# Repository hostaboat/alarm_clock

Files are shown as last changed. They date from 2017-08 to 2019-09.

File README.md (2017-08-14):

# Alarm Clock

## An alarm clock, timer and music player using a Teensy 3.2 and various Adafruit breakout boards.

Many thanks to: 
* **Paul Stoffregen** for the [Teensy 3.2](https://www.pjrc.com/teensy) development board, supporting code base (from which I used as a reference along with the Freescale documentation) and [command line loader](https://github.com/PaulStoffregen/teensy_loader_cli) program which allowed me to develop and test sans the Arduino IDE.
* **Daniel Garcia** for the [FastLED](http://fastled.io) library from which I borrowed.
* [Adafruit](https://www.adafruit.com) for the various breakout boards used.
* [OSH Park](https://oshpark.com) for providing their community PCB service.
* [Othermachine](https://othermachine.co) for the Othermill used to create the enclosure.

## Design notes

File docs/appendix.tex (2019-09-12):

\part*{Appendix}
%\appendix
%\appendixpage
%\addappheadtotoc

%%%%%%%%%%%%%%%%%%%%%%%%%%%%%%%%%%%%%%%%%%%%%%%%%%%%%%%%%%%%%%%%%%%%%%%%%%%%%%%%
% Hexadecimal
%%%%%%%%%%%%%%%%%%%%%%%%%%%%%%%%%%%%%%%%%%%%%%%%%%%%%%%%%%%%%%%%%%%%%%%%%%%%%%%%
\renewcommand{\thechapter}{A}
\chapter{Hexadecimal} \label{Hexadecimal}

Hexadecimal\footnote{Browse \href{https://en.wikipedia.org/wiki/Hexadecimal}{here}
for a more detailed explanation.} is a base \num{16} numeral system.  It is
composed of \num{16} symbols as opposed to decimal (base \num{10}) which is
composed of \num{10}. The symbols \mono{0-9} in hexadecimal are equivalent to
the same in decimal.  The values \mono{10-15} in hexadecimal are represented by
the letters \mono{A}, \mono{B}, \mono{C}, \mono{D}, \mono{E} and \mono{F} (or
alternatively lower case \mono{a}, \mono{b}, \mono{c}, \mono{d}, \mono{e} and
\mono{f}).

\begin{table}[H]
  \begin{tabu}{ X[3,l,m] X[1,c,m] X[1,c,m] X[1,c,m] X[1,c,m] X[1,c,m] X[1,c,m] }
    \thrule
    \multicolumn{7}{c}{\thb{Hexadecimal Letter Symbols}} \\ \mdrule

    \thbi{Symbol}
      & \mono{A}
      & \mono{B}
      & \mono{C}
      & \mono{D}
      & \mono{E}
      & \mono{F}
    \\ \mrule
    \thbi{Decimal Equivalent}
      & \num{10}
      & \num{11}
      & \num{12}
      & \num{13}
      & \num{14}
      & \num{15}
    \\ \mrule
    \thbi{Display}
      & \sDls{A}
      & \sDls{b}
      & \sDls{C}
      & \sDls{d}
      & \sDls{E}
      & \sDls{F}
    \\ \mrule
  \end{tabu}
\end{table}

Some settings use hexadecimal since the \cDi{f} is limited to four digits
and a larger number can be represented using fewer digits in hexadecimal. The
maximum decimal number that can be represented with \num{4} digits is
\num{9999} whereas the maximum hexadecimal is \num{65535}.  There are also
cases where \num{2} digits are used during configuration - in this case the
maximum is \num{99} for decimal and \num{255} for hexadecimal.

\begin{table}[H]
  \centering
  \begin{tabu}{ X[11,l,m] X[9,r,m] X[9,r,m] X[9,r,m] X[9,r,m] }
    \thrule
    \multicolumn{5}{c}{\thb{Maximum Values per Number of Digits}} \\ \mdrule
    \textit{Number of Digits} & \num{1} & \num{2} & \num{3} & \num{4} \\ \mrule
    \textit{Decimal} & \num{9} & \num{99} & \num{999} & \num{9999} \\ \drule{5}
    \textit{Hexadecimal} & \mono{F} = \num{15} & \mono{FF} = \num{255}
      & \mono{FFF} = \num{4095} & \mono{FFFF} = \num{65535} \\
    \bhrule
  \end{tabu}
  \caption{Maximum Decimal and Hexadecimal Values per Number of Digits}
\end{table}

To determine the value of a number, you can multiply the digit by the base to
the power of the digit position minus 1 and add up the results.

\begin{equation}
  \sum_{n=1}^{Digits} Digit[n] \times Base^{n-1}
\end{equation}

\par\medskip

In decimal you have the 1's ($10^{0}$), 10's ($10^{1}$), 100's ($10^{2}$),
1000's ($10^{3}$), 10000's ($10^{4}$), etc. columns or digit positions, and
in hexadecimal you have 1's ($16^{0}$), 16's ($16^{1}$), 256's ($16^{2}$),
4096's ($16^{3}$), etc. columns / digit positions.  Take for example, the
decimal number \num{25341$_{10}$}.\footnote{A subscript attached to a number is used
to denote the base of that number.} The hexadecimal equivalent is
\num{62FD$_{16}$} and can be converted to decimal.

\begin{table}[H]
  \centering
  \begin{tabu}{ X[1,c,m] | X[2,r,m] | X[3,r,m] | X[3,r,m] | X[2,r,m] }
    \thrule
    \multicolumn{5}{c}{\thb{Hexadecimal \num{62FD$_{16}$}
      $\longrightarrow$ Decimal \num{25341$_{10}$}}} \\
    \mrule
    $n$ & $Digit[n]$ & $Base^{n-1}$ & $Digit[n] \times Base^{n-1}$ & Result \\
    \mrule
    1 & D $=$ 13 & $16^{1-1} = 16^{0} = 1$ & $13 \times 1$ & 13 \\ \drule{5}
    2 & F $=$ 15 & $16^{2-1} = 16^{1} = 16$ & $15 \times 16$ & 240 \\ \drule{5}
    3 & 2 & $16^{3-1} = 16^{2} = 256$ & $2 \times 256$ & 512 \\ \drule{5}
    4 & 6 & $16^{4-1} = 16^{3} = 4096$ & $6 \times 4096$ & 24576 \\
    \mrule
    \multicolumn{4}{r|}{\thi{Total}} & 25341 \\
    \bhrule
  \end{tabu}
\end{table}

The number \num{25341$_{10}$} can only be shown on the \cDi{f} using hexadecimal
notation and will look like the following.

\begin{center}
  \sDl{62FD}
\end{center}

%%%%%%%%%%%%%%%%%%%%%%%%%%%%%%%%%%%%%%%%%%%%%%%%%%%%%%%%%%%%%%%%%%%%%%%%%%%%%%%%
% Display Numbers & Letters
%%%%%%%%%%%%%%%%%%%%%%%%%%%%%%%%%%%%%%%%%%%%%%%%%%%%%%%%%%%%%%%%%%%%%%%%%%%%%%%%
\renewcommand{\thechapter}{B}
\chapter{Display Numbers \& Letters} \label{Display Digits}

%%%%%%%%%%%%%%%%%%%%%%%%%%%%%%%%%%%%%%%%%%%%%%%%%%%%%%%%%%%%%%%%%%%%%%%%%%%%%%%%
% Display Numbers & Letters - Numbers
%%%%%%%%%%%%%%%%%%%%%%%%%%%%%%%%%%%%%%%%%%%%%%%%%%%%%%%%%%%%%%%%%%%%%%%%%%%%%%%%
\section{Numbers}

\ers{3}
\begin{longtabu}{ X[1,c,m] X[1,c,m] X[1,c,m] }
  \thrule

  \thbi{Number} & \thbi{Decimal} & \thbi{Hexadecimal} \\ \mrule

  \Large\num{0} & \sDls{0} & \sDls{0} \\ \drule{3}
  \Large\num{1} & \sDls{1} & \sDls{1} \\ \drule{3}
  \Large\num{2} & \sDls{2} & \sDls{2} \\ \drule{3}
  \Large\num{3} & \sDls{3} & \sDls{3} \\ \drule{3}
  \Large\num{4} & \sDls{4} & \sDls{4} \\ \drule{3}
  \Large\num{5} & \sDls{5} & \sDls{5} \\ \drule{3}
  \Large\num{6} & \sDls{6} & \sDls{6} \\ \drule{3}
  \Large\num{7} & \sDls{7} & \sDls{7} \\ \drule{3}
  \Large\num{8} & \sDls{8} & \sDls{8} \\ \drule{3}
  \Large\num{9} & \sDls{9} & \sDls{9} \\ \drule{3}
  \Large\num{10} & --- & \sDls{A} \\ \drule{3}
  \Large\num{11} & --- & \sDls{b} \\ \drule{3}
  \Large\num{12} & --- & \sDls{C} \\ \drule{3}
  \Large\num{13} & --- & \sDls{d} \\ \drule{3}
  \Large\num{14} & --- & \sDls{E} \\ \drule{3}
  \Large\num{15} & --- & \sDls{F} \\

  \bhrule
  \caption{Number Display Representations}
\end{longtabu}

\par\bigskip
\par\bigskip
\par\bigskip

%%%%%%%%%%%%%%%%%%%%%%%%%%%%%%%%%%%%%%%%%%%%%%%%%%%%%%%%%%%%%%%%%%%%%%%%%%%%%%%%
% Display Numbers & Letters - Letters
%%%%%%%%%%%%%%%%%%%%%%%%%%%%%%%%%%%%%%%%%%%%%%%%%%%%%%%%%%%%%%%%%%%%%%%%%%%%%%%%
\section{Letters}

\begin{longtabu}{ X[1,c,m] X[1,c,m] X[1,c,m] }
  \thrule

  \thbi{Letter} & \thbi{Upper Case} & \thbi{Lower Case} \\ \mrule

  \large\mono{A} / \large\mono{a} & \sDls{A} & --- \\ \drule{3}
  \large\mono{B} / \large\mono{b} & --- & \sDls{b} \\ \drule{3}
  \large\mono{C} / \large\mono{c} & \sDls{C} & \sDls{c} \\ \drule{3}
  \large\mono{D} / \large\mono{d} & --- & \sDls{d} \\ \drule{3}
  \large\mono{E} / \large\mono{e} & \sDls{E} & --- \\ \drule{3}
  \large\mono{F} / \large\mono{f} & \sDls{F} & --- \\ \drule{3}
  \large\mono{G} / \large\mono{g} & --- & \sDls{g} \\ \drule{3}
  \large\mono{H} / \large\mono{h} & \sDls{H} & \sDls{h} \\ \drule{3}
  \large\mono{I} / \large\mono{i} & \sDls{I} & \sDls{i} \\ \drule{3}
  \large\mono{J} / \large\mono{j} & \sDls{J} & --- \\ \drule{3}
  \large\mono{K} / \large\mono{k} & --- & --- \\ \drule{3}
  \large\mono{L} / \large\mono{l} & \sDls{L} & \sDls{l} \\ \drule{3}
  \large\mono{M} / \large\mono{m} & --- & --- \\ \drule{3}
  \large\mono{N} / \large\mono{n} & --- & \sDls{n} \\ \drule{3}
  \large\mono{O} / \large\mono{o} & \sDls{O} & \sDls{o} \\ \drule{3}
  \large\mono{P} / \large\mono{p} & \sDls{P} & --- \\ \drule{3}
  \large\mono{Q} / \large\mono{q} & --- & --- \\ \drule{3}
  \large\mono{R} / \large\mono{r} & --- & \sDls{r} \\ \drule{3}
  \large\mono{S} / \large\mono{s} & \sDls{S} & --- \\ \drule{3}
  \large\mono{T} / \large\mono{t} & --- & \sDls{t} \\ \drule{3}
  \large\mono{U} / \large\mono{u} & \sDls{U} & \sDls{u} \\ \drule{3}
  \large\mono{V} / \large\mono{v} & --- & --- \\ \drule{3}
  \large\mono{W} / \large\mono{w} & --- & --- \\ \drule{3}
  \large\mono{X} / \large\mono{x} & --- & --- \\ \drule{3}
  \large\mono{Y} / \large\mono{y} & --- & \sDls{y} \\ \drule{3}
  \large\mono{Z} / \large\mono{z} & --- & --- \\

  \bhrule
  \caption{Letter Display Representations}
\end{longtabu}

%%%%%%%%%%%%%%%%%%%%%%%%%%%%%%%%%%%%%%%%%%%%%%%%%%%%%%%%%%%%%%%%%%%%%%%%%%%%%%%%
% Parts & Materials
%%%%%%%%%%%%%%%%%%%%%%%%%%%%%%%%%%%%%%%%%%%%%%%%%%%%%%%%%%%%%%%%%%%%%%%%%%%%%%%%
\renewcommand{\thechapter}{C}
\chapter{Parts \& Materials}

Two tables are listed below, the first organized by \textit{type} and the
second by \textit{application}.

%%%%%%%%%%%%%%%%%%%%%%%%%%%%%%%%%%%%%%%%%%%%%%%%%%%%%%%%%%%%%%%%%%%%%%%%%%%%%%%%
% Parts & Materials - Type
%%%%%%%%%%%%%%%%%%%%%%%%%%%%%%%%%%%%%%%%%%%%%%%%%%%%%%%%%%%%%%%%%%%%%%%%%%%%%%%%
\section{By Type}

\tiny
\ers{1}
\begin{longtabu}{X[1,c,m] X[6,c,m] X[9,l,m]}
  \thrule
  \textit{\bfseries\normalsize Qty} & \textit{\bfseries\normalsize Part} & \textit{\bfseries\normalsize Description} \\ \mrule

  1 & OSH Park - CTP Main & Main circuit board \\
  1 & OSH Park - CTP Potentiometer & Potentiometer circuit board \\
  1 & OSH Park - CTP NeoPixels & NeoPixel circuit board \\
  1 & OSH Park - CTP USB & USB circuit board \\ \mrule

  1 & Teensy 3.2 & Teensy 3.2 USB Development Board, 72MHz Cortex-M4 (96MHz Overclock) - FreeScale MK20DX256VLH7 \\
  1 & Adafruit 2465 & PowerBoost 1000 Charger - Rechargeable 5V Lipo USB Boost @ 1A - 1000C \\
  1 & Adafruit 1381 & VS1053 Codec + MicroSD Breakout - MP3/WAV/MIDI/OGG Play + Record - v4 \\
  1 & Adafruit 987 & Stereo 3.7W Class D Audio Amplifier - MAX98306 \\
  2 & Adafruit 1426 & NeoPixel Stick 8 x 5050 RGB LED with Integrated Drivers \\
  1 & Adafruit 1002 & White 0.56" 4-Digit 7-Segment Display w/ I2C Backpack \\
  1 & Adafruit 757 & 4-Channel I2C Bi-directional Logic Level Converter - BSS138 \\
  1 & Adafruit 1870 & 20mm Coin Cell Breakout Board (CR2032) \\ \mrule

  1 & Atmel ATtiny13A-PU & ATtiny13A 8-bit AVR RISC Microcontroller \\
  1 & Texas Instruments SN74AHCT125N & Quad Bus Buffer Gate, 3-State Output, 4 Circuit, 4.5V-5.5V \\
  1 & Texas Instruments SN74AHC14N & Hex Schmitt-Trigger Inverter 6 Circuit 2V-5.5V \\ \mrule

  2 & CUI Inc. GF0876 & 8$\Omega$ 2W 99dB Speaker \\
  1 & Mallory Sonalert PB-12N23P-03Q & Magnetic Buzzer 85dBA, 2.3kHz, 3VDC, 30mA, 12mm \\ \mrule

  1 & Citizen Finedevice Co Ltd CFS-20632768HZFB & Crystal 32.768kHz 12.5pF, $\pm$5ppm Tolerance \\
  1 & Adafruit 297 & Super Bright Red 5mm LED \\
  1 & Murata Electronics BNX002-01 & EMI Filter 50V 10A 1MHz to 1GHz \\
  4 & Murata RDE5C1H103J1P1H03B & Multilayer Ceramic Capacitor 10nF 50V $\pm$5\% C0G(NP0) \\
  3 & Kemet C324C104J5R5TA & Multilayer Ceramic Capacitor 0.1uF 50V $\pm$5\% X7R \\
  4 & Fairchild 1N4148 & Diode 100V 4A \\
  1 & Multicomp MF25 330R & Metal Film Resistor 330$\Omega$ 250mW $\pm$1\% \\
  1 & Multicomp MF25 1K & Metal Film Resistor 1k$\Omega$ 250mW $\pm$1\% \\
  8 & Multicomp MF25 200K & Metal Film Resistor 200k$\Omega$ 250mW $\pm$1\% \\ \mrule

  1 & Adafruit 1995 & 5V (5.25V) 2.4A Switching Power Supply w/ 20AWG MicroUSB Cable \\
  1 & Adafruit 353 & Lithium Ion Battery Pack - 3.7V 6600mAh \\
  1 & CR2032 & CR2032 Lithium Coin Cell Battery \\ \mrule

  1 & Grayhill 44A90-01-1-03N & Rotary Switch, Solder Lug, 90°, 1 Deck, 1 Pole/Deck, 3 Positions/Pole, Non-Shorting \\
  1 & Bourns EM14A1D-C24-L032S & Rotary Encoder w/ Switch, Optical, Incremental, 32 PPR, 32 Detent, 2 Channel, Quadrature \\
  1 & Bourns EM14A0D-C24-L064S & Rotary Encoder w/ Switch, Optical, Incremental, 64 PPR, No Detent, 2 Channel, Quadrature \\
  1 & Bourns 91A2A-B28-D15/D15L & Potentiometer, Dual Gang, 10k$\Omega$, CW Audio C-P $\pm$20\%, Plastic Single Slotted 1/4" Wide, 7/8" Long Shaft \\
  3 & E-Switch RP3502MABLK & SPST NO Momentary OFF-(ON) 1.5A Solder Pin \\
  1 & Adafruit 917 & Rugged Metal On/Off Switch with White LED Ring, 16mm, 3-6V \\
  1 & Amphenol MUSB-K152-30 & USB Micro-AB Connector 1.8A \\ \mrule

  1 & Grayhill 11K5028-KMNB & Dial, 0.71" Dia. 1.09" Long, 0.25" dia. shaft, Nylon, Metal Insert w/ Set Screws \\
  1 & Grayhill 11K5014-KMNB & Knob, 0.7" Dia., 0.25" dia. shaft, Nylon, Metal Insert w/ Set Screws \\
  1 & Grayhill 11K5029-KMNB & Knob, 0.5" Dia., 0.25" dia. shaft, Nylon, Metal Insert w/ Set Screws \\
  1 & Grayhill 11K5015-KMNB & Knob, 0.5" Dia. 0.894" Dia. Sleeve, 0.25" dia. shaft, Nylon, Metal Insert w/ Set Screws \\ \mrule

  2 & Bourns H-290-1 & Ribbon Cable, 6 Position 28 AWG, Molex Mini Mi II Female (54596-0610) \\
  1 & 3M 8125/06 100 & 6 Conductor 0.1"/2.54mm Pitch 24AWG 7x32 Stranded Tinned Copper PVC Insulation Unshielded 300V \\
  1 & 3M 3811/10 300 & 10 Conductor 0.05"/1.27mm Pitch 26AWG 7x34 Stranded Tinned Copper PVC Insulation Unshielded 300V \\
  2 & Belden 8442 060100 & 2 Conductor 22AWG 7x30 Stranded Tinned Copper PVC Insulation Unshielded 300V \\
  1 & Alpha Wire 3050 BK005 & Black 1 Conductor 24AWG 7x32 Stranded Tinned Copper PVC Insulation 300V \\
  1 & Alpha Wire 3050 RD005 & Red 1 Conductor 24AWG 7x32 Stranded Tinned Copper PVC Insulation 300V \\
  1 & Consolidated 818 & 1 Conductor 22 AWG 7x30 Stranded Tinned Copper PVC Insulation 300V \\ \mrule

  5 & Adafruit 598 & 36-pin 0.1" Female Header \\
  2 & 3M 11-8-NB & Ring Terminal, Nylon Insulated, 18-22AWG, No. 8 Screw \\
  1 & Molex 55454-0670 & Mini Mi II - Right Angle \\
  1 & Molex 55447-0670 & Mini Mi II - Straight \\
  4 & JST PHR-2 & Housing PH 2mm 2 Position \\
  4 & JST B2B-PH-K-S(LF)(SN) & Header PH Top 2mm 2 Position \\
  8 & JST SPH-002T-P0.5L & Terminal PH Crimp 24-28AWG \\
  2 & JST XHP-2 & Housing XH 2.5mm 2 Position \\
  1 & JST B2B-XH-A(LF)(SN) & Header XH Top 2.5mm 2 Position \\
  1 & JST S2B-XH-A(LF)(SN) & Header XH Side 2.5mm 2 Position \\
  2 & JST XHP-3 & Housing XH 2.5mm 3 Position \\
  2 & JST B3B-XH-A(LF)(SN) & Header XH Top 2.5mm 3 Position \\
  5 & JST XHP-4 & Housing XH 2.5mm 4 Position \\
  4 & JST B4B-XH-A(LF)(SN) & Header XH Top 2.5mm 4 Position \\
  1 & JST S4B-XH-A(LF)(SN) & Housing XH Side 2.5mm 4 Position \\
  2 & JST XHP-5 & Housing XH 2.5mm 5 Position \\
  2 & JST B5B-XH-A(LF)(SN) & Header XH Top 2.5mm 5 Position \\
  39 & JST SXH-001T-P0.6 & Terminal Crimp XH 22-28AWG \\ \mrule

  1 & McMaster-Carr 89015K155 & 6061 Aluminum 6" x 24" x 0.032" \\
  1 & McMaster-Carr 89015K181 & 6061 Aluminum 2" x 24" x 0.063" \\
  1 & McMaster-Carr 8975K418 & 6061 Aluminum, 4" x 12" x 0.125" \\
  1 & McMaster-Carr 8739K96 & White Delrin 5" x 12" x 1/8" \\
  1 & McMaster-Carr 8662K16 & Black Delrin 4" x 12" x 1/8" \\
  1 & McMaster-Carr 8560K275 & Clear Cast Acrylic 6" x 12" x 1/8" \\
  1 & Cook Woods - \wood{} & 6" x 48" x 7/8" \\
  2 & eBay - macgyver2258 - 130701086245 & Perforated 304 Stainless Steel 1/32" hole, 24 Gauge \\ \mrule

  1 & Liberon Shellac Flakes & Blonde Dewaxed Shellac Flakes 250g \\
  1 & Behlen B650-2816 & Behkol Solvent - Denatured Alcohol Blend \\
  1 & McMaster-Carr 7719T16 & Gray Primer Rust-Oleum Industrial Choice Multi-Purpose Spray Paint \\
  1 & McMaster-Carr 7719T11 & Black Gloss Rust-Oleum Industrial Choice Multi-Purpose Spray Paint \\ \mrule

  4 & McMaster-Carr 91735A103 & 316 Stainless Steel Pan Head Phillips Screws, 5/16" Long, 4-40 Thread Size \\
  8 & McMaster-Carr 91251A113 & Black-Oxide Alloy Steel Socket Head Screw, 4-40 Thread Size, 3/4" Long \\
  10 & McMaster-Carr 93705A112 & 18-8 Stainless Steel Thread-Locking Socket Head Screw, 1/4" Long, 2-56 Thread Size \\
  4 & McMaster-Carr 91772A077 & 18-8 Stainless Steel Phillips Rounded Head Screw, 1/4" Long, 2-56 Thread Size \\
  4 & McMaster-Carr 91772A080 & 18-8 Stainless Steel Phillips Rounded Head Screw, 7/16" Long, 2-56 Thread Size \\
  4 & McMaster-Carr 91772A051 & 18-8 Stainless Steel Phillips Rounded Head Screw, 5/32" Long, 0-80 Thread Size \\
  4 & McMaster-Carr 91772A054 & 18-8 Stainless Steel Phillips Rounded Head Screw, 3/16" Long, 0-80 Thread Size \\
  9 & McMaster-Carr 91772A190 & 18-8 Stainless Steel Pan Head Phillips Screws, 1/4" Long, 8-32 Thread Size \\
  2 & McMaster-Carr 91735A197 & 316 Stainless Steel Pan Head Phillips Screws, 3/4" Long, 8-32 Thread Size \\
  8 & McMaster-Carr 91735A192 & 316 Stainless Steel Pan Head Phillips Screws, 3/8" Long, 8-32 Thread size \\

  4 & McMaster-Carr 92510A030 & Aluminum Unthreaded Spacer, 1/4" OD, 5/32" Long, No. 4 Screw \\
  6 & McMaster-Carr 91780A030 & Aluminum Female Threaded Hex Standoff, 1/8" Hex, 7/16" Long, 2-56 Thread Size \\
  4 & McMaster-Carr 91780A020 & Aluminum Female Threaded Hex Standoff, 1/8" Hex, 3/16" Long, 0-80 Thread Size \\

  25 & McMaster-Carr 90133A009 & Oil-Resistant Neoprene Rubber Sealing Washer for Number 8 Screw Size, 0.15" ID, 0.312" OD \\
  4 & McMaster-Carr 90107A005 & 316 Stainless Steel Washer, Number 4 Screw Size, 0.125" ID, 0.312" OD \\
  6 & McMaster-Carr 98449A500 & 400 Series Stainless Steel Internal-Tooth Lock Washer, Number 2 Screw Size, 0.089" ID, 0.2" OD \\
  4 & McMaster-Carr 92146A510 & 18-8 Stainless Steel Split Lock Washer, Number 0 Screw Size, 0.062" ID, 0.137" OD \\

  4 & McMaster-Carr 91841A003 & 18-8 Stainless Steel Hex Nut, 2-56 Thread Size \\

  1 & McMaster-Carr 1376N23 & Multipurpose Neoprene Rubber Strip w/ Adhesive Back, 1/16" Thick, 50A Durometer, 2"x36" \\
  2 & McMaster-Carr 94115K338 & Water-Resistant Neoprene O-Ring, Number 338, 3/16 width \\
  1 & Adafruit 2177 & 5mm Chromed Metal Wide Convex Bevel LED Holder \\

  \bhrule
\caption{Parts \& Materials by Type}
\end{longtabu}

%%%%%%%%%%%%%%%%%%%%%%%%%%%%%%%%%%%%%%%%%%%%%%%%%%%%%%%%%%%%%%%%%%%%%%%%%%%%%%%%
% Parts & Materials - Application
%%%%%%%%%%%%%%%%%%%%%%%%%%%%%%%%%%%%%%%%%%%%%%%%%%%%%%%%%%%%%%%%%%%%%%%%%%%%%%%%
\pagebreak
\section{By Application}

\tiny
\ers{1.5}
\begin{longtabu}{X[3,c,m] X[1,c,m] X[3,c,m] X[5,l,m]}
  \thrule
  \textit{\bfseries\normalsize Application} & \textit{\bfseries\normalsize Qty} & \textit{\bfseries\normalsize Part} & \textit{\bfseries\normalsize Description} \\ \mrule

  \multirow{9}{*}{\cEn{ss}} & 1 & McMaster-Carr 89015K155 & 6061 Aluminum 5.5" x 4.5" x 0.032" \\
  & 1 & McMaster-Carr 8739K96 & White Delrin 5.5" x 4.5" x 1/8" \\
  & 1 & McMaster-Carr 8560K275 & Clear Cast Acrylic 5.5" x 4.5" x 1/8" \\
  & 2 & Cook Woods - \wood{} & Sides - 4.5" x 5.5" x 3/4" \\
  & 2 & Cook Woods - \wood{} & Top \& Bottom - 4.5" x 5.25" x 3/4" \\
  & 1 & Cook Woods - \wood{} & Back - 4.5" x 5.5" x 1/4" \\
  & 1 & Liberon Shellac Flakes & Blonde Dewaxed Shellac Flakes 250g \\
  & 1 & Behlen B650-2816 & Behkol Solvent - Denatured Alcohol Blend \\
  & 8 & McMaster-Carr 91251A113 & Black-Oxide Alloy Steel Socket Head Screw, 4-40 Thread Size, 3/4" Long \\ \mrule

  \multirow{4}{*}{\cCB{ss}} & 1 & OSH Park - CTP Main & Main circuit board \\
  & 4 & McMaster-Carr 92510A030 & Aluminum Unthreaded Spacer, 1/4" OD, 5/32" Long, No. 4 Screw \\
  & 4 & McMaster-Carr 91735A103 & 316 Stainless Steel Pan Head Phillips Screws, 5/16" Long, 4-40 Thread Size \\
  & 4 & McMaster-Carr 90107A005 & 316 Stainless Steel Washer, Number 4 Screw Size, 0.125" ID, 0.312" OD \\ \mrule

  \multirow{3}{*}{\cMi{ss}} & 1 & Teensy 3.2 & Teensy 3.2 USB Development Board, 72MHz Cortex-M4 (96MHz Overclock) - FreeScale MK20DX256VLH7 \\
  & 1 & Citizen Finedevice Co Ltd CFS-20632768HZFB & Crystal 32.768kHz 12.5pF, $\pm$5ppm Tolerance \\
  & 1 & Adafruit 598 & 36-pin 0.1" Female Header \\ \mrule

  \multirow{6}{*}{\cRs{ss}} & 1 & Grayhill 44A90-01-1-03N & Rotary Switch, Solder Lug, 90°, 1 Deck, 1 Pole/Deck, 3 Positions/Pole, Non-Shorting \\
  & 1 & Grayhill 11K5028-KMNB & Dial, 0.71" Dia. 1.09" Long, 0.25" dia. shaft, Nylon, Metal Insert w/ Set Screws \\
  & 1 & 3M 8125/06 100 & 4 of 6 Conductor 0.1"/2.54mm Pitch 24AWG 7x32 Stranded Tinned Copper PVC Insulation Unshielded 300V \\
  & 1 & JST XHP-4 & Housing XH 2.5mm 4 Position \\
  & 1 & JST B4B-XH-A(LF)(SN) & Header XH Top 2.5mm 4 Position \\
  & 4 & JST SXH-001T-P0.6 & Terminal Crimp XH 22-28AWG \\ \mrule

  \multirow{4}{*}{\cEs{ss}} & 1 & Bourns EM14A1D-C24-L032S & Rotary Encoder w/ Switch, Optical, Incremental, 32 PPR, 32 Detent, 2 Channel, Quadrature \\
  & 1 & Grayhill 11K5014-KMNB & Knob, 0.7" Dia., 0.25" dia. shaft, Nylon, Metal Insert w/ Set Screws \\
  & 1 & Bourns H-290-1 & Ribbon Cable, 6 Position 28 AWG, Molex Mini Mi II Female (54596-0610) \\
  & 1 & Molex 55454-0670 & Mini Mi II - Right Angle \\ \mrule

  \multirow{4}{*}{\cBr{ss}} & 1 & Bourns EM14A0D-C24-L064S & Rotary Encoder w/ Switch, Optical, Incremental, 64 PPR, No Detent, 2 Channel, Quadrature \\
  & 1 & Grayhill 11K5029-KMNB & Knob, 0.5" Dia., 0.25" dia. shaft, Nylon, Metal Insert w/ Set Screws \\
  & 1 & Bourns H-290-1 & Ribbon Cable, 6 Position 28 AWG, Molex Mini Mi II Female (54596-0610) \\
  & 1 & Molex 55447-0670 & Mini Mi II - Straight \\ \mrule

  \multirow{7}{*}{\cVo{ss}} & 1 & Bourns 91A2A-B28-D15/D15L & Potentiometer, Dual Gang, 10k$\Omega$, CW Audio C-P $\pm$20\%, Plastic Single Slotted 1/4" Wide, 7/8" Long Shaft \\
  & 1 & OSH Park - CTP Potentiometer & Potentiometer circuit board \\
  & 1 & Grayhill 11K5015-KMNB & Knob, 0.5" Dia. 0.894" Dia. Sleeve, 0.25" dia. shaft, Nylon, Metal Insert w/ Set Screws \\
  & 1 & 3M 8125/06 100 & 5 of 6 Conductor 0.1"/2.54mm Pitch 24AWG 7x32 Stranded Tinned Copper PVC Insulation Unshielded 300V \\
  & 2 & JST XHP-5 & Housing XH 2.5mm 5 Position \\
  & 2 & JST B5B-XH-A(LF)(SN) & Header XH Top 2.5mm 5 Position \\
  & 10 & JST SXH-001T-P0.6 & Terminal Crimp XH 22-28AWG \\ \mrule

  \multirow{2}{*}{\cAD{ss}} & 1 & Adafruit 1381 & VS1053 Codec + MicroSD Breakout - MP3/WAV/MIDI/OGG Play + Record - v4 \\
  & 1 & Adafruit 598 & 36-pin 0.1" Female Header \\ \mrule

  \multirow{5}{*}{\cAm{ss}} & 1 & Adafruit 987 & Stereo 3.7W Class D Audio Amplifier - MAX98306 \\
  & 1 & Adafruit 598 & 36-pin 0.1" Female Header \\
  & 1 & Multicomp MF25 1K & Metal Film Resistor 1k$\Omega$ 250mW $\pm$1\% \\
  & 2 & McMaster-Carr 91780A030 & Aluminum Female Threaded Hex Standoff, 1/8" Hex, 7/16" Long, 2-56 Thread Size \\
  & 4 & McMaster-Carr 93705A112 & 18-8 Stainless Steel Thread-Locking Socket Head Screw, 1/4" Long, 2-56 Thread Size \\ \mrule

  \multirow{9}{*}{\cSp{ss}} & 2 & CUI Inc. GF0876 & 8$\Omega$ 2W 99dB Speaker \\
  & 2 & Belden 8442 060100 & 2 Conductor 22AWG 7x30 Stranded Tinned Copper PVC Insulation Unshielded 300V \\
  & 1 & McMaster-Carr 8975K418 & 6061 Aluminum, 4" x 12" x 0.125" \\
  & 2 & McMaster-Carr 94115K338 & Water-Resistant Neoprene O-Ring, Number 338, 3/16 width \\
  & 8 & McMaster-Carr 91735A192 & 316 Stainless Steel Pan Head Phillips Screws, 3/8" Long, 8-32 Thread size \\
  & 16 & McMaster-Carr 90133A009 & Oil-Resistant Neoprene Rubber Sealing Washer for Number 8 Screw Size, 0.15" ID, 0.312" OD \\
  & 2 & eBay - macgyver2258 - 130701086245 & Perforated 304 Stainless Steel 1/32" hole, 24 Gauge \\
  & 1 & McMaster-Carr 7719T16 & Gray Primer Rust-Oleum Industrial Choice Multi-Purpose Spray Paint \\
  & 1 & McMaster-Carr 7719T11 & Black Gloss Rust-Oleum Industrial Choice Multi-Purpose Spray Paint \\ \mrule

  \multirow{5}{*}{\cPl{ss}} & 1 & E-Switch RP3502MABLK & SPST NO Momentary OFF-(ON) 1.5A Solder Pin \\
  & 1 & 3M 3811/10 300 & 2 of 10 Conductor 0.05"/1.27mm Pitch 26AWG 7x34 Stranded Tinned Copper PVC Insulation Unshielded 300V \\
  & 1 & JST PHR-2 & Housing PH 2mm 2 Position \\
  & 1 & JST B2B-PH-K-S(LF)(SN) & Header PH Top 2mm 2 Position \\
  & 2 & JST SPH-002T-P0.5L & Terminal PH Crimp 24-28AWG \\ \mrule

  \multirow{5}{*}{\cNe{ss}} & 1 & E-Switch RP3502MABLK & SPST NO Momentary OFF-(ON) 1.5A Solder Pin \\
  & 1 & 3M 3811/10 300 & 2 of 10 Conductor 0.05"/1.27mm Pitch 26AWG 7x34 Stranded Tinned Copper PVC Insulation Unshielded 300V \\
  & 1 & JST PHR-2 & Housing 2mm 2 Position \\
  & 1 & JST B2B-PH-K-S(LF)(SN) & Header Top 2mm 2 Position \\
  & 2 & JST SPH-002T-P0.5L & Terminal PH Crimp 24-28AWG \\ \mrule

  \multirow{5}{*}{\cPr{ss}} & 1 & E-Switch RP3502MABLK & SPST NO Momentary OFF-(ON) 1.5A Solder Pin \\
  & 1 & 3M 3811/10 300 & 2 of 10 Conductor 0.05"/1.27mm Pitch 26AWG 7x34 Stranded Tinned Copper PVC Insulation Unshielded 300V \\
  & 1 & JST PHR-2 & Housing 2mm 2 Position \\
  & 1 & JST B2B-PH-K-S(LF)(SN) & Header Top 2mm 2 Position \\
  & 2 & JST SPH-002T-P0.5L & Terminal PH Crimp 24-28AWG \\ \mrule

  \multirow{11}{*}{\cDi{ss}} & 1 & Adafruit 1002 & White 0.56" 4-Digit 7-Segment Display w/ I2C Backpack \\
  & 1 & Adafruit 757 & 4-Channel I2C Bi-directional Logic Level Converter - BSS138 \\
  & 1 & Adafruit 598 & 36-pin 0.1" Female Header \\
  & 1 & 3M 8125/06 100 & 4 of 6 Conductor 0.1"/2.54mm Pitch 24AWG 7x32 Stranded Tinned Copper PVC Insulation Unshielded 300V \\
  & 2 & JST XHP-4 & Housing XH 2.5mm 4 Position \\
  & 2 & JST B4B-XH-A(LF)(SN) & Header XH Top 2.5mm 4 Position \\
  & 8 & JST SXH-001T-P0.6 & Terminal Crimp XH 22-28AWG \\
  & 4 & McMaster-Carr 91780A020 & Aluminum Female Threaded Hex Standoff, 1/8" Hex, 3/16" Long, 0-80 Thread Size \\
  & 4 & McMaster-Carr 91772A051 & 18-8 Stainless Steel Phillips Rounded Head Screw, 5/32" Long, 0-80 Thread Size \\
  & 4 & McMaster-Carr 91772A054 & 18-8 Stainless Steel Phillips Rounded Head Screw, 3/16" Long, 0-80 Thread Size \\
  & 4 & McMaster-Carr 92146A510 & 18-8 Stainless Steel Split Lock Washer, Number 0 Screw Size, 0.062" ID, 0.137" OD \\ \mrule

  \multirow{14}{*}{\cLi{ss}} & 2 & Adafruit 1426 & NeoPixel Stick 8 x 5050 RGB LED with Integrated Drivers \\
  & 1 & OSH Park - CTP NeoPixels & NeoPixel circuit board \\
  & 1 & Texas Instruments SN74AHCT125N & Quad Bus Buffer Gate, 3-State Output, 4 Circuit, 4.5V-5.5V \\
  & 1 & Kemet C324C104J5R5TA & Multilayer Ceramic Capacitor 0.1uF 50V $\pm$5\% X7R \\
  & 1 & 3M 8125/06 100 & 3 of 6 Conductor 0.1"/2.54mm Pitch 24AWG 7x32 Stranded Tinned Copper PVC Insulation Unshielded 300V \\
  & 2 & JST XHP-3 & Housing XH 2.5mm 3 Position \\
  & 2 & JST B3B-XH-A(LF)(SN) & Header XH Top 2.5mm 3 Position \\
  & 6 & JST SXH-001T-P0.6 & Terminal Crimp XH 22-28AWG \\
  & 1 & McMaster-Carr 8662K16 & Black Delrin 4" x 12" x 1/8" \\
  & 4 & McMaster-Carr 91772A077 & 18-8 Stainless Steel Phillips Rounded Head Screw, 1/4" Long, 2-56 Thread Size \\
  & 4 & McMaster-Carr 91772A080 & 18-8 Stainless Steel Phillips Rounded Head Screw, 7/16" Long, 2-56 Thread Size \\
  & 2 & McMaster-Carr 91780A030 & Aluminum Female Threaded Hex Standoff, 1/8" Hex, 7/16" Long, 2-56 Thread Size \\
  & 4 & McMaster-Carr 91841A003 & 18-8 Stainless Steel Hex Nut, 2-56 Thread Size \\
  & 6 & McMaster-Carr 98449A500 & 400 Series Stainless Steel Internal-Tooth Lock Washer, Number 2 Screw Size, 0.089" ID, 0.2" OD \\ \mrule

  \multirow{5}{*}{\cPo{ss}} & 1 & Adafruit 917 & Rugged Metal On/Off Switch with White LED Ring, 16mm, 3-6V \\
  & 1 & 3M 8125/06 100 & 4 of 6 Conductor 0.1"/2.54mm Pitch 24AWG 7x32 Stranded Tinned Copper PVC Insulation Unshielded 300V \\
  & 1 & JST XHP-4 & Housing XH 2.5mm 4 Position \\
  & 1 & JST B4B-XH-A(LF)(SN) & Header XH Top 2.5mm 4 Position \\
  & 4 & JST SXH-001T-P0.6 & Terminal Crimp XH 22-28AWG \\ \mrule

  \multirow{8}{*}{\cPP{ss}} & 1 & Amphenol MUSB-K152-30 & USB Micro-AB Connector 1.8A \\
  & 1 & OSH Park - CTP USB & USB circuit board \\
  & 1 & 3M 8125/06 100 & 2 of 6 Conductor 0.1"/2.54mm Pitch 24AWG 7x32 Stranded Tinned Copper PVC Insulation Unshielded 300V \\
  & 2 & JST XHP-2 & Housing XH 2.5mm 2 Position \\
  & 1 & JST B2B-XH-A(LF)(SN) & Header XH Top 2.5mm 2 Position \\
  & 1 & JST S2B-XH-A(LF)(SN) & Header XH Side 2.5mm 2 Position \\
  & 4 & JST SXH-001T-P0.6 & Terminal Crimp XH 22-28AWG \\
  & 2 & McMaster-Carr 93705A112 & 18-8 Stainless Steel Thread-Locking Socket Head Screw, 1/4" Long, 2-56 Thread Size \\ \mrule

  \cPA{ss} & 1 & Adafruit 1995 & 5V (5.25V) 2.4A Switching Power Supply w/ 20AWG MicroUSB Cable \\ \mrule

  \multirow{5}{*}{\cRB{ss}} & 1 & Adafruit 353 & Lithium Ion Battery Pack - 3.7V 6600mAh \\
  & 1 & McMaster-Carr 1376N23 & Multipurpose Neoprene Rubber Strip w/ Adhesive Back, 1/16" Thick, 50A Durometer, 2"x36" \\
  & 1 & McMaster-Carr 89015K181 & 6061 Aluminum 2" x 3 3/4" x 1/16" \\
  & 2 & McMaster-Carr 91735A197 & 316 Stainless Steel Pan Head Phillips Screws, 3/4" Long, 8-32 Thread Size \\
  & 2 & McMaster-Carr 90133A009 & Oil-Resistant Neoprene Rubber Sealing Washer for Number 8 Screw Size, 0.15" ID, 0.312" OD \\ \mrule

  \multirow{5}{*}{\cPS{ss}} & 1 & Adafruit 2465 & PowerBoost 1000 Charger - Rechargeable 5V Lipo USB Boost @ 1A - 1000C \\
  & 1 & Adafruit 598 & 36-pin 0.1" Female Header \\
  & 1 & Murata Electronics BNX002-01 & EMI Filter 50V 10A 1MHz to 1GHz \\
  & 2 & McMaster-Carr 91780A030 & Aluminum Female Threaded Hex Standoff, 1/8" Hex, 7/16" Long, 2-56 Thread Size \\
  & 4 & McMaster-Carr 93705A112 & 18-8 Stainless Steel Thread-Locking Socket Head Screw, 1/4" Long, 2-56 Thread Size \\ \mrule

  \multirow{9}{*}{\cLB{ss}} & 1 & Adafruit 297 & Super Bright Red 5mm LED \\
  & 1 & Multicomp MF25 330R & Metal Film Resistor 330$\Omega$ 250mW $\pm$1\% \\
  & 1 & Adafruit 2177 & 5mm Chromed Metal Wide Convex Bevel LED Holder \\
  & 1 & 3M 3811/10 300 & 2 of 10 Conductor 0.05"/1.27mm Pitch 26AWG 7x34 Stranded Tinned Copper PVC Insulation Unshielded 300V \\
  & 1 & JST PHR-2 & Housing 2mm 2 Position \\
  & 1 & JST B2B-PH-K-S(LF)(SN) & Header Top 2mm 2 Position \\
  & 2 & JST SPH-002T-P0.5L & Terminal PH Crimp 24-28AWG \\
  & 1 & Atmel ATtiny13A-PU & ATtiny13A 8-bit AVR RISC Microcontroller \\
  & 1 & Kemet C324C104J5R5TA & Multilayer Ceramic Capacitor 0.1uF 50V $\pm$5\% X7R \\ \mrule

  \cBe{ss} & 1 & Mallory Sonalert PB-12N23P-03Q & Magnetic Buzzer 85dBA, 2.3kHz, 3VDC, 30mA, 12mm \\ \mrule

  \multirow{7}{*}{\cCC{ss}} & 1 & CR2032 & CR2032 Lithium Coin Cell Battery \\
  & 1 & Adafruit 1870 & 20mm Coin Cell Breakout Board (CR2032) \\
  & 1 & Alpha Wire 3050 BK005 & Black 1 Conductor 24AWG 7x32 Stranded Tinned Copper PVC Insulation 300V \\
  & 1 & Alpha Wire 3050 RD005 & Red 1 Conductor 24AWG 7x32 Stranded Tinned Copper PVC Insulation 300V \\
  & 1 & JST XHP-4 & Housing XH 2.5mm 4 Position \\
  & 1 & JST S4B-XH-A(LF)(SN) & Housing XH Side 2.5mm 4 Position \\
  & 2 & JST SXH-001T-P0.6 & Terminal Crimp XH 22-28AWG \\ \mrule

  \multirow{7}{*}{\cTS{ss}} & 1 & 6061 Aluminum & 2"x2", 0.032" Thick - Electrode \\
  & 1 & 6061 Aluminum & 3.25"x3.25", 0.032" Thick - Ground Ring \\
  & 1 & Consolidated 818 & 1 Conductor 22 AWG 7x30 Stranded Tinned Copper PVC Insulation 300V \\
  & 2 & 3M 11-8-NB & Ring Terminal, Nylon Insulated, 18-22AWG, No. 8 Screw \\
  & 1 & JST SXH-001T-P0.6 & Terminal Crimp XH 22-28AWG \\
  & 9 & McMaster-Carr 91772A190 & 18-8 Stainless Steel Pan Head Phillips Screws, 1/4" Long, 8-32 Thread Size \\
  & 7 & McMaster-Carr 90133A009 & Oil-Resistant Neoprene Rubber Sealing Washer for Number 8 Screw Size, 0.15” ID, 0.312” OD \\ \mrule

  \multirow{5}{*}{\control{ss}{SWITCH DEBOUNCE}} & 1 & Texas Instruments SN74AHC14N & Hex Schmitt-Trigger Inverter 6 Circuit 2V-5.5V \\
  & 1 & Kemet C324C104J5R5TA & Multilayer Ceramic Capacitor 0.1uF 50V $\pm$5\% X7R \\
  & 4 & Murata RDE5C1H103J1P1H03B & Multilayer Ceramic Capacitor 10nF 50V $\pm$5\% C0G(NP0) \\
  & 4 & Fairchild 1N4148 & Diode 100V 4A \\
  & 8 & Multicomp MF25 200K & Metal Film Resistor 200k$\Omega$ 250mW $\pm$1\% \\

  \bhrule
\caption{Parts \& Materials by Application}
\end{longtabu}

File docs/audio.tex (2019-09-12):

%%%%%%%%%%%%%%%%%%%%%%%%%%%%%%%%%%%%%%%%%%%%%%%%%%%%%%%%%%%%%%%%%%%%%%%%%%%%%%%%
% Audio
%%%%%%%%%%%%%%%%%%%%%%%%%%%%%%%%%%%%%%%%%%%%%%%%%%%%%%%%%%%%%%%%%%%%%%%%%%%%%%%%
\chapter{Audio} \label{Audio}
\vspace{-10ex}\mAu{syml}\vskip 8ex

%%%%%%%%%%%%%%%%%%%%%%%%%%%%%%%%%%%%%%%%%%%%%%%%%%%%%%%%%%%%%%%%%%%%%%%%%%%%%%%%
% Introduction
%%%%%%%%%%%%%%%%%%%%%%%%%%%%%%%%%%%%%%%%%%%%%%%%%%%%%%%%%%%%%%%%%%%%%%%%%%%%%%%%
\section{Introduction}

The left side of the front panel is devoted to \mAu{f} playback and control.
Its functionality is available at all times independent of any mode the device
may be in\footnote{ One exception is during touch calibration - see
\hyperref[Touch Settings]{\mTS{ss}}.} but only when the device is not actively
connected to a computer.  If connected to a computer, and not ejected, i.e. the
device is showing up as a drive on the computer, \symD{bUSY} will be displayed
if an \mAu{f} action is initiated.

\begin{itemize}
  \item It can \sAuPl{f} and \sAuPa{f} the audio files stored on the removable
    \cMSD{f} attached to the circuit board.
  \item You can \sAuSt{f} it for extra power savings when running unplugged.
  \item It can \sAuSk{f} forward or backward tracks or rewind the current track.
\end{itemize}

\info{The \cDi{f} is \textit{not} capable of
displaying the track \textit{name} being played so track
\textit{numbers} are displayed instead when applicable.}

There is an auto-stop feature that can be enabled via
\hyperref[Power Settings]{\mPS{f}}.  If in the \sAuPa{f} state for a
configurable amount of time, the \mAu{f} will automatically turn off
and go into the \sAuSt{f} state.

%%%%%%%%%%%%%%%%%%%%%%%%%%%%%%%%%%%%%%%%%%%%%%%%%%%%%%%%%%%%%%%%%%%%%%%%%%%%%%%%
% Volume
%%%%%%%%%%%%%%%%%%%%%%%%%%%%%%%%%%%%%%%%%%%%%%%%%%%%%%%%%%%%%%%%%%%%%%%%%%%%%%%%
\section{Volume} \label{Audio - Volume}

The \cVo{f} knob controls the volume level of the \mAu{f}\footnote{ The
\cVo{ss} is not connected to the \cBe{ss} so cannot control its volume.}
and has a \textit{white arrow} indicator on the sleeve.  Unlike the \cEs{f} and
\cBr{f} it does \textit{not} turn indefinitely and stops at the
\textit{minimum} and \textit{maximum} positions as indicated below.

\begin{itemize}
  \item Turn \textit{clockwise} to \textit{increase} the volume.
  \item Turn \textit{counter-clockwise} to \textit{decrease} the volume.
\end{itemize}

\begin{table}[H]
\ers{1}
\centering
\begin{tabular}{ c c c }
  Minimum & Adjust & Maximum \\
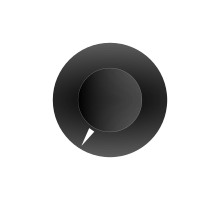
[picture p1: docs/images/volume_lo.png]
  
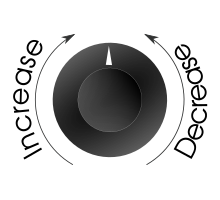
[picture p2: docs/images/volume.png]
    & 
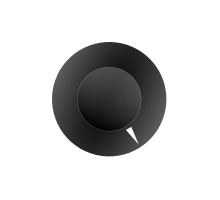
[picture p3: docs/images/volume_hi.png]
    & 
\end{tabular}
\caption{Volume Control}
\end{table}

%%%%%%%%%%%%%%%%%%%%%%%%%%%%%%%%%%%%%%%%%%%%%%%%%%%%%%%%%%%%%%%%%%%%%%%%%%%%%%%%
% Symbols
%%%%%%%%%%%%%%%%%%%%%%%%%%%%%%%%%%%%%%%%%%%%%%%%%%%%%%%%%%%%%%%%%%%%%%%%%%%%%%%%
\section{Symbols}  \label{Audio - Symbols}

There are a number of symbols that will be used in the next sections to
describe the controls and actions that can be performed.

\ers{2.8}
\begin{longtabu}{ X[1,c,m] | X[4,l,m] }
  \thrule
  \multicolumn{2}{c}{\thb{Controls}} \\ \mrule
  \thbi{Symbol} & \thbi{Meaning} \\ \mrule

  \sPl & \cPl{f} push-button. \\ \drule{2}
  \sNe & \cNe{f} push-button. \\ \drule{2}
  \sPr & \cPr{f} push-button. \\ \thrule

  \multicolumn{2}{c}{\thb{Actions}} \\ \mrule
  \thbi{Symbol} & \thbi{Meaning} \\ \mrule

  \sPlay
    & Press \& Release \thinspace\sPl\enspace to \sAuPl{f} the \mAu{f}
      when it is in the \sAuPa{f} or \sAuSt{f} states. \\ \drule{2}
  \sPause
    & Press \& Release \thinspace\sPl\enspace to \sAuPa{f} the \mAu{f}
      when it is in the \sAuPl{f} state. \\ \drule{2}
  \sStop
    & Press \& Hold \thinspace\sPl\enspace until \symD{StOP}
      is displayed then release to \sAuSt{f} the \mAu{f}
      when it is in the \sAuPl{f} or \sAuPa{f} states. \\ \drule{2}
  \sNext
    & Press \& Release or Press \& Hold \thinspace\sNe\enspace to \sAuSk{f}
      forward tracks. \\ \drule{2}

  \pagebreak \drule{2}
  \sPrev
    & Press \& Release or Press \& Hold \thinspace\sPr\enspace to \dRe{f}
      the current track or \sAuSk{f} backward tracks. \\

  \bhrule
\caption{Audio - Symbols}
\end{longtabu}

%%%%%%%%%%%%%%%%%%%%%%%%%%%%%%%%%%%%%%%%%%%%%%%%%%%%%%%%%%%%%%%%%%%%%%%%%%%%%%%%
% Play|Pause|Stop
%%%%%%%%%%%%%%%%%%%%%%%%%%%%%%%%%%%%%%%%%%%%%%%%%%%%%%%%%%%%%%%%%%%%%%%%%%%%%%%%
\section{Play | Pause | Stop} \label{Audio - Play|Pause|Stop}

The \thinspace\sPl\enspace push-button can \sAuPl{f}, \sAuPa{f} or \sAuSt{f}
the \mAu{f}.

\par\medskip

The \mAu{f} starts in the \sAuSt{f} state when the device is initially switched
\sOn{f} via the \cPo{f}.  To start playback, \aPR{f}.

\ase{1}{{c c c c}}{%
\sAuSt{sym} & \sPlay & \eStart{sym}{PLAYBACK} & \sAuPl{sym} \\}

To \sAuPa{f}, \aPR{f} when in the \sAuPl{f} state.

\ase{1}{{c c c c}}{%
\sAuPl{sym} & \sPause & \ePa{sym}{PLAYBACK} & \sAuPa{sym} \\}

To resume playback, \aPR{f} when in the \sAuPa{f} state.

\ase{1}{{c c c c}}{%
\sAuPa{sym} & \sPlay & \eResume{sym}{PLAYBACK} & \sAuPl{sym} \\}

To \sAuSt{f} the \mAu{f} when in \sAuPl{f} or \sAuPa{f} states, \aPH{f} for
\mono{2} seconds and \aRe{f} when the \cDi{f} shows

\begin{figure}[H]
\centering
  \sDl{StOP}
\end{figure}

\ase{1}{{c c c c}}{%
\sAuPl{sym} & \multirow{2}{*}{\sStop} & \multirow{2}{*}{\eSt{sym}{PLAYBACK}}
  & \multirow{2}{*}{\sAuSt{sym}} \\ \dcrule{1}{1}
\sAuPa{sym} & & & \\}

Besides the power savings that \sAuSt{f} provides over \sAuPa{f},
there is another difference between \sAuPa{f} and \sAuSt{f}.

\begin{itemize}
  \item When resuming from \sAuPa{f}, the the track will resume playing from
    the same place as when it was paused.
  \item When resuming from \sAuSt{f}, the track will start playing from the
    beginning.
\end{itemize}

%%%%%%%%%%%%%%%%%%%%%%%%%%%%%%%%%%%%%%%%%%%%%%%%%%%%%%%%%%%%%%%%%%%%%%%%%%%%%%%%
% Next
%%%%%%%%%%%%%%%%%%%%%%%%%%%%%%%%%%%%%%%%%%%%%%%%%%%%%%%%%%%%%%%%%%%%%%%%%%%%%%%%
\section{Next} \label{Audio - Next}

The \thinspace\sNe\enspace push-button is used to \aSkip{f} \textit{forward}
one or more tracks.  

\begin{itemize}
  \item \aPR{f} to \aSkip{f} to the \textit{next} track.
    \begin{itemize}
      \item The next track number will \textit{not} be shown on the \cDi{f}.
    \end{itemize}
  \item \aPH{f} to \aSkip{f} \textit{forward} one or more tracks.
    \begin{itemize}
      \item The longer the push-button is held, the faster tracks will progress.
      \item The track numbers \textit{will} be shown on the \cDi{f}, for
        example:
        \figD{!!22}{Track \#22}
      \item \aRe{f} when you get to the track you want.
    \end{itemize}
\end{itemize}

\as{{c c c c c}}{%
\sAuPl{sym} & & & & \\ \dcrule{1}{1}
\sAuPa{sym} & \sNext & \sAuSk{sym} & \eSk{sym}{FORWARD} & \sAuPl{sym} \\ \dcrule{1}{1}
\sAuSt{sym} & & & & \\}

\begin{table}[H]
\ers{1}
\centering
\begin{tabu} { X[1,c,m] | X[1,c,m] }
  \thrule
  \thbi{Hold Time} & \thbi{Tracks per Second} \\ \mrule
  First \num{5} Tracks & \num{1} \\ \drule{2}
  Next \num{10} Tracks & \num{2} \\ \drule{2}
  Next \num{20} Tracks & \num{4} \\ \drule{2}
  Next \num{40} Tracks & \num{8} \\ \drule{2}
  Next \num{80} Tracks & \num{16} \\ \drule{2}
  Next \textit{\large\mono{N}} Tracks & \num{32} \\
  \bhrule
\end{tabu}
\caption{Audio - Next Hold Times}
\end{table}

\info{When the device is in the \sPoSl{f} power state, \sNe\enspace
can \textit{not} wake it - see \hyperref[Power]{\mPo{f}} for more
information and controls that can wake the device from \sPoSl{f}.}

%%%%%%%%%%%%%%%%%%%%%%%%%%%%%%%%%%%%%%%%%%%%%%%%%%%%%%%%%%%%%%%%%%%%%%%%%%%%%%%%
% Previous
%%%%%%%%%%%%%%%%%%%%%%%%%%%%%%%%%%%%%%%%%%%%%%%%%%%%%%%%%%%%%%%%%%%%%%%%%%%%%%%%
\section{Previous} \label{Audio - Previous}

The \thinspace\sPr\enspace push-button is used to \aSkip{f} \textit{backward}
one or more tracks or \dRe{f} the current track.

\begin{itemize}
  \item \aPR{f}
    \begin{itemize}
      \item \dRe{f} the current track if more than $\frac{1}{4}$ of the track
        has played.
      \item Otherwise, \aSkip{f} to the \textit{previous} track.
      \item The track number will \textit{not} be shown on the \cDi{f}.
    \end{itemize}
  \item \aPH{f} to \aSkip{f} \textit{backward} one or more tracks.
    \begin{itemize}
      \item The longer the push-button is held, the faster tracks will progress.
      \item The track numbers \textit{will} be shown on the \cDi{f}, for example:
        \figD{!!!8}{Track \#8}
      \item \aRe{f} when you get to the track you want.
    \end{itemize}
\end{itemize}

\as{{c c c c c}}{%
\sAuPl{sym} & \multirow{3}{*}[-1.5mm]{\sPrev} & \multirow{3}{*}[-1.5mm]{\sAuSk{sym}}
  & \multirow{3}{*}[-2.5mm]{%
    \begin{tabu}{c} \eRewind{sym}{CURRENT TRACK} \\ \drule{1} \eSk{sym}{BACKWARD} \end{tabu}}
  & \multirow{3}{*}{\sAuPl{sym}} \\ \dcrule{1}{1}
\sAuPa{sym} & & & & \\ \dcrule{1}{1}
\sAuSt{sym} & & & & \\}

\begin{table}[H]
\ers{1}
\centering
\begin{tabu}{ X[1,c,m] | X[1,c,m] }
  \thrule
  \thbi{Hold Time} & \thbi{Tracks per Second} \\ \mrule
  First \num{5} Tracks & \num{1} \\ \drule{2}
  Next \num{10} Tracks & \num{2} \\ \drule{2}
  Next \num{20} Tracks & \num{4} \\ \drule{2}
  Next \num{40} Tracks & \num{8} \\ \drule{2}
  Next \num{80} Tracks & \num{16} \\ \drule{2}
  Next \textit{\large\mono{N}} Tracks & \num{32} \\
  \bhrule
\end{tabu}
\caption{Audio - Previous Hold Times}
\end{table}

\info{When the device is in the \sPoSl{f} power state, \sPr\enspace
can \textit{not} wake it - see \hyperref[Power]{\mPo{f}} for more
information and controls that can wake the device from \sPoSl{f}.}

%%%%%%%%%%%%%%%%%%%%%%%%%%%%%%%%%%%%%%%%%%%%%%%%%%%%%%%%%%%%%%%%%%%%%%%%%%%%%%%%
% Track Selection
%%%%%%%%%%%%%%%%%%%%%%%%%%%%%%%%%%%%%%%%%%%%%%%%%%%%%%%%%%%%%%%%%%%%%%%%%%%%%%%%
\section{Track Selection} \label{Audio - Track Selection}

In addition to using the \cNe{f} and \cPr{f} controls to \sAuSk{f} forward and
backward in order to select a track for playback, there also exists the
capability to select a track more quickly and directly when in
\hyperref[Clock]{\mCl{f}} mode.  The \cEs{f} can be used alone or in
combination with \aTo{f} to do so.  Refer to \hyperref[Show Track]{Show Track}
and \hyperref[Set Track]{Set Track} in that section for more information.

%%%%%%%%%%%%%%%%%%%%%%%%%%%%%%%%%%%%%%%%%%%%%%%%%%%%%%%%%%%%%%%%%%%%%%%%%%%%%%%%
% Reference
%%%%%%%%%%%%%%%%%%%%%%%%%%%%%%%%%%%%%%%%%%%%%%%%%%%%%%%%%%%%%%%%%%%%%%%%%%%%%%%%
\section{Reference} \label{Audio - Reference}

\ers{2}
\begin{longtabu}{ X[2,c,m] | X[2,c,m] | X[2,c,m] | X[4,c,m] | X[2,c,m] }
  \thrule

  \thbi{State} & \thbi{Action} & \thbi{Control} & \thbi{Effect} & \thbi{Next} \\ \mdrule

  \multirow{3}{*}[-1.5mm]{\sAuSt{sym}}
    & \sPlay & \sPl & \ePl{sym}{AUDIO} & \sAuPl{sym} \\ \dcrule{2}{5}
  & \sNext & \sNe & \eSk{sym}{FORWARD}
    & \multirow{2}{*}[-1mm]{\sAuSk{sym}} \\ \dcrule{2}{4}
  & \sPrev & \sPr & \eSk{sym}{BACKWARD} & \\ \mrule

  \multirow{4}{*}[-1.5mm]{\sAuPl{sym}}
    & \sPause & \sPl & \ePa{sym}{AUDIO} & \sAuPa{sym} \\ \dcrule{2}{5}
  & \sNext & \sNe & \eSk{sym}{FORWARD}
    & \multirow{2}{*}[-1mm]{\sAuSk{sym}} \\ \dcrule{2}{4}
  & \sPrev & \sPr & \eSk{sym}{BACKWARD} & \\ \dcrule{2}{5}
  & \sStop & \sPl & \eSt{sym}{AUDIO} & \sAuSt{sym} \\ \mrule

  \multirow{5}{*}[-1.5mm]{\sAuPa{sym}}
    & \sPlay & \sPl & \eResume{sym}{AUDIO} & \sAuPl{sym} \\ \dcrule{2}{5}
  & \sNext & \sNe & \eSk{sym}{FORWARD}
    & \multirow{2}{*}[-1mm]{\sAuSk{sym}} \\ \dcrule{2}{4}
  & \sPrev & \sPr & \eSk{sym}{BACKWARD} & \\ \dcrule{2}{5}
  & \sStop & \sPl & \multirow{2}{*}[-1mm]{\eSt{sym}{AUDIO}}
    & \multirow{2}{*}[-1mm]{\sAuSt{sym}} \\ \dcrule{2}{3}
  & \action{ss}{INACTIVITY} & --- & & \\ \mrule

  \pagebreak
  \mrule

  \multirow{4}{*}[-1mm]{\sAuSk{sym}} & \sNext & \sNe
    & \eSk{sym}{FORWARD} & \multirow{2}{*}[-1mm]{---} \\ \dcrule{2}{4}
  & \sPrev & \sPr & \eSk{sym}{BACKWARD} & \\ \dcrule{2}{5}
  & \multirow{2}{*}[-1mm]{\action{ss}{RELEASE}} & \sNe
    & \multirow{2}{*}[-1mm]{\ePl{sym}{TRACK}}
    & \multirow{2}{*}[-1mm]{\sAuPl{sym}} \\ \dcrule{3}{3}
  & & \sPr & & \\

  \bhrule
\caption {Audio - Reference}
\end{longtabu}

%%%%%%%%%%%%%%%%%%%%%%%%%%%%%%%%%%%%%%%%%%%%%%%%%%%%%%%%%%%%%%%%%%%%%%%%%%%%%%%%
% Audio - State Diagram
%%%%%%%%%%%%%%%%%%%%%%%%%%%%%%%%%%%%%%%%%%%%%%%%%%%%%%%%%%%%%%%%%%%%%%%%%%%%%%%%
\section{State Diagram} \label{Audio - State Diagram}

\begin{figure}[H]
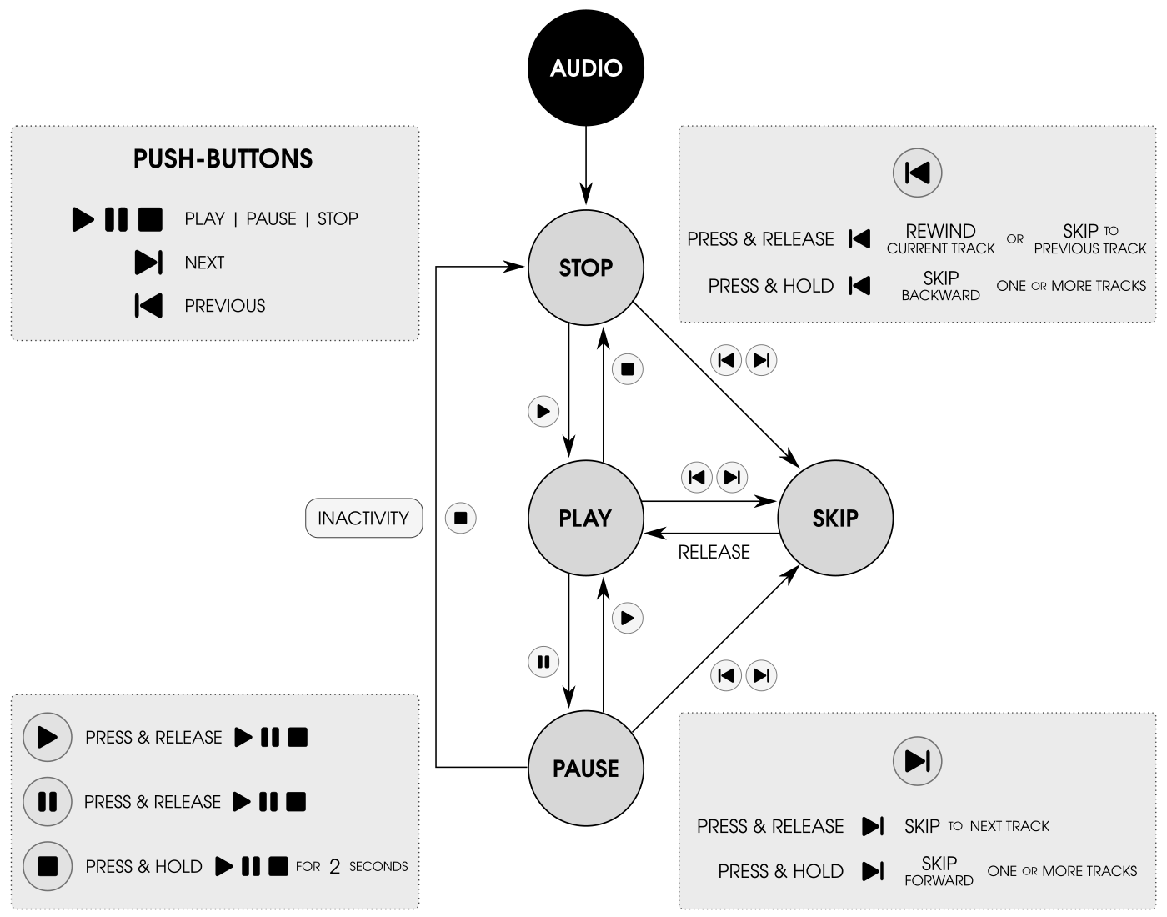
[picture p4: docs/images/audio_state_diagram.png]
  
\caption{Audio - State Diagram}
\end{figure}

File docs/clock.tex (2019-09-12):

%%%%%%%%%%%%%%%%%%%%%%%%%%%%%%%%%%%%%%%%%%%%%%%%%%%%%%%%%%%%%%%%%%%%%%%%%%%%%%%%
% Clock
%%%%%%%%%%%%%%%%%%%%%%%%%%%%%%%%%%%%%%%%%%%%%%%%%%%%%%%%%%%%%%%%%%%%%%%%%%%%%%%%
\chapter{Clock} \label{Clock}
\vspace{-10ex}\mCl{syml}\vskip 8ex

%%%%%%%%%%%%%%%%%%%%%%%%%%%%%%%%%%%%%%%%%%%%%%%%%%%%%%%%%%%%%%%%%%%%%%%%%%%%%%%%
% Introduction
%%%%%%%%%%%%%%%%%%%%%%%%%%%%%%%%%%%%%%%%%%%%%%%%%%%%%%%%%%%%%%%%%%%%%%%%%%%%%%%%
\section{Introduction}

This is the mode the device will likely be in a majority of the time.  It
displays the current time and can display the date and current track number
and provides the capability to directly select a track for playback.  It is
also the only mode where you can turn the night light on and off.

\par\medskip

It is the \mPr{f} and \textit{only} mode when the \cRs{f} is in the \dMi{f}
position.

\par\medskip

To get to \mCl{f} mode simply \aTu{f} the \cRs{f} to the \dMi{f}.

\begin{table}[H]
\ers{3}
\centering
\begin{tabu} { X[1,c,m] | X[1,c,m] | X[1,c,m] }
  \thrule
  \thbi{Position} & \thbi{Mode} & \thbi{Action} \\ \mrule
  \sLe & \multirow{2}{*}[-1mm]{\mode{s}{ANY}}
    & $\hskip -4mm$ \sLtoM \\ \dcrule{1}{1} \dcrule{3}{3}
  \sRi & & $\hskip 4mm$ \sRtoM \\ \mdrule
  \sMi & \mCl{sym} & --- \\
  \bhrule
\end{tabu}
\caption{Clock - Mode}
\end{table}

%%%%%%%%%%%%%%%%%%%%%%%%%%%%%%%%%%%%%%%%%%%%%%%%%%%%%%%%%%%%%%%%%%%%%%%%%%%%%%%%
% Overview
%%%%%%%%%%%%%%%%%%%%%%%%%%%%%%%%%%%%%%%%%%%%%%%%%%%%%%%%%%%%%%%%%%%%%%%%%%%%%%%%
\pagebreak
\section{Overview}

There are a number of states the \mCl{f} can be in and are explained in the
following sections.

\begin{table}[H]
\ers{1}
\centering
\begin{tabu} { X[1,c,m] | X[3,l,m] }
  \thrule
  \thbi{State} & \thbi{Description} \\ \mrule
  \sClTi{sym} & Display the current time. \\ \drule{2}
  \sClMD{sym} & Display the month \& day. \\ \drule{2}
  \sClYe{sym} & Display the year.  \\ \drule{2}
  \sClSh{sym} & Display the current track number. \\ \drule{2}
  \sClSe{sym} & Select a track for playback. \\
  \bhrule
\end{tabu}
\caption{Clock - States}
\end{table}

To progress through the states, \aPR{f} the \cEs{f}.  The basic progression from
\sClTi{f} back to \sClTi{f} is:

\as{{ c c c c c c c c c }}{%
\sClTi{sym} & \sPR & \sClMD{sym} & \sPR & \sClYe{sym} & \sPR & \sClSh{sym}
  & \sPR & \sClTi{sym} \\}

\aTo{f} can also be used to show the current track number.  From \sClTi{f},
\sClMD{f} or \sClYe{f}, you will \aTo{f} the \cTo{f} of the enclosure for
\num{1} second to show the current track number.\footnote{ Touch must be enabled
and configured for this to work - see \hyperref[Touch Settings]{\mTS{ss}} for
more information.}

\as{{ c c c }}{%
\sClTi{sym} & & \\ \drule{1}
\sClMD{sym} & \sToN{1} & \sClSh{sym} \\ \drule{1}
\sClYe{sym} & & \\}

At \sClSh{f}, if you \aTu{f} the \cEs{f}, the state will change to \sClSe{f} and
from there you can select a track for playback.

\as{{ c c c }}{\sClSh{sym} & \sTu & \sClSe{sym} \\}

If no action is taken, states other than \sClTi{f} will only display their
values for so many seconds before redisplaying the time.

\as{{ c l l }}{%
\sClMD{sym} & \multirow{2}{*}{\sNPRN{3}}
  & \multirow{8}{*}{\sClTi{sym}} \\ \drule{1}
\sClYe{sym} & & \\ \drule{2}
& \sNPRN{3} & \\ \dcrule{2}{2}
\sClSh{sym}  & \sNTuN{3} & \\ \dcrule{2}{2}
& \sNToN{3} & \\ \drule{2}
& \sNPRN{15} & \\ \dcrule{2}{2}
\sClSe{sym} & \sNTuN{15} & \\ \dcrule{2}{2}
& \sNToN{15} & \\}

%%%%%%%%%%%%%%%%%%%%%%%%%%%%%%%%%%%%%%%%%%%%%%%%%%%%%%%%%%%%%%%%%%%%%%%%%%%%%%%%
% Time
%%%%%%%%%%%%%%%%%%%%%%%%%%%%%%%%%%%%%%%%%%%%%%%%%%%%%%%%%%%%%%%%%%%%%%%%%%%%%%%%
\section{Time} \sClTi{syml}

Displays the current time in either \num{12} or \num{24} hour format, depending
on which was configured via \hyperref[Set Clock]{\mSC{f}}. For \num{12} hour
format, a \textit{decimal} at the \textit{bottom right} of the \cDi{f} is used
to designate \mono{PM}.

\figDT{11:00}{11 AM}{11:00.}{11 PM}

This is the base state of \mCl{f} mode and will be the first when \mCl{f}
mode is selected.  If you go to any other state, you will either need to wait
some amount of time, either \num{3} or \num{15} seconds, or \aPR{f} the \cEs{f}
one or more times. If in \sClSe{f}, after \aPR{f}, the time will redisplay after
\num{3} seconds.  Alternatively, you can \aPR{f} twice to have it redisplay
immediately.

\begin{table}[H]
\ers{0.1}
\centering
\begin{tabu} { c l l }
  \mrule
  \sClMD{sym} & & \multirow{4}{*}{\sClTi{sym}} \\ \drule{1}
  \sClYe{sym} & \sNPRN{3} & \\ \drule{1}
  \sClSh{sym} & & \\ \drule{2}
  \sClSe{sym} & \sNPRN{15} & \\
  \mrule
\end{tabu}
\quad\quad\quad\quad\quad
\begin{tabu} { c l l l }
  \mrule
  \sClMD{sym} & \multicolumn{2}{l}{\sPRN{3}}
    & \multirow{5}{*}{\sClTi{sym}} \\ \drule{3}
  \sClYe{sym} & \multicolumn{2}{l}{\sPRN{2}} & \\ \drule{3}
  \sClSh{sym} & \multicolumn{2}{l}{\sPR} & \\ \drule{3}
  \multirow{2}{*}{\sClSe{sym}} & \sPR & \sNPRN{3} & \\ \dcrule{2}{3}
  & \multicolumn{2}{l}{\sPRN{2}} & \\
  \mrule
\end{tabu}
\end{table}

%%%%%%%%%%%%%%%%%%%%%%%%%%%%%%%%%%%%%%%%%%%%%%%%%%%%%%%%%%%%%%%%%%%%%%%%%%%%%%%%
% Month & Day
%%%%%%%%%%%%%%%%%%%%%%%%%%%%%%%%%%%%%%%%%%%%%%%%%%%%%%%%%%%%%%%%%%%%%%%%%%%%%%%%
\pagebreak
\section{Month \& Day} \sClMD{syml}

Displays the month and day, delimited by a \textit{decimal}.

\figDT{!1.01}{January 1st}{12.31}{December 31st}

To display the month and day from \sClTi{f}, simply \aPR{f} the \cEs{f}.  From
other states, you need to \aPR{f} the \cEs{f} multiple times.

\as{{ c l l }}{%
\sClTi{sym} & \sPR & \multirow{4}{*}{\sClMD{sym}} \\ \drule{2}
\sClSh{sym} & \sPRN{2} & \\ \drule{2}
\sClYe{sym} & \multirow{2}{*}{\sPRN{3}} & \\ \drule{1}
\sClSe{sym} & & \\}

If you don't \aPR{f} the \cEs{f} again within \num{3} seconds, the time will
automatically redisplay.

\as{{ c c c }}{\sClMD{sym} & \sNPRN{3} & \sClTi{sym} \\}

%%%%%%%%%%%%%%%%%%%%%%%%%%%%%%%%%%%%%%%%%%%%%%%%%%%%%%%%%%%%%%%%%%%%%%%%%%%%%%%%
% Year
%%%%%%%%%%%%%%%%%%%%%%%%%%%%%%%%%%%%%%%%%%%%%%%%%%%%%%%%%%%%%%%%%%%%%%%%%%%%%%%%
\section{Year} \sClYe{syml}

Displays the year.

\figDT{2017}{Year 2017}{9999}{Year 9999}

To display the year from \sClMD{f}, simply \aPR{f} the \cEs{f}. From other
states, you need to \aPR{f} the \cEs{f} multiple times.

\as{{c l l }}{%
\sClMD{sym} & \sPR & \multirow{4}{*}{\sClYe{sym}} \\ \drule{2}
\sClTi{sym} & \sPRN{2} & \\ \drule{2}
\sClSh{sym} & \sPRN{3} & \\ \drule{2} 
\sClSe{sym} & \sPRN{4} \\}

If you don't \aPR{f} the \cEs{f} again within \num{3} seconds, the time will
automatically redisplay.

\as{{ c c c }}{\sClYe{sym} & \sNPRN{3} & \sClTi{sym} \\}

%%%%%%%%%%%%%%%%%%%%%%%%%%%%%%%%%%%%%%%%%%%%%%%%%%%%%%%%%%%%%%%%%%%%%%%%%%%%%%%%
% Show Track
%%%%%%%%%%%%%%%%%%%%%%%%%%%%%%%%%%%%%%%%%%%%%%%%%%%%%%%%%%%%%%%%%%%%%%%%%%%%%%%%
\section{Show Track} \label{Show Track} \sClSh{syml}

Displays the current track number that is either playing or poised to play if
paused or stopped.

\figDT{!!!1}{Track \#1}{5000}{Track \#5000}

To display the current track number from \sClYe{f}, simply \aPR{f} the \cEs{f}.
Additionally, after \sClSe{f}, the state goes back to \sClSh{f}.
From other states, you need to \aPR{f} the \cEs{f} multiple times.

\as{{ c l l }}{%
\sClYe{sym} & \multirow{2}{*}{\sPR} & \multirow{4}{*}{\sClSh{sym}} \\ \drule{1}
\sClSe{sym} & & \\ \drule{2}
\sClMD{sym} & \sPRN{2} & \\ \drule{2}
\sClTi{sym} & \sPRN{3} & \\}

\aTo{f} can also be used to display the current track number from \sClTi{f},
\sClMD{f} and \sClYe{f}.  To do so, \aTo{f} the \cTo{f} of the enclosure for
\num{1} second.

\as{{ c c c }}{%
\sClTi{sym} & & \\ \drule{1}
\sClMD{sym} & \sToN{1} & \sClSh{sym} \\ \drule{1}
\sClYe{sym} & & \\}

\info{For \aTo{f} to work, make sure you have enabled it via
\hyperref[Touch Settings]{\mTS{f}} and that the palm of your hand or
most of your fingers lay across the \cTo{f} of the enclosure.}

If you don't \aPR{f} or \aTu{f} the \cEs{f} within \num{3} seconds after
showing the track or aren't touching the \cTo{f} of the enclosure, the time
will automatically redisplay.  If you \aPR{f} before a \aTu{f}, it will
immediately go back to \sClTi{f}.

\as{{ c c c }}{%
\multirow{4}{*}{\sClSh{sym}} & \sPR & \multirow{4}{*}{\sClTi{sym}} \\ \dcrule{2}{2}
& $\hskip 3mm$ \sNTuN{3} & \\ \dcrule{2}{2}
& $\hskip 3mm$ \sNToN{3} & \\ \dcrule{2}{2}
& $\hskip 3mm$ \sNPRN{3} & \\}

It will stay in this state as long as touch is detected\footnote{ If you have
enabled a \textit{Touch Time} via \hyperref[Power Settings]{\mPS{ss}}, the screens
will turn off and the device will sleep if the \textit{Touch Time} is exceeded.}.

%%%%%%%%%%%%%%%%%%%%%%%%%%%%%%%%%%%%%%%%%%%%%%%%%%%%%%%%%%%%%%%%%%%%%%%%%%%%%%%%
% Set Track
%%%%%%%%%%%%%%%%%%%%%%%%%%%%%%%%%%%%%%%%%%%%%%%%%%%%%%%%%%%%%%%%%%%%%%%%%%%%%%%%
\section{Set Track} \label{Set Track} \sClSe{syml}

Allows you to select a track for playback. This can be done
irrespective of \mAu{f} state - it can be in \sAuPl{f}, \sAuPa{f} or
\sAuSt{f}.  This method of selection is also independent of the \mAu{f}
controls - \aPR{f} here will refer to the \cEs{f} and \textit{not} the
\cPl{f} push-button.

\par\medskip

To select a track for playback, you first need to \sClSh{f}. After that, you
need to \aTu{f} the \cEs{f} within \num{3} seconds else it will go back to
\sClTi{f}.

\as{{c c c}}{\sClSh{sym} & \sTuN{3s} & \sClSe{sym} \\}

The idle timeout will be updated to \num{15} seconds after which it will go back
to \sClTi{f}. As long as you are turning the \cEs{f} or touching the \cTo{f} of
the enclosure the timeout will not occur - it is reset with each turn and while
detecting touch.

\as{{l l l}}{%
& \sNTuN{15} & \\ \dcrule{2}{2}
\sClSe{sym} & \sNPRN{15} & \sClTi{sym} \\ \dcrule{2}{2}
& \sNToN{15} & \\}

Continue to \aTu{f} the \cEs{f} until you land on the track number you want
to play - if you turn counter-clockwise past the first track, the number will
wrap to the last track on disk and if you turn clockwise past the last track,
the number will wrap to the first track.  When you're ready, \aPR{f} the
\cEs{f} and the selected track will begin to play and the state will go back to
\sClSh{f}.

\as{{c c c c c}}{%
\multirow{2}{*}{\sClSe{sym}}
  & \sTu & \multirow{2}{*}{\sPR}
  & \multirow{2}{*}{\ePl{sym}{TRACK}} & \multirow{2}{*}{\sClSh{sym}} \\
& \eUp{sym}{} & & & \\}

From \sClSh{f} you can choose to select another track for playback or go back
to displaying the time.  To go back to \sClTi{f}, either

\begin{enumerate}
  \item \aPR{f} the \cEs{f}, \textit{or}
  \item Wait \num{3} seconds.
\end{enumerate}

\info{You must \aTu{f} the \cEs{f} to be able to select a track for playback
even if the current track initially displayed in \sClSh{f} is the track you
want to play since a \aPR{f} of the \cEs{f} will go back to \sClTi{f}.  If the
\mAu{f} is paused or stopped and you want to play the current track that is
poised to play, either
\begin{enumerate}
  \item Press \& Release the \cPl{f} push-button, \textit{or}
  \item \aTu{f} the \cEs{f}, then \aTu{f} back to the current track and \aPR{f}.
\end{enumerate}}

%%%%%%%%%%%%%%%%%%%%%%%%%%%%%%%%%%%%%%%%%%%%%%%%%%%%%%%%%%%%%%%%%%%%%%%%%%%%%%%%
% Night Light
%%%%%%%%%%%%%%%%%%%%%%%%%%%%%%%%%%%%%%%%%%%%%%%%%%%%%%%%%%%%%%%%%%%%%%%%%%%%%%%%
\section{Night Light} \label{Night Light}

One of the main uses of the \cLi{f} window is as a night light. The night
light can only be turned on or off from \mCl{f} mode.  To toggle the night
light on\slash off, \aPH{f} the \cEs{f} for approximately \num{2} seconds.
This is an equivalent hold time for a \aReset{f}, however bars will \textit{not}
blink on the \cDi{f}.

\as{{c c c}}{\state{sym}{ANY STATE} & \sPHN{2} & \eTo{sym}{ON|OFF} \\}

If the \cLi{f} is off, it will turn on\footnote{ The brightness is independent
of this so make sure the \cBr{ss} is turned up.} and if on, it will turn off.

\info{Toggling the night light on/off can be done from \textit{any} state
and will not affect, most importantly, track selection.}

In addition to a white light, up to \num{3} additional colors are configurable
via \hyperref[Set Night Light]{\mSN{f}}.  To select a different night light
color, with the night light on, \aTu{f} the \cEs{f}.

\par\medskip

Because this requires turning the \cEs{f}, it can only be done in \sClTi{f},
\sClMD{f} and \sClYe{f} states.

\as{{c c c c}}{%
\sClTi{sym} & & \\ \dcrule{1}{1}
\sClMD{sym} & \eOn{sym}{NIGHT LIGHT}
  & \sTu & \eAc{sym}{CYCLE COLORS} \\ \dcrule{1}{1}
\sClYe{sym} & & \\}

Note that only unique colors are considered, so if you haven't
configured any of the additional colors there will be no effect.  Also,
duplicate colors are removed from the cycle.

\info{Another way you can achieve turning the night light on and off is to set
one of the configurable colors to black. You can then \aTu{f} the \cEs{f} to
select it, effectively turning the night light off.}

%%%%%%%%%%%%%%%%%%%%%%%%%%%%%%%%%%%%%%%%%%%%%%%%%%%%%%%%%%%%%%%%%%%%%%%%%%%%%%%%
% Night Light - Lighting Animations
%%%%%%%%%%%%%%%%%%%%%%%%%%%%%%%%%%%%%%%%%%%%%%%%%%%%%%%%%%%%%%%%%%%%%%%%%%%%%%%%
\subsection{Lighting Animations}

There are a number of preset, non-configurable lighting animations, in addition
to the solid colors, that you can cycle through.  To toggle between a solid
color light and the lighting animations, \aPH{f} the \cEs{f} for approximately
\num{4} seconds. If the night light is off, it will automatically turn on after
\num{2} seconds as desribed in the previous section.  Continue holding and at
\num{4} seconds it will toggle between a solid color and lighting animation.
However, an unfortunate side effect is that if it is on, it will turn off first
because of the on/off toggle, then turn back on.

\as{{c c c}}{\state{sym}{ANY STATE} & \sPHN{4} & \eTo{sym}{ANIMATION|COLOR} \\}

After toggling the animations on, you can cycle through the different ones in
the same way you can cycle through the solid colors by turning the \cEs{f}.

%%%%%%%%%%%%%%%%%%%%%%%%%%%%%%%%%%%%%%%%%%%%%%%%%%%%%%%%%%%%%%%%%%%%%%%%%%%%%%%%
% Coin Cell Battery
%%%%%%%%%%%%%%%%%%%%%%%%%%%%%%%%%%%%%%%%%%%%%%%%%%%%%%%%%%%%%%%%%%%%%%%%%%%%%%%%
\section{Coin Cell Battery}

There is a \mono{CR2032} \hyperref[Coin Cell Battery]{\cCC{f}}, apart from the
\cRB{f} battery, attached to the \dTo{f} that continues to keep time even when
the device if switched \sOff{f} via the \cPo{f}.  If the time is incorrect when
switching the device \sOn{f}, the battery likely needs replacement.  For more
information see \hyperref[Replacing Battery]{Replacing the Coin Cell Battery}.

%%%%%%%%%%%%%%%%%%%%%%%%%%%%%%%%%%%%%%%%%%%%%%%%%%%%%%%%%%%%%%%%%%%%%%%%%%%%%%%%
% Power
%%%%%%%%%%%%%%%%%%%%%%%%%%%%%%%%%%%%%%%%%%%%%%%%%%%%%%%%%%%%%%%%%%%%%%%%%%%%%%%%
\section{Power}

In \sClTi{f}, \sClMD{f}, \sClYe{f} and \sClSh{f}, the screens will \sDim{f} when
the device enters a \sPoNa{f} power state.

\par\medskip

In \sClTi{f}, \sClMD{f}, \sClYe{f} and \sClSh{f}, the screens will turn \sOff{f}
when the device enters a \sPoSl{f} power state.

\par\medskip

In \sClSe{f}, the device will neither \sPoNa{f} nor \sPoSl{f}.

\ers{2}
\begin{table}[H]
  \begin{tabu}{ X[1,c,m] | X[1,c,m] | X[1,c,m] }
  \thrule
  \thbi{Power State} & \thbi{Clock State} & \thbi{Screens} \\ \mrule

  \multirow{2}{*}[-1mm]{\sPoNa{sym}} 
    & \sClTi{sym} \sClMD{sym} \sClYe{sym} \newline \sClSh{sym}
    & \sDim{sym} \\ \dcrule{2}{3}
  & \sClSe{sym} & \sOn{sym} \\ \mrule

  \multirow{2}{*}[-1mm]{\sPoSl{sym}} 
    & \sClTi{sym} \sClMD{sym} \sClYe{sym} \newline \sClSh{sym}
    & \sOff{sym} \\ \dcrule{2}{3}
  & \sClSe{sym} & \sOn{sym} \\

  \bhrule
  \end{tabu}
\caption {Clock - Power}
\end{table}

%%%%%%%%%%%%%%%%%%%%%%%%%%%%%%%%%%%%%%%%%%%%%%%%%%%%%%%%%%%%%%%%%%%%%%%%%%%%%%%%
% Reference
%%%%%%%%%%%%%%%%%%%%%%%%%%%%%%%%%%%%%%%%%%%%%%%%%%%%%%%%%%%%%%%%%%%%%%%%%%%%%%%%
\pagebreak
\section{Reference} \label{Clock - Reference}

\ers{3}
\begin{longtabu}{ X[2,c,m] | X[1,c,m] | X[4,c,m] | X[2,c,m] }
  \thrule
  \thbi{State} & \thbi{Action} & \thbi{Effect} & \thbi{Next} \\ \mdrule

  \multirow{3}{*}[-1.5mm]{\sClTi{sym}}
    & \sPR & \eDi{sym}{MONTH \& DAY} & \sClMD{sym} \\ \dcrule{2}{4}
  & \sToN{1} & \eDi{sym}{TRACK} & \sClSh{sym} \\ \dcrule{2}{4}
  & \sTu & \eAc{sym}{CYCLE NL} & --- \\ \mrule

  \multirow{4}{*}[-1.5mm]{\sClMD{sym}}
    & \sPR & \eDi{sym}{YEAR} & \sClYe{sym} \\ \dcrule{2}{4}
  & \sToN{1} & \eDi{sym}{TRACK} & \sClSh{sym} \\ \dcrule{2}{4}
  & \sNPRN{3} & \eDi{sym}{TIME} & \sClTi{sym} \\ \dcrule{2}{4}
  & \sTu & \eAc{sym}{CYCLE NL} & --- \\ \mrule

  \multirow{4}{*}[-1.5mm]{\sClYe{sym}}
    & \sPR & \multirow{2}{*}[-1mm]{\eDi{sym}{TRACK}}
    & \multirow{2}{*}[-1mm]{\sClSh{sym}} \\ \dcrule{2}{2}
  & \sToN{1} & & \\ \dcrule{2}{4}
  & \sNPRN{3} & \eDi{sym}{TIME} & \sClTi{sym} \\ \dcrule{2}{4}
  & \sTu & \eAc{sym}{CYCLE NL} & --- \\ \mrule

  \pagebreak
  \mrule

  & \sTu & \eUp{sym}{TRACK} & \sClSe{sym} \\ \dcrule{2}{4}
  & \sPR & \multirow{4}{*}[-1.5mm]{\eDi{sym}{TIME}}
    & \multirow{4}{*}[-1.5mm]{\sClTi{sym}} \\ \dcrule{2}{2}
  \sClSh{sym} & \sNTuN{3} & & \\ \dcrule{2}{2}
  & \sNPRN{3} & & \\ \dcrule{2}{2}
  & \sNToN{3} & & \\ \mrule

  & \sTu & \eUp{sym}{TRACK} & --- \\ \dcrule{2}{4}
  & \sPR & \ePl{sym}{TRACK} & \sClSh{sym} \\ \dcrule{2}{4}
  \sClSe{sym} & \sNTuN{15} & & \\ \dcrule{2}{2}
  & \sNPRN{15} & \eDi{sym}{TIME} & \sClTi{sym} \\ \dcrule{2}{2}
  & \sNToN{15} & & \\ \mrule

  \multirow{4}{*}{\state{f}{ANY}}
    & $\hskip 2.5mm$ \sPHN{2} & \eTo{sym}{NL ON|OFF} & --- \\ \dcrule{2}{4}
  & $\hskip 2.5mm$ \sPHN{4}
    & \eTo{sym}{NL COLOR|ANIMATION} & --- \\ \dcrule{2}{4}
  & $\hskip -3.5mm$ \sMtoL & \multirow{2}{*}[-1mm]{\eCM{sym}}
    & \mSA{sym} \\ \dcrule{2}{2} \dcrule{4}{4}
  & $\hskip 3.5mm$ \sMtoR & & \mTi{sym} \\

  \bhrule
  \caption {Clock - Reference}
\end{longtabu}

%%%%%%%%%%%%%%%%%%%%%%%%%%%%%%%%%%%%%%%%%%%%%%%%%%%%%%%%%%%%%%%%%%%%%%%%%%%%%%%%
% State Diagram
%%%%%%%%%%%%%%%%%%%%%%%%%%%%%%%%%%%%%%%%%%%%%%%%%%%%%%%%%%%%%%%%%%%%%%%%%%%%%%%%
%\pagebreak
\section{State Diagram} \label{Clock State Diagram}

\begin{figure}[H]
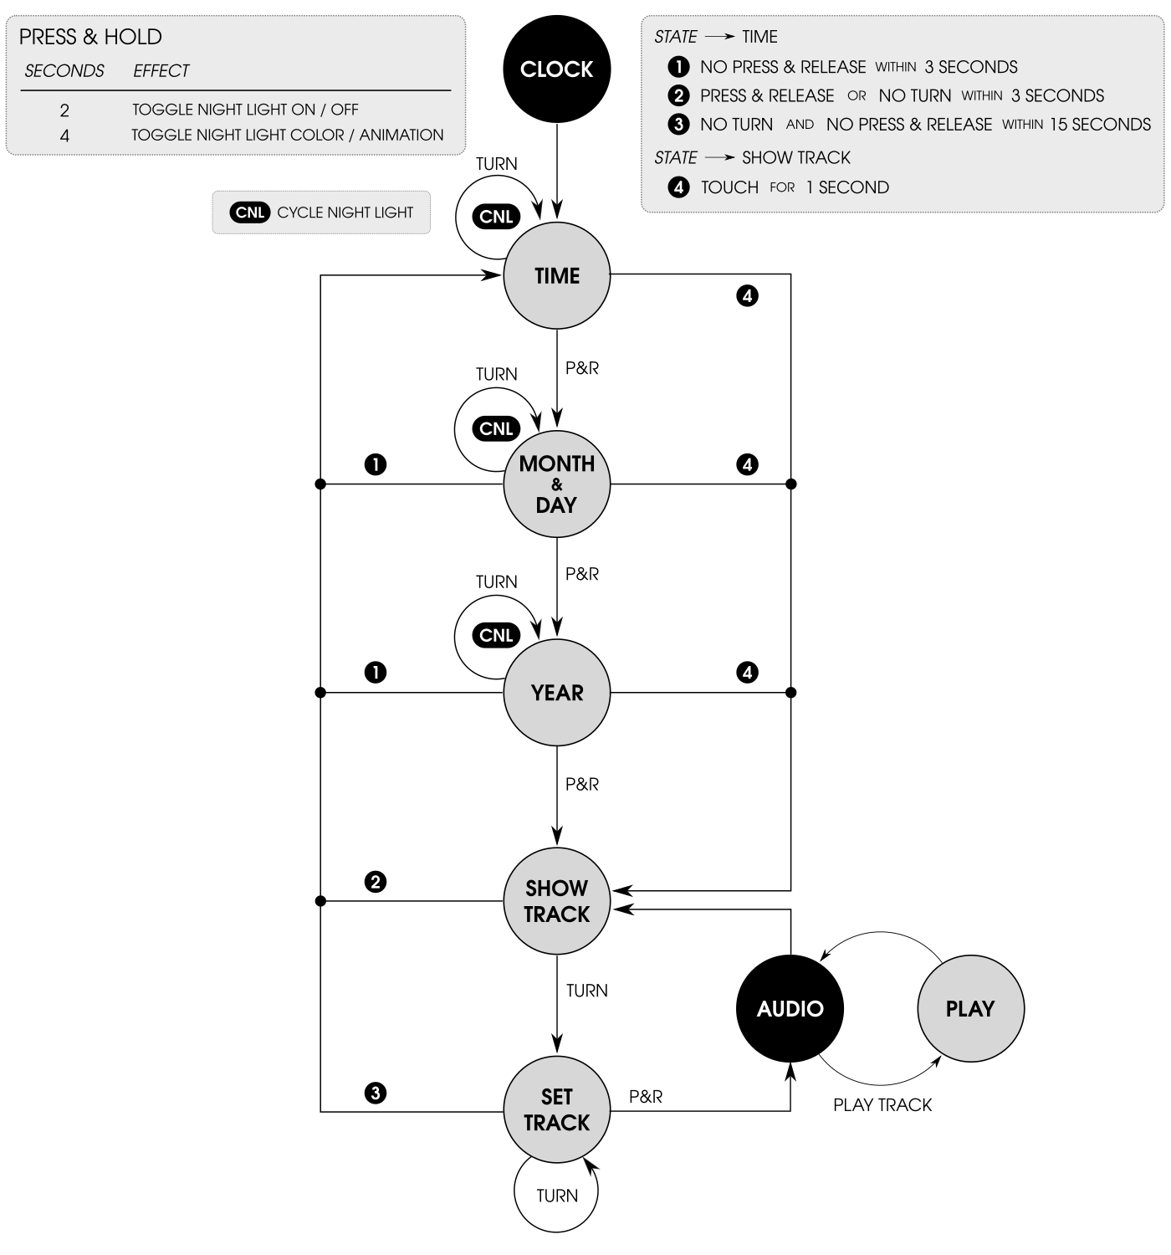
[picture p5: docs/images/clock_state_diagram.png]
  
\caption{Clock - State Diagram}
\end{figure}

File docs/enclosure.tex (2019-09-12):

%%%%%%%%%%%%%%%%%%%%%%%%%%%%%%%%%%%%%%%%%%%%%%%%%%%%%%%%%%%%%%%%%%%%%%%%%%%%%%%%
% Enclosure & Controls
%%%%%%%%%%%%%%%%%%%%%%%%%%%%%%%%%%%%%%%%%%%%%%%%%%%%%%%%%%%%%%%%%%%%%%%%%%%%%%%%
\part{Enclosure \& Controls} \label{Enclosure}

%%%%%%%%%%%%%%%%%%%%%%%%%%%%%%%%%%%%%%%%%%%%%%%%%%%%%%%%%%%%%%%%%%%%%%%%%%%%%%%%
% Introduction
%%%%%%%%%%%%%%%%%%%%%%%%%%%%%%%%%%%%%%%%%%%%%%%%%%%%%%%%%%%%%%%%%%%%%%%%%%%%%%%%
\chapter{Introduction}

The enclosure is made of \wood{} wood with a dewaxed shellac finish. The front
panel is made of \front{}.

\par\bigskip

\danger{Do not get alcohol anywhere near this.  The wood finish is shellac
whose solvent is alcohol.  Alcohol will ruin the finish, i.e. dissolve it like
turpentine will with oil based paint.  So don't rest your beer bottle, glass of
wine or shot of tequila on top.  And to be safe, don't clean it with any kind of
chemical cleaning solution.  A dry or slightly damp rag, preferably microfiber,
should be sufficient to get fingerprints, dust and other crud off of the wood
finish and \front{} front - see the \hyperref[Cleaning]{Cleaning} section.}

\par\bigskip

\danger{Before trying to disassemble the enclosure to either replace the
\hyperref[Coin Cell Battery]{\cCC{f}} or remove the
\hyperref[Micro SD Card]{\cMSD{f}} card, please read the
\hyperref[Disassembly]{Disassembly} section.}

%%%%%%%%%%%%%%%%%%%%%%%%%%%%%%%%%%%%%%%%%%%%%%%%%%%%%%%%%%%%%%%%%%%%%%%%%%%%%%%%
% Front
%%%%%%%%%%%%%%%%%%%%%%%%%%%%%%%%%%%%%%%%%%%%%%%%%%%%%%%%%%%%%%%%%%%%%%%%%%%%%%%%
\chapter{Front} \label{Front}

The \cFr{f} is made of \front{} with cast acrylic windows for the
\hyperref[Display]{\cDi{f}} and \hyperref[Lighting]{\cLi{f}}. It contains all of
the controls and screens necessary for interacting with the device except for
the \hyperref[Touch Sensor]{\cTS{f}} which is located underneath the
\hyperref[Top]{\cTo{f}} of the enclosure.

\begin{figure}[H]
\centering
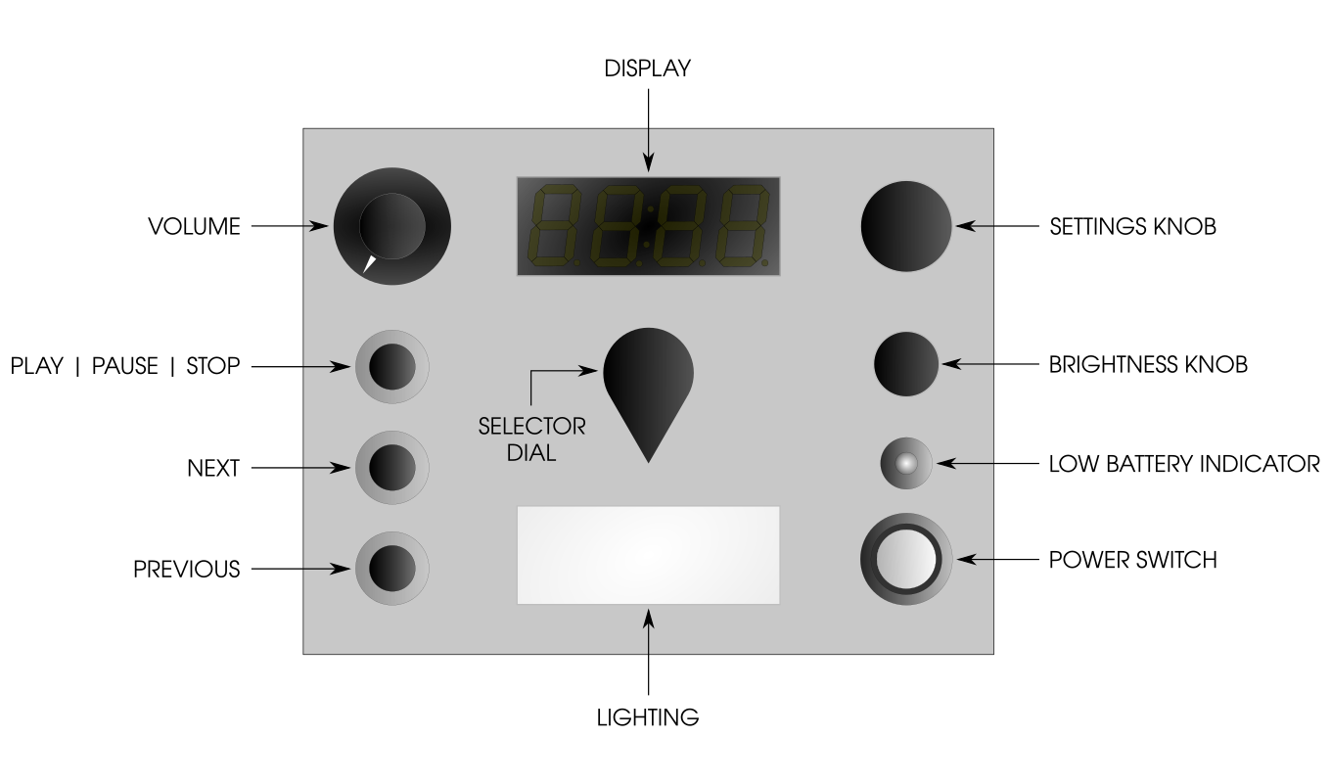
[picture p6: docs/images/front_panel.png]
  
\caption{Front}
\end{figure}

%%%%%%%%%%%%%%%%%%%%%%%%%%%%%%%%%%%%%%%%%%%%%%%%%%%%%%%%%%%%%%%%%%%%%%%%%%%%%%%%
% Front - Power
%%%%%%%%%%%%%%%%%%%%%%%%%%%%%%%%%%%%%%%%%%%%%%%%%%%%%%%%%%%%%%%%%%%%%%%%%%%%%%%%
\section{Power}

%%%%%%%%%%%%%%%%%%%%%%%%%%%%%%%%%%%%%%%%%%%%%%%%%%%%%%%%%%%%%%%%%%%%%%%%%%%%%%%%
% Front - Power - Power Switch
%%%%%%%%%%%%%%%%%%%%%%%%%%%%%%%%%%%%%%%%%%%%%%%%%%%%%%%%%%%%%%%%%%%%%%%%%%%%%%%%
\subsection{Power Switch} \label{Power Switch}

The \cPo{f} is a latching switch used to turn the device \sON{f} and \sOFF{f}.
\begin{itemize}
  \item To turn the device \sON{f}, press inward until you hear a mechanical
    click and feel it lock in place.
  \item To turn the device \sOFF{f}, press inward until you hear a mechanical
    click and feel it release.
\end{itemize}

You can visually tell whether the switch is \sON{f} or \sOFF{f} by whether or
not it is lit.\footnote{ The color of the light may vary.}

\begin{table}[H]
\ers{1}
\centering
\begin{tabu} to 7cm { X[1,c,m] X[1,c,m] }
  \sON{n} & \sOFF{n} \\
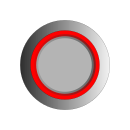
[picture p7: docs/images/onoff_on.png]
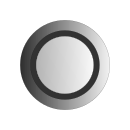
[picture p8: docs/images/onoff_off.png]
   &  \\
\end{tabu}
\caption{Power Switch - ON | OFF Indication}
\end{table}

It will also be flush with the bevel when \sOFF{f} and sunken in when \sON{f}.

\par\medskip

A few items of note:

\begin{itemize}
  \item When the device is plugged in there is no need to switch the device
    \sOFF{f}.
  \item To reduce power consumption when running unplugged, instead of switching
    the device \sOFF{f}, you can:
    \begin{itemize}
      \item Use the \hyperref[Brightness Knob]{\cBr{f}} to blank both the
        \hyperref[Display]{\cDi{f}} and \hyperref[Lighting]{\cLi{f}}.
      \item Use the \hyperref[Play|Pause|Stop]{\cPl{f}} push-button to \sAuSt{f}
        the \hyperref[Audio]{\mAu{f}}.
      \item Set \mPSNa{f}, \mPSSt{f} and/or \mPSSl{f} timers or forcibly put the
        device to sleep using \mPSTo{f} - see \hyperref[Power Settings]{\mPS{f}}
        for configuration and usage.
    \end{itemize}
\end{itemize}

%%%%%%%%%%%%%%%%%%%%%%%%%%%%%%%%%%%%%%%%%%%%%%%%%%%%%%%%%%%%%%%%%%%%%%%%%%%%%%%%
% Front - Power - Low Battery Indicator
%%%%%%%%%%%%%%%%%%%%%%%%%%%%%%%%%%%%%%%%%%%%%%%%%%%%%%%%%%%%%%%%%%%%%%%%%%%%%%%%
\subsection{Low Battery Indicator} \label{Low Battery Indicator}

The \cLB{f} is a red LED and is used to indicate that the device needs to be
recharged.  When the light turns on, the battery charge is getting low.

\begin{table}[H]
\ers{1}
\centering
\begin{tabu} to 6cm { X[1,c,m] X[1,c,m] }
  OK & LOW \\
  
    &  \\
\end{tabu}
\caption{Low Battery Indicator}
\end{table}

Note that when music is playing, the light might flicker on and off. This is
because the electric current varies a great deal when playing audio and a high
volume setting and/or certain sounds (usually low end sounds) can cause the
voltage in the circuit to temporarily drop triggering the \cLB{f}.  Turning
the volume down may get rid of the flicker.  Either way, the battery should
be recharged.

%%%%%%%%%%%%%%%%%%%%%%%%%%%%%%%%%%%%%%%%%%%%%%%%%%%%%%%%%%%%%%%%%%%%%%%%%%%%%%%%
% Front - Screens
%%%%%%%%%%%%%%%%%%%%%%%%%%%%%%%%%%%%%%%%%%%%%%%%%%%%%%%%%%%%%%%%%%%%%%%%%%%%%%%%
\section{Screens}

%%%%%%%%%%%%%%%%%%%%%%%%%%%%%%%%%%%%%%%%%%%%%%%%%%%%%%%%%%%%%%%%%%%%%%%%%%%%%%%%
% Front - Screens - Display
%%%%%%%%%%%%%%%%%%%%%%%%%%%%%%%%%%%%%%%%%%%%%%%%%%%%%%%%%%%%%%%%%%%%%%%%%%%%%%%%
\subsection{Display} \label{Display}

The \cDi{f} is the primary means of conveying information.  It is an LED
\href{https://en.wikipedia.org/wiki/Seven-segment\_display}{Seven-Segment Display}
and can display the full range of numerical digits as well as the majority of
letters.\footnote{ See \hyperref[Display Digits]{Number \& Letter Display Representations}
in the Appendix for a complete list.}  It can also display a decimal point after
each digit and a colon in the middle.

\par\medskip

The brightness of the \cDi{f} is controlled by the
\hyperref[Brightness Knob]{\cBr{f}}.

%%%%%%%%%%%%%%%%%%%%%%%%%%%%%%%%%%%%%%%%%%%%%%%%%%%%%%%%%%%%%%%%%%%%%%%%%%%%%%%%
% Front - Screens - Lighting
%%%%%%%%%%%%%%%%%%%%%%%%%%%%%%%%%%%%%%%%%%%%%%%%%%%%%%%%%%%%%%%%%%%%%%%%%%%%%%%%
\subsection{Lighting} \label{Lighting}

The \cLi{f} is made up of \num{16} RGB LEDs - 2 rows with \num{8} in each row.
A translucent white plastic called Delrin is used to diffuse the light.  Its
primary use is as a night light or timer status indicator.
See \hyperref[Clock]{\mCl{f}} and \hyperref[Timer]{\mTi{f}} respectively for
more information on its use and \hyperref[Set Night Light]{\mSN{f}} for
instructions on setting the \num{3} configurable night light colors.

\par\medskip

The brightness of the \cLi{f} window is controlled by the
\hyperref[Brightness Knob]{\cBr{f}}.

%%%%%%%%%%%%%%%%%%%%%%%%%%%%%%%%%%%%%%%%%%%%%%%%%%%%%%%%%%%%%%%%%%%%%%%%%%%%%%%%
% Front - Screens - Brightness Knob
%%%%%%%%%%%%%%%%%%%%%%%%%%%%%%%%%%%%%%%%%%%%%%%%%%%%%%%%%%%%%%%%%%%%%%%%%%%%%%%%
\subsection{Brightness Knob} \label{Brightness Knob}

The \cBr{f} is an optical rotary encoder and is used to control the brightness
of both the \hyperref[Display]{\cDi{f}} and \hyperref[Lighting]{\cLi{f}}. It
does not have start or stop positions and will turn indefinitely in either
direction.

\begin{itemize}
  \item Turn \textit{clockwise} to \textit{increase} the brightness.
  \item Turn \textit{counter-clockwise} to \textit{decrease} the
    brightness.\footnote{ The \cDi{ss} does not dim seamlessly and you will
    likely notice that it jumps or drops in brightness.  This is normal
    behavior as the hardware only supports \num{16} brightness levels.}
\end{itemize}

Continually turning in one direction or the other will eventually either:

\begin{enumerate}
  \item Reach a \textit{maximum} brightness, or
  \item Blank both the \cDi{f} and \cLi{f}.
\end{enumerate}

\info{When running on battery power and not using the \cDi{f} or \cLi{f} - for
example, if just listening to music - turn the \cBr{f} \textit{counter-clockwise}
until they go blank to prolong battery charge.}

%%%%%%%%%%%%%%%%%%%%%%%%%%%%%%%%%%%%%%%%%%%%%%%%%%%%%%%%%%%%%%%%%%%%%%%%%%%%%%%%
% Front - UI Controls
%%%%%%%%%%%%%%%%%%%%%%%%%%%%%%%%%%%%%%%%%%%%%%%%%%%%%%%%%%%%%%%%%%%%%%%%%%%%%%%%
\section{UI Controls}

The \cRs{f} and \cEs{f} are the primary controls used to interact with the
device and make use of its functionality.

%%%%%%%%%%%%%%%%%%%%%%%%%%%%%%%%%%%%%%%%%%%%%%%%%%%%%%%%%%%%%%%%%%%%%%%%%%%%%%%%
% Front - UI Controls - Selector Dial
%%%%%%%%%%%%%%%%%%%%%%%%%%%%%%%%%%%%%%%%%%%%%%%%%%%%%%%%%%%%%%%%%%%%%%%%%%%%%%%%
\subsection{Selector Dial} \label{Selector Dial}

The \cRs{f} is a \num{3} position, \num{90}° angle rotary switch and is
used to select available operational modes.

\begin{table}[H]
\ers{0.1}
\centering
\begin{tabu}{ c c c }
  \dLe{f} & \dMi{f} & \dRi{f} \\
  \sLe & \sMi & \sRi
\end{tabu}
\caption{Selector Dial Positions}
\end{table}

For information on usage, see \hyperref[Operation - Selector Dial]{\cRs{f}} in
the \hyperref[Operation]{Operation} chapter.

%%%%%%%%%%%%%%%%%%%%%%%%%%%%%%%%%%%%%%%%%%%%%%%%%%%%%%%%%%%%%%%%%%%%%%%%%%%%%%%%
% Front - UI Controls - Settings Knob
%%%%%%%%%%%%%%%%%%%%%%%%%%%%%%%%%%%%%%%%%%%%%%%%%%%%%%%%%%%%%%%%%%%%%%%%%%%%%%%%
\subsection{Settings Knob} \label{Settings Knob}

The \cEs{f} is a combination optical rotary encoder w/ detents \textit{and}
momentary switch which can be both \textit{turned} and \textit{pressed}.  It
does \textit{not} have start or stop positions and will turn indefinitely in
either direction.

\par\medskip

For information on usage, see \hyperref[Operation - Settings Knob]{\cEs{f}} in
the \hyperref[Operation]{Operation} chapter.

%%%%%%%%%%%%%%%%%%%%%%%%%%%%%%%%%%%%%%%%%%%%%%%%%%%%%%%%%%%%%%%%%%%%%%%%%%%%%%%%
% Front - Audio Controls
%%%%%%%%%%%%%%%%%%%%%%%%%%%%%%%%%%%%%%%%%%%%%%%%%%%%%%%%%%%%%%%%%%%%%%%%%%%%%%%%
\section{Audio Controls}

The left side of the front panel is devoted to the \hyperref[Audio]{\mAu{f}}.

%%%%%%%%%%%%%%%%%%%%%%%%%%%%%%%%%%%%%%%%%%%%%%%%%%%%%%%%%%%%%%%%%%%%%%%%%%%%%%%%
% Front - Audio Controls - Volume
%%%%%%%%%%%%%%%%%%%%%%%%%%%%%%%%%%%%%%%%%%%%%%%%%%%%%%%%%%%%%%%%%%%%%%%%%%%%%%%%
\subsection{Volume} \label{Volume}

The \cVo{f} knob is a dual-gang potentiometer and controls the volume level of
the \mAu{f}\footnote{ The \cVo{ss} knob is not connected to the \cBe{ss} so
cannot control its volume.} and has a \textit{white arrow} indicator on the
sleeve.  Unlike the \hyperref[Settings Knob]{\cEs{f}} and
\hyperref[Brightness Knob]{\cBr{f}} it does \textit{not} turn indefinitely and
has physical start and stop positions.

\par\medskip

For usage information, see \hyperref[Audio - Volume]{\cVo{f}} in the
\hyperref[Audio]{\mAu{f}} section.

%%%%%%%%%%%%%%%%%%%%%%%%%%%%%%%%%%%%%%%%%%%%%%%%%%%%%%%%%%%%%%%%%%%%%%%%%%%%%%%%
% Front - Audio Controls - Play|Pause|Stop
%%%%%%%%%%%%%%%%%%%%%%%%%%%%%%%%%%%%%%%%%%%%%%%%%%%%%%%%%%%%%%%%%%%%%%%%%%%%%%%%
\subsection{Play | Pause | Stop} \label{Play|Pause|Stop}

\cPl{f} is a momentary push-button and is used to \sAuPl{f}, \sAuPa{f} and
\sAuSt{f} the \mAu{f}.

\par\medskip

For usage information, see \hyperref[Audio - Play|Pause|Stop]{\cPl{f}} in the
\hyperref[Audio]{\mAu{f}} section.

%%%%%%%%%%%%%%%%%%%%%%%%%%%%%%%%%%%%%%%%%%%%%%%%%%%%%%%%%%%%%%%%%%%%%%%%%%%%%%%%
% Front - Audio Controls - Next
%%%%%%%%%%%%%%%%%%%%%%%%%%%%%%%%%%%%%%%%%%%%%%%%%%%%%%%%%%%%%%%%%%%%%%%%%%%%%%%%
\subsection{Next} \label{Next}

\cNe{f} is a momentary push-button and is used to \sAuSk{f} \textit{forward} one
or more tracks.

\par\medskip

For usage information, see \hyperref[Audio - Next]{\cNe{f}} in the
\hyperref[Audio]{\mAu{f}} section.

%%%%%%%%%%%%%%%%%%%%%%%%%%%%%%%%%%%%%%%%%%%%%%%%%%%%%%%%%%%%%%%%%%%%%%%%%%%%%%%%
% Front - Audio Controls - Previous
%%%%%%%%%%%%%%%%%%%%%%%%%%%%%%%%%%%%%%%%%%%%%%%%%%%%%%%%%%%%%%%%%%%%%%%%%%%%%%%%
\subsection{Previous} \label{Previous}

\cPr{f} is a momentary push-button and is used to \sAuSk{f} \textit{backward}
one or more tracks or \textit{rewind} the current track.

\par\medskip

For usage information, see \hyperref[Audio - Previous]{\cPr{f}} in the
\hyperref[Audio]{\mAu{f}} section.

%%%%%%%%%%%%%%%%%%%%%%%%%%%%%%%%%%%%%%%%%%%%%%%%%%%%%%%%%%%%%%%%%%%%%%%%%%%%%%%%
% Top
%%%%%%%%%%%%%%%%%%%%%%%%%%%%%%%%%%%%%%%%%%%%%%%%%%%%%%%%%%%%%%%%%%%%%%%%%%%%%%%%
\chapter{Top} \label{Top}

Attached to the underside of the \cTo{f} is a \cTS{f} and a \cCC{f} and holder.

\begin{figure}[H]
\centering
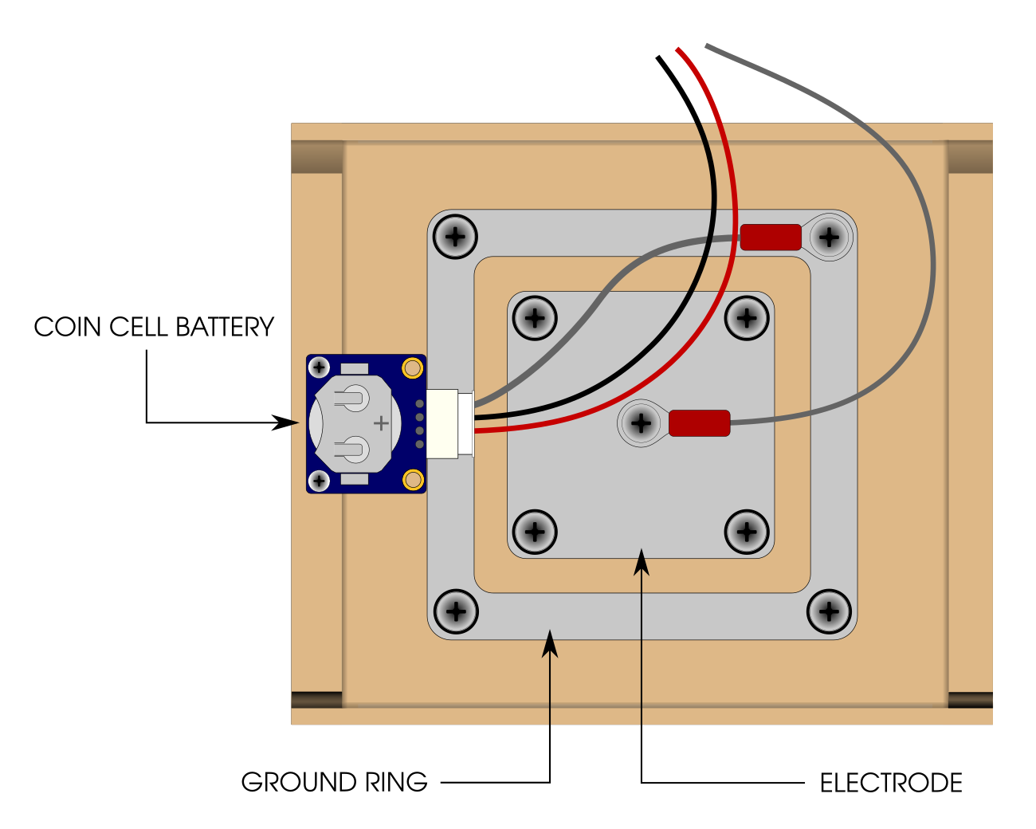
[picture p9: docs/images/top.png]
  
\caption{Top}
\end{figure}

%%%%%%%%%%%%%%%%%%%%%%%%%%%%%%%%%%%%%%%%%%%%%%%%%%%%%%%%%%%%%%%%%%%%%%%%%%%%%%%%
% Top - Touch Sensor
%%%%%%%%%%%%%%%%%%%%%%%%%%%%%%%%%%%%%%%%%%%%%%%%%%%%%%%%%%%%%%%%%%%%%%%%%%%%%%%%
\section{Touch Sensor} \label{Touch Sensor}

The \cTS{f}, also called an \textit{electrode}, is made of a \num{2$\times$2}
inch square of \mono{1/32"} thick aluminum with a wire running to the
microcontroller.  Around the electrode is an aluminum ground ring.

\par\medskip

For more information, see \hyperref[Operation - Touch Sensor]{\cTS{f}} in the
\hyperref[Operation]{Operation} chapter and \hyperref[Touch Settings]{\mTS{f}}
for how to enable and configure the touch capability of the device.

%%%%%%%%%%%%%%%%%%%%%%%%%%%%%%%%%%%%%%%%%%%%%%%%%%%%%%%%%%%%%%%%%%%%%%%%%%%%%%%%
% Top - Coin Cell Battery
%%%%%%%%%%%%%%%%%%%%%%%%%%%%%%%%%%%%%%%%%%%%%%%%%%%%%%%%%%%%%%%%%%%%%%%%%%%%%%%%
\section{Coin Cell Battery} \label{Coin Cell Battery}

The \cCC{f} is a \mono{3\thinspace V} \mono{CR2032} Lithium battery and is used
to keep the date and time updated when the device is switched \sOFF{f} via the
\hyperref[Power Switch]{\cPo{f}} and otherwise unpowered.  It is attached on the
left side just underneath the \cTo{f}.  It is \textit{not} rechargeable,
however, it should last for a number of years before needing replacement.  You
will know it needs replacing if the date and time are not correct when switching
the device \sON{f} (assuming they were correct before switching the device
\sOFF{f}).  For more information see
\hyperref[Replacing Battery]{Replacing the Coin Cell Battery}.

%%%%%%%%%%%%%%%%%%%%%%%%%%%%%%%%%%%%%%%%%%%%%%%%%%%%%%%%%%%%%%%%%%%%%%%%%%%%%%%%
% Bottom
%%%%%%%%%%%%%%%%%%%%%%%%%%%%%%%%%%%%%%%%%%%%%%%%%%%%%%%%%%%%%%%%%%%%%%%%%%%%%%%%
\chapter{Bottom} \label{Bottom}

The \cBo{f} holds and secures the \cRB{f}.

\begin{figure}[H]
\centering
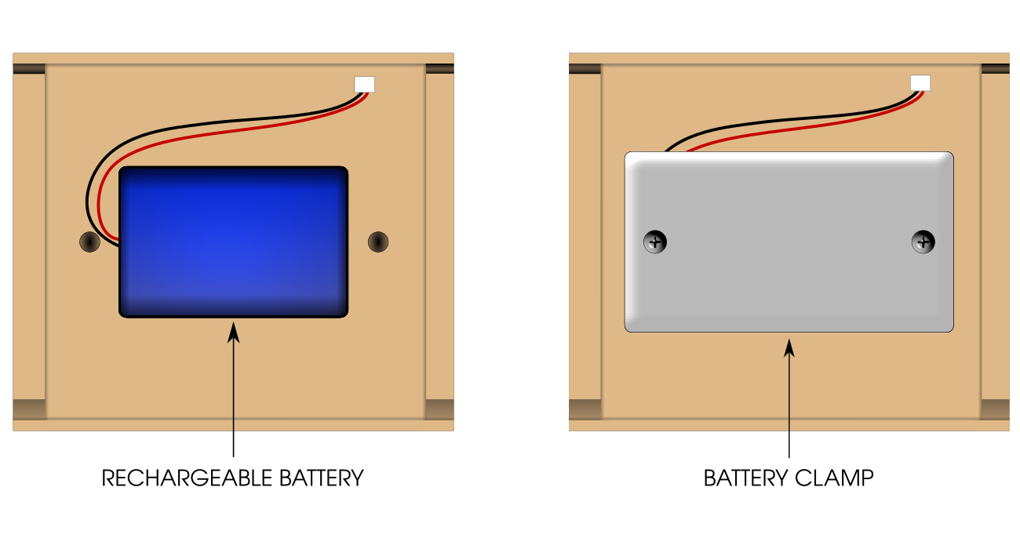
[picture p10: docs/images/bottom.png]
  
\caption{Bottom}
\end{figure}

%%%%%%%%%%%%%%%%%%%%%%%%%%%%%%%%%%%%%%%%%%%%%%%%%%%%%%%%%%%%%%%%%%%%%%%%%%%%%%%%
% Bottom - Rechargeable Battery
%%%%%%%%%%%%%%%%%%%%%%%%%%%%%%%%%%%%%%%%%%%%%%%%%%%%%%%%%%%%%%%%%%%%%%%%%%%%%%%%
\section{Rechargeable Battery} \label{Rechargeable Battery}

The \cRB{f} is a nominal \mono{3.7\thinspace V}, \mono{6600\thinspace mAh}
Lithium Ion battery pack.  It is the primary power source when the device is
unplugged and switched \sON{f}.  With music playing, the charge should last
about a day.

%%%%%%%%%%%%%%%%%%%%%%%%%%%%%%%%%%%%%%%%%%%%%%%%%%%%%%%%%%%%%%%%%%%%%%%%%%%%%%%%
% Sides
%%%%%%%%%%%%%%%%%%%%%%%%%%%%%%%%%%%%%%%%%%%%%%%%%%%%%%%%%%%%%%%%%%%%%%%%%%%%%%%%
\chapter{Sides} \label{Sides}

The \cSi{f} house the speakers and are where the screws that secure the
enclosure are.

\begin{figure}[H]
\centering
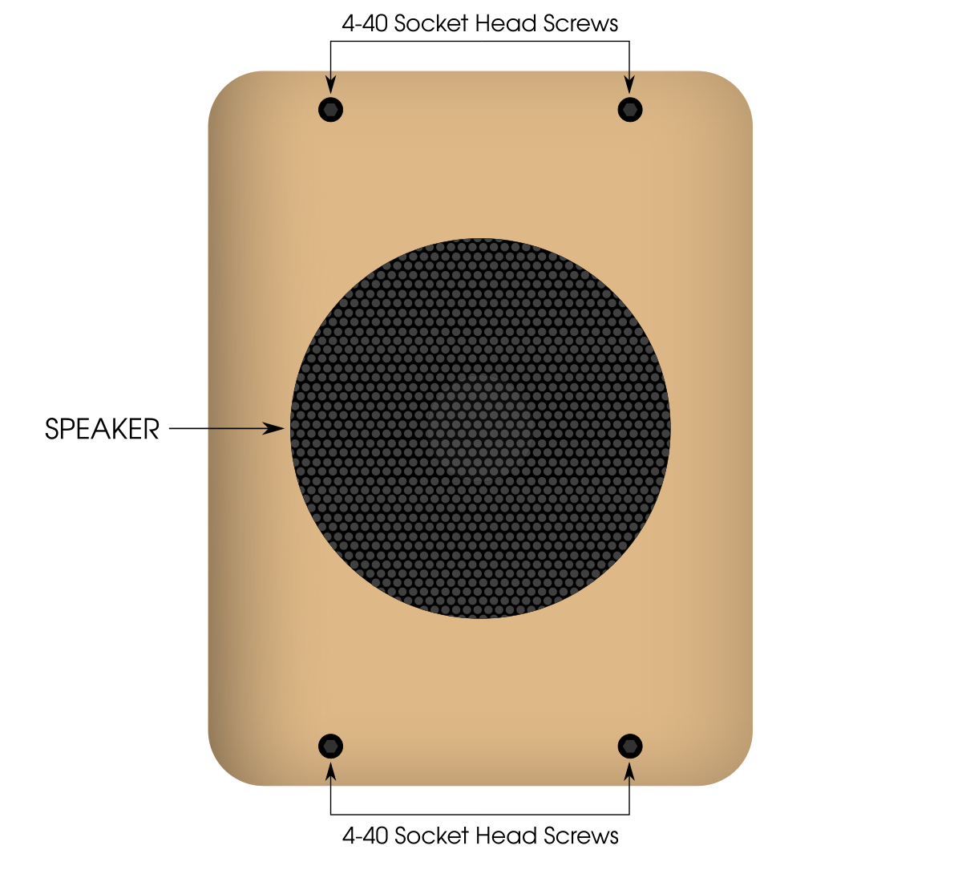
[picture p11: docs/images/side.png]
  
\caption{Side}
\end{figure}

%%%%%%%%%%%%%%%%%%%%%%%%%%%%%%%%%%%%%%%%%%%%%%%%%%%%%%%%%%%%%%%%%%%%%%%%%%%%%%%%
% Sides - Speakers
%%%%%%%%%%%%%%%%%%%%%%%%%%%%%%%%%%%%%%%%%%%%%%%%%%%%%%%%%%%%%%%%%%%%%%%%%%%%%%%%
\section{Speakers} \label{Speakers}

The \num{2} speakers, one on each side, are \mono{8\thinspace\small{$\Omega$}},
\mono{2\thinspace W}, \mono{99\thinspace dB} with paper cone and ferrite magnet.
They are used in conjunction with the \hyperref[Audio]{\mAu{f}}.  The grills are
made of \mono{1/32"} inch, \num{24} gauge perforated \num{304} stainless steel,
painted black.

%%%%%%%%%%%%%%%%%%%%%%%%%%%%%%%%%%%%%%%%%%%%%%%%%%%%%%%%%%%%%%%%%%%%%%%%%%%%%%%%
% Sides - Fastening Screws
%%%%%%%%%%%%%%%%%%%%%%%%%%%%%%%%%%%%%%%%%%%%%%%%%%%%%%%%%%%%%%%%%%%%%%%%%%%%%%%%
\section{Fastening Screws} \label{Fastening Screws}

The screws used to keep the enclosure together are \mono{4-40} Socket Head
screws made of Black-Oxide Alloy Steel and have a \mono{3/32"} hex wrench drive
size.  There are a total of \num{8} screws with \num{4} on each side.

\warning{Before taking the enclosure apart, please refer to
\hyperref[Disassembly]{Disassembly}.}

A \mono{3/32"} \hyperref[Hex Driver]{Hex Driver} is included for the purpose
of removing and replacing these screws.  The use of a straight driver as
opposed to a bent key is recommended in order to lessen the possibility of
scraping the finish on the wood.

%%%%%%%%%%%%%%%%%%%%%%%%%%%%%%%%%%%%%%%%%%%%%%%%%%%%%%%%%%%%%%%%%%%%%%%%%%%%%%%%
% Back
%%%%%%%%%%%%%%%%%%%%%%%%%%%%%%%%%%%%%%%%%%%%%%%%%%%%%%%%%%%%%%%%%%%%%%%%%%%%%%%%
\chapter{Back} \label{Back}

On the \cBa{f} of the device is the \cPP{f} that is used for adding/removing
songs to/from the device and to both power the device and charge the
\hyperref[Rechargeable Battery]{\cRB{f}} inside.

\begin{figure}[H]
\centering
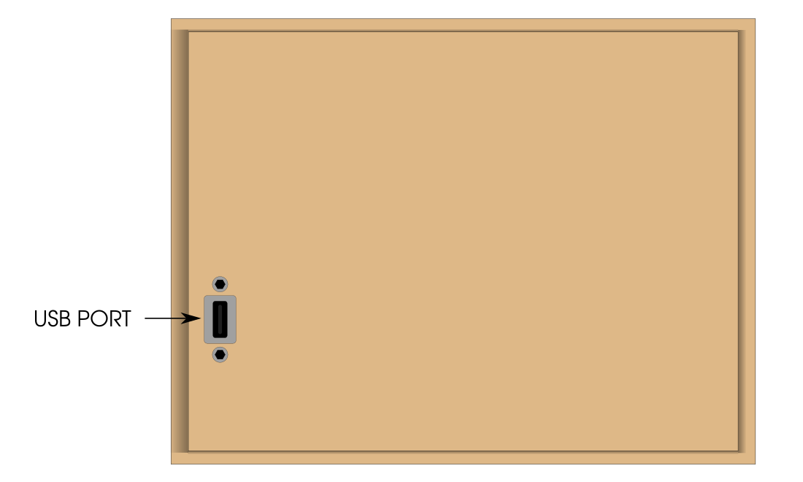
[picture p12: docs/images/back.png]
  
\caption{Back}
\end{figure}

The main circuit board is attached on the inside.  Of interest are
the \cBe{f} and removable \cMSD{f}.

\begin{figure}[H]
\centering
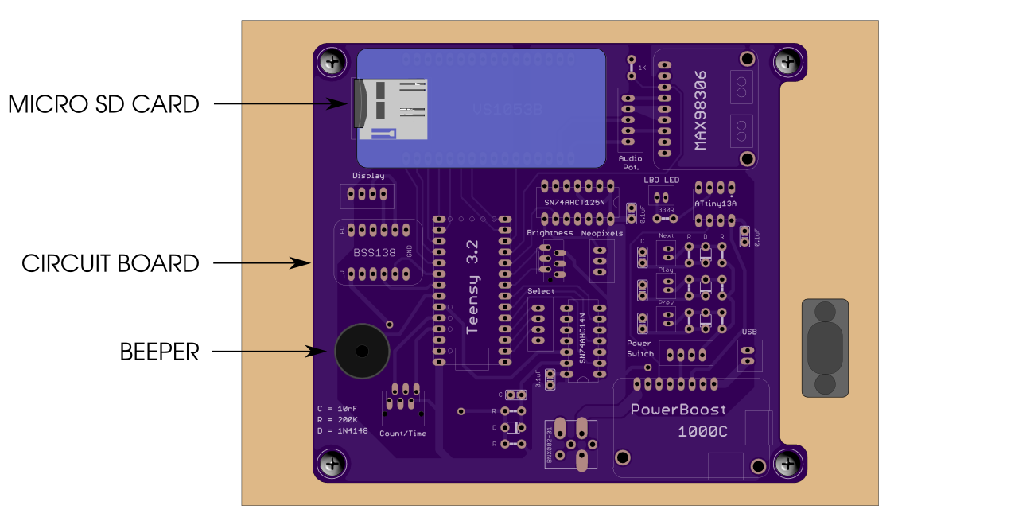
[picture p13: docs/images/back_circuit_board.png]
  
\caption{Back - Circuit Board}
\end{figure}

%%%%%%%%%%%%%%%%%%%%%%%%%%%%%%%%%%%%%%%%%%%%%%%%%%%%%%%%%%%%%%%%%%%%%%%%%%%%%%%%
% Back - USB Port
%%%%%%%%%%%%%%%%%%%%%%%%%%%%%%%%%%%%%%%%%%%%%%%%%%%%%%%%%%%%%%%%%%%%%%%%%%%%%%%%
\section{USB Port} \label{USB Port}

The \cPP{f} is a \cUSB{f} port that allows for both data transfer and power
to the device.

\par\medskip

A few items of note:

\begin{itemize}
  \item When connected to a computer, make sure the device is ``ejected'' before
    unplugging the \hyperref[USB Cable]{\cUsb{f}}.
  \item The device can be \sON{f} or \sOFF{f} when plugging or unplugging the
    \hyperref[Power Adapter]{\cPA{f}} or \hyperref[USB Cable]{\cUsb{f}}.
  \item The device can be \sON{f} or \sOFF{f} while charging.
  \item The device is fully functional while charging.
  \item The device never has to be unplugged.\footnote{ It should be unplugged
    when \hyperref[Cleaning]{cleaning} and
    \hyperref[Disassembly]{disassembling}.}
\end{itemize}

See \hyperref[Powering and Recharging]{Powering \& Recharging} and the
\hyperref[USB]{USB} sections for more information.

\danger{Always eject the device before unplugging it from a computer to
avoid possible filesystem corruption.}

%%%%%%%%%%%%%%%%%%%%%%%%%%%%%%%%%%%%%%%%%%%%%%%%%%%%%%%%%%%%%%%%%%%%%%%%%%%%%%%%
% Back - Beeper
%%%%%%%%%%%%%%%%%%%%%%%%%%%%%%%%%%%%%%%%%%%%%%%%%%%%%%%%%%%%%%%%%%%%%%%%%%%%%%%%
\section{Beeper} \label{Beeper}

The \cBe{f} is a \mono{2.3\thinspace kHz} magnetic single tone buzzer and is
used with the \hyperref[Alarm]{\mAl{f}}, \hyperref[Timer]{\mTi{f}} and
\hyperref[Touch Settings]{\mTS{f}}.  Note, it will always sound at the same
volume since the \cVo{f} control is not connected to it and can \textit{not}
adjust it.

\par\medskip

There are two symbols used to reference the \cBe{f} that are used in later
sections.

\begin{table}[H]
\ers{2}
\centering
\begin{tabu}{X[1,c,m] | X[5,l,m]}
  \thrule
  \thbi{Symbol} & \thbi{Meaning} \\ \mrule
  \sBe & The \cBe{f} is making sound, i.e. beeping. \\ \drule{2}
  \sNBe & The \cBe{f} is mute, i.e. \textit{not} beeping. \\
  \bhrule
\end{tabu}
\end{table}

%%%%%%%%%%%%%%%%%%%%%%%%%%%%%%%%%%%%%%%%%%%%%%%%%%%%%%%%%%%%%%%%%%%%%%%%%%%%%%%%
% Back - Micro SD Card
%%%%%%%%%%%%%%%%%%%%%%%%%%%%%%%%%%%%%%%%%%%%%%%%%%%%%%%%%%%%%%%%%%%%%%%%%%%%%%%%
\section{Micro SD Card} \label{Micro SD Card}

The \cMSD{f} is used as storage for the songs on the device.  The \cMSD{f} that
comes preinstalled with the device has a read speed of at least
\num{90} \mono{MB/sec} and is formatted with the \mono{FAT32} filesystem using
\num{512} bytes per sector.

%%%%%%%%%%%%%%%%%%%%%%%%%%%%%%%%%%%%%%%%%%%%%%%%%%%%%%%%%%%%%%%%%%%%%%%%%%%%%%%%
% Accessories
%%%%%%%%%%%%%%%%%%%%%%%%%%%%%%%%%%%%%%%%%%%%%%%%%%%%%%%%%%%%%%%%%%%%%%%%%%%%%%%%
\chapter{Accessories} \label{Accessories}

%%%%%%%%%%%%%%%%%%%%%%%%%%%%%%%%%%%%%%%%%%%%%%%%%%%%%%%%%%%%%%%%%%%%%%%%%%%%%%%%
% Accessories - Hex Driver
%%%%%%%%%%%%%%%%%%%%%%%%%%%%%%%%%%%%%%%%%%%%%%%%%%%%%%%%%%%%%%%%%%%%%%%%%%%%%%%%
\section{Hex Driver} \label{Hex Driver}

A \mono{3/32"} hex driver is included for the purpose of removing and replacing
the \hyperref[Fastening Screws]{Fastening Screws} that hold the enclosure
together.

\begin{figure}[H]
\centering
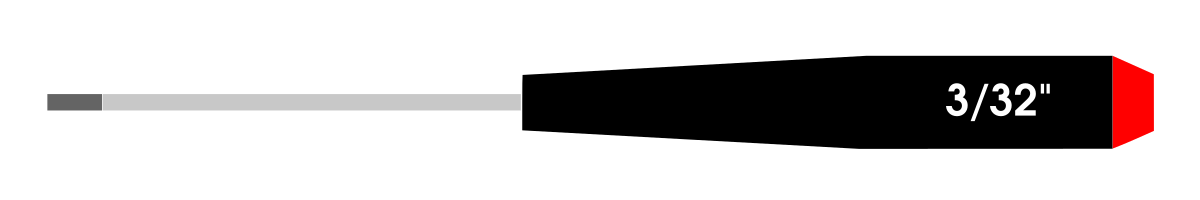
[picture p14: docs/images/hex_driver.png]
  
\caption{3/32" Hex Driver}
\end{figure}

\warning{Before taking the enclosure apart, please refer to
\hyperref[Disassembly]{Disassembly}.}

%%%%%%%%%%%%%%%%%%%%%%%%%%%%%%%%%%%%%%%%%%%%%%%%%%%%%%%%%%%%%%%%%%%%%%%%%%%%%%%%
% Accessories - Power Adapter
%%%%%%%%%%%%%%%%%%%%%%%%%%%%%%%%%%%%%%%%%%%%%%%%%%%%%%%%%%%%%%%%%%%%%%%%%%%%%%%%
\section{Power Adapter} \label{Power Adapter}

The \cPA{f} is used to both power the device
and charge the \hyperref[Rechargeable Battery]{\cRB{f}}.  It is a
\mono{5.25\thinspace V}, \mono{2.4\thinspace A} switching AC/DC power adapter
that terminates with a \cUSB{f} connector that plugs into the
\hyperref[USB Port]{\cPP{f}}.  It can accept either \num{110} or \num{240}
\mono{VAC} mains so works in the US as well as other countries.

\par\medskip

If this needs to be replaced, the replacement \textit{must} be a
\mono{5\thinspace V} AC/DC adapter (or \mono{5.25\thinspace V} if you can find
one).

\danger{An adapter that is \mono{6\thinspace V}, \mono{9\thinspace V},
\mono{12\thinspace V} or above \textit{will} damage the device.}

\warning{An adapter that is less than \mono{5\thinspace V} will not be able to
power the device and it \textit{will} malfunction.}

The adapter should be rated for at least \mono{1\thinspace A} and no more than
\mono{2.5\thinspace A}.

%%%%%%%%%%%%%%%%%%%%%%%%%%%%%%%%%%%%%%%%%%%%%%%%%%%%%%%%%%%%%%%%%%%%%%%%%%%%%%%%
% Accessories - Usb Cable
%%%%%%%%%%%%%%%%%%%%%%%%%%%%%%%%%%%%%%%%%%%%%%%%%%%%%%%%%%%%%%%%%%%%%%%%%%%%%%%%
\section{USB Cable} \label{USB Cable}

The \cUsb{f} is a \textit{USB 2.0 Standard Type-A Male to Micro Type-B Male}.
Its primary use is to provide connectivity between a personal computer or
laptop and the device in order to manage the songs that can be played on the
device.  It can also be used to power and charge the device though the charge
rate will be significantly slower compared to using the \cPA{f}.

\begin{figure}[H]
\centering
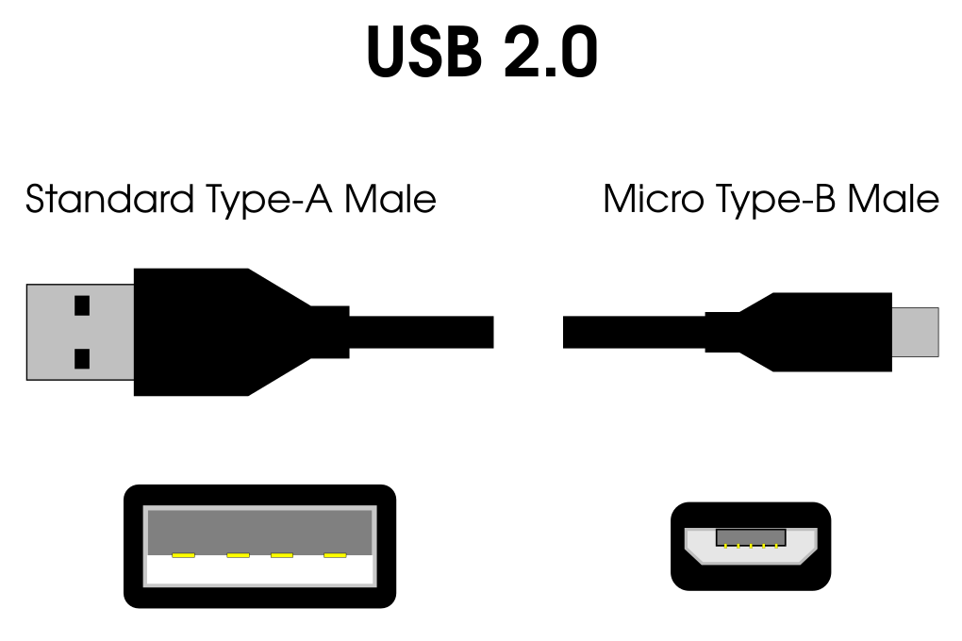
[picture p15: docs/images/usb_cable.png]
  
\caption{USB 2.0 Standard Type-A Male to Micro Type-B Male}
\end{figure}

\info{The cable must be a USB 2.0 cable and \textbf{not} a USB 3.0 cable and
must be a \textit{USB 2.0 Standard Type-A Male to Micro Type-B Male}.}

\info{There is also a USB 2.0 Mini connector that is similar in appearance to
the USB 2.0 Micro.  A USB Mini connector will \textbf{not} fit in the \cPP{f}.}

%%%%%%%%%%%%%%%%%%%%%%%%%%%%%%%%%%%%%%%%%%%%%%%%%%%%%%%%%%%%%%%%%%%%%%%%%%%%%%%%
% Powering & Recharging
%%%%%%%%%%%%%%%%%%%%%%%%%%%%%%%%%%%%%%%%%%%%%%%%%%%%%%%%%%%%%%%%%%%%%%%%%%%%%%%%
\chapter{Powering \& Recharging} \label{Powering and Recharging}

The device can be both powered and charged using either the supplied
\hyperref[Power Adapter]{\cPA{f}} or \hyperref[USB Cable]{\cUsb{f}}.

\par\medskip

\cUSB{f} is asymmetric and can only be plugged in one way.

\begin{figure}[H]
\centering
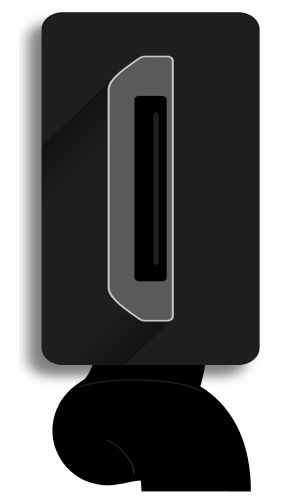
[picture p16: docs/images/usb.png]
  
\caption{USB 2.0 Micro-B}
\end{figure}

The figure below indicates how the \cUSB{f} plug should be oriented when
\textit{facing} the \hyperref[USB Port]{\cPP{f}}.

\begin{figure}[H]
\centering
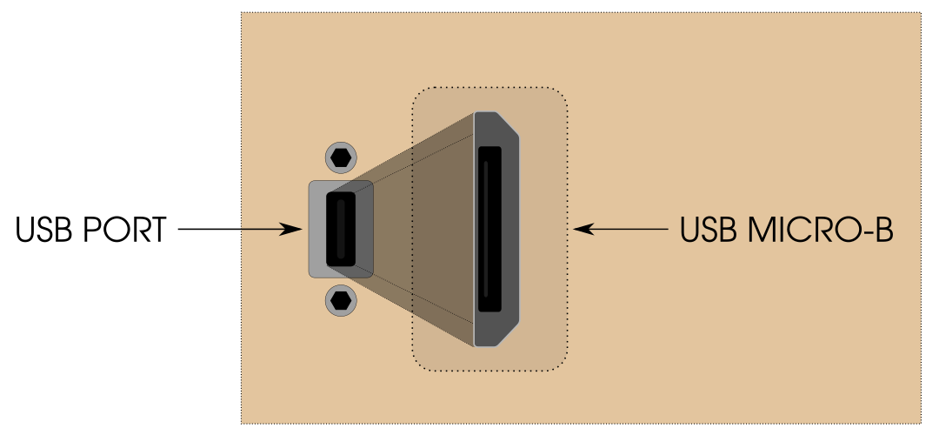
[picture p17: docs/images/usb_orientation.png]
  
\caption{USB 2.0 Micro-B $\longrightarrow$ USB Port Orientation}
\end{figure}

Using the \hyperref[Power Adapter]{\cPA{f}}, plug the \cUSB{f} end into the
\cPP{f} on the \cBa{f} of the device and the 2-prong end into a wall or power
strip receptacle.

\par\medskip

Using the \hyperref[USB Cable]{\cUsb{f}}, connect the Micro-B end into the
\cPP{f} on the device and the Standard Type-A end into a USB port on a computer
or USB hub.

%%%%%%%%%%%%%%%%%%%%%%%%%%%%%%%%%%%%%%%%%%%%%%%%%%%%%%%%%%%%%%%%%%%%%%%%%%%%%%%%
% Powering & Recharging - Recharging
%%%%%%%%%%%%%%%%%%%%%%%%%%%%%%%%%%%%%%%%%%%%%%%%%%%%%%%%%%%%%%%%%%%%%%%%%%%%%%%%
\section{Recharging} \label{Recharging}

The \hyperref[Low Battery Indicator]{\cLB{f}} will light up when the device
needs to be recharged.  Unfortunately there is no way to indicate that the
battery has finished charging.

\par\medskip

Using the \hyperref[Power Adapter]{\cPA{f}}, it should take about \num{8} hours
to charge if the \hyperref[Low Battery Indicator]{\cLB{f}} is signaling - plug
it in before going to bed and it should be charged by the time you wake up.

\par\medskip

Using the \hyperref[USB Cable]{\cUsb{f}}, charging will likely take longer since
USB ports on a computer generally do not supply as much current as the
\hyperref[Power Adapter]{\cPA{f}} will.

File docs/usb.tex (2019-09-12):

%%%%%%%%%%%%%%%%%%%%%%%%%%%%%%%%%%%%%%%%%%%%%%%%%%%%%%%%%%%%%%%%%%%%%%%%%%%%%%%%
% USB
%%%%%%%%%%%%%%%%%%%%%%%%%%%%%%%%%%%%%%%%%%%%%%%%%%%%%%%%%%%%%%%%%%%%%%%%%%%%%%%%
\chapter{USB} \label{USB}
\vspace{-10ex}\mUsb{syml}\vskip 8ex

%%%%%%%%%%%%%%%%%%%%%%%%%%%%%%%%%%%%%%%%%%%%%%%%%%%%%%%%%%%%%%%%%%%%%%%%%%%%%%%%
% Introduction
%%%%%%%%%%%%%%%%%%%%%%%%%%%%%%%%%%%%%%%%%%%%%%%%%%%%%%%%%%%%%%%%%%%%%%%%%%%%%%%%
\section{Introduction}

Connecting the device to a computer allows one to manage the files that are
stored on the device.

%%%%%%%%%%%%%%%%%%%%%%%%%%%%%%%%%%%%%%%%%%%%%%%%%%%%%%%%%%%%%%%%%%%%%%%%%%%%%%%%
% USB - State Diagram
%%%%%%%%%%%%%%%%%%%%%%%%%%%%%%%%%%%%%%%%%%%%%%%%%%%%%%%%%%%%%%%%%%%%%%%%%%%%%%%%
\section{State Diagram} \label{USB - State Diagram}

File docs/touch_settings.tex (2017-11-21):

%%%%%%%%%%%%%%%%%%%%%%%%%%%%%%%%%%%%%%%%%%%%%%%%%%%%%%%%%%%%%%%%%%%%%%%%%%%%%%%%
% Touch Settings
%%%%%%%%%%%%%%%%%%%%%%%%%%%%%%%%%%%%%%%%%%%%%%%%%%%%%%%%%%%%%%%%%%%%%%%%%%%%%%%%
\chapter{Touch Settings} \label{Touch Settings}
\vspace{-10ex}\mTS{syml}\vskip 8ex

%%%%%%%%%%%%%%%%%%%%%%%%%%%%%%%%%%%%%%%%%%%%%%%%%%%%%%%%%%%%%%%%%%%%%%%%%%%%%%%%
% Introduction
%%%%%%%%%%%%%%%%%%%%%%%%%%%%%%%%%%%%%%%%%%%%%%%%%%%%%%%%%%%%%%%%%%%%%%%%%%%%%%%%
\section{Introduction}

Allows for configuring, calibrating and testing the touch sensing capability of
the device.  It can also be disabled here.

\par\medskip

In this mode, the main goal is to come up with a number called a \textit{touch
threshold}.  When a reading is taken, if its value is greater than the threshold,
a touch event is registered.  It's recommended that you first select the
\mTSCa{f} menu option and follow the instructions for that.  If you are unable
to get a consistent beep without chirping when touching during \sTSTA{f}, try
the \mTSRe{f} method, then the \mTSCo{f} method.  If nothing good comes of any
of these, you can load the \mTSDe{f} and try again or simply \mTSDi{f} touch
altogether.  Most everything that can be done using touch can be done using
other means.  There are a few exceptions:

\begin{itemize}
  \item Forcibly putting the device to sleep -
    see \hyperref[Power Settings - Touch]{Touch} in
    \hyperref[Power Settings]{\mPS{f}} and \hyperref[Power - Touch]{Touch Sleep}
    in \hyperref[Power]{\mPo{f}}.
  \item Toggling the timer lighting - see \hyperref[Timer - Lighting]{Lighting}
    in \hyperref[Timer]{\mTi{f}}.
\end{itemize}

It is the \mTe{f} mode when the \cRs{f} is in the \dLe{f} position.

\par\medskip

There are a few ways to get to \mTS{f} depending on which direction the \cRs{f}
is pointing and which mode the device is currently in.  The most straightforward
way is:

\begin{enumerate}
  \item \aTu{f} the \cRs{f} to the \dLe{f}.
  \item \aPH{f} the \cEs{f} until \symD{>>>>} is blinking on the
    \cDi{f} then \aRe{f}.
\end{enumerate}

\begin{table}[H]
\ers{1}
\centering
\begin{tabu} { X[1,c,m] | X[2,c,m] | X[1,c,m] }
  \thrule
  \thbi{Position} & \thbi{Mode} & \thbi{Action} \\ \mrule

  \sMi & \multirow{2}{*}[-1.5mm]{\mode{s}{ANY}}
    & $\hskip -5mm$ \sMtoL \\ \dcrule{1}{1} \dcrule{3}{3}
  \sRi & & \sRtoL \\ \mdrule

  \multirow{2}{*}[-1.5mm]{\sLe} & \mSA{sym}
    & \multirow{2}{*}[-1.5mm]{\sTer} \\ \dcrule{2}{2}
    & \mSC{sym} & \\

  \bhrule
\end{tabu}
\caption{Touch Settings - Mode}
\end{table}

%%%%%%%%%%%%%%%%%%%%%%%%%%%%%%%%%%%%%%%%%%%%%%%%%%%%%%%%%%%%%%%%%%%%%%%%%%%%%%%%
% Capacitive Touch Sensing
%%%%%%%%%%%%%%%%%%%%%%%%%%%%%%%%%%%%%%%%%%%%%%%%%%%%%%%%%%%%%%%%%%%%%%%%%%%%%%%%
\section{Capacitive Touch Sensing}

The touch capability in this device uses
\href{https://en.wikipedia.org/wiki/Capacitive\_sensing}{Capacitive Touch Sensing}
which measures changes in capacitance of an \textit{electrode} to detect touch
events.  The figure below shows how it is modeled as a capacitor and the
corresponding parts of the device.

\begin{figure}[H]
\centering
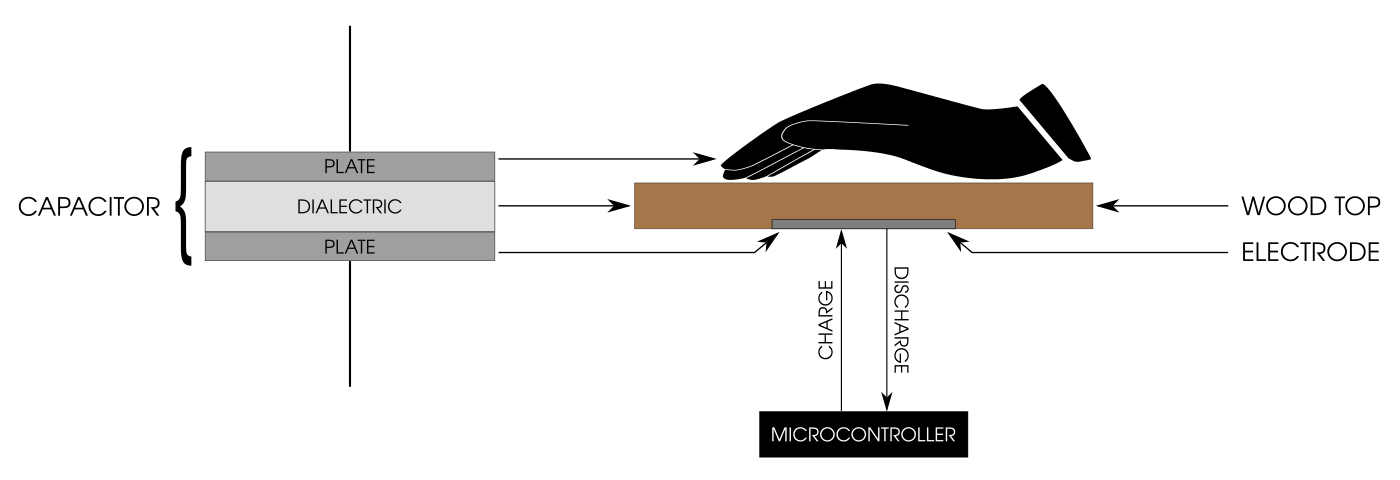
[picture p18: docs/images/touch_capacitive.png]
  
\caption{Capacitive Touch Sensing}
\end{figure}

Since humans are electrical conductors, the hand forms the other plate of the
capacitor model.  As the hand approaches and lies on \cTo{f} of the enclosure,
the capacitance, or charge capacity of the electrode will \textit{increase}.

\par\medskip

Changes in capacitance are detected by measuring the amount of time it takes to
charge and discharge the electrode.

\par\medskip

When a reading is taken, a fixed size reference capacitor is charged and
discharged using a configurable charge rate denoted as \sTSRC{f}.  At the same
time, the electrode is charged and discharged a set number of times using
another configurable charge rate denoted as \sTSEC{f}.  Since its capacitance
does \textit{not} change, the fixed size capacitor provides a \textit{reference} and will
always charge\slash discharge at the same rate.  On the other hand, the
electrode capacitance \textit{varies}, so its charge\slash discharge rate will
vary.  The number of times the electrode is charged\slash discharged or
\textit{scanned} per reading is determined by two configurable quantities
denoted as \sTSNS{f} and \sTSPS{f}.  \sTSNS{f} is a base
\textit{number of scans} and \sTSPS{f} is a \textit{prescaler} or multiplier
applied to \sTSNS{f}.  The product of the two determines the number of times the
electrode is charged\slash discharged during a reading.

\begin{figure}[H]
\centering
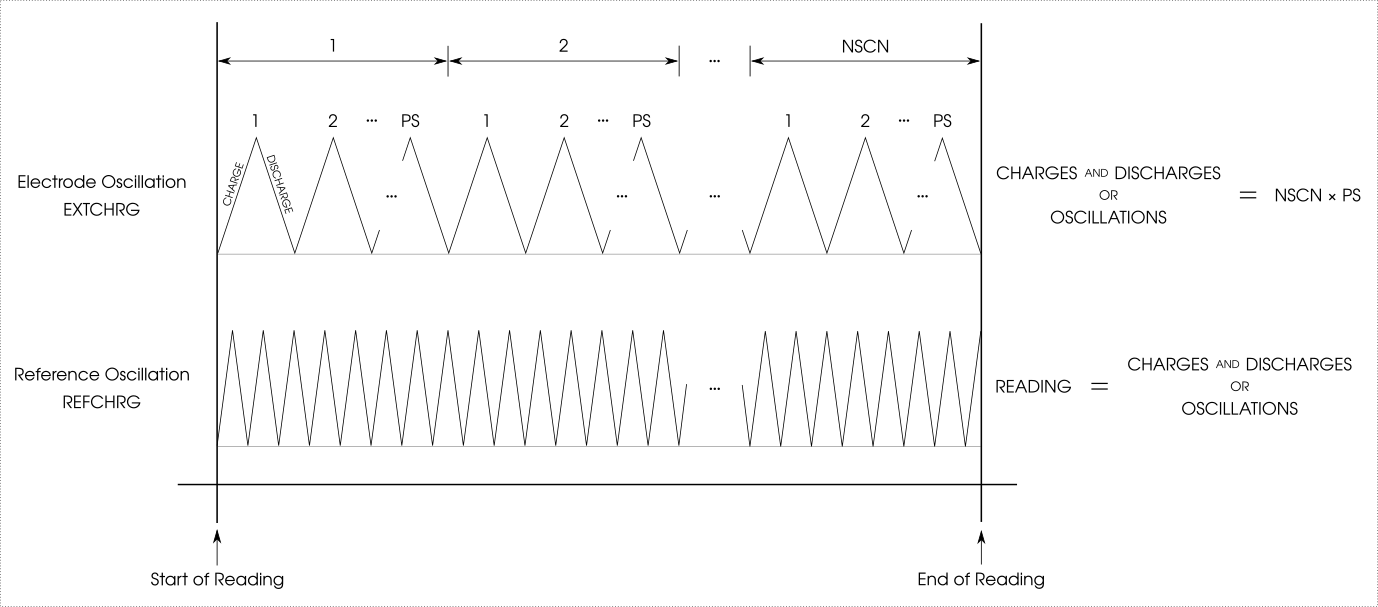
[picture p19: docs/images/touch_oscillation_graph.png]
  
\caption{Anatomy of a Touch Sensor Reading}
\end{figure}

As the hand approaches the electrode, the capacitance \textit{increases} resulting in
more time required to charge and discharge the electrode.  This increase in time
or decreased frequency results in more reference capacitor charges and
discharges per electrode charge\slash discharge resulting in a higher reading.

\par\medskip

As an analogy, consider the filling and draining of a bath tub - the larger the
tub, the longer it will take to fill it up and to drain it.  Think of the
electrode as a bath tub that increases in size when touched therefore taking
longer to fill and drain.  This increase in fill\slash drain time of the
electrode when touched means that the fixed size reference capacitor - a bath
tub that doesn't change in size - can be filled and drained more times per
electrode fill and drain.

\par\medskip

The \fontTGA{f}{READING} taken is basically the number of times it takes to fill
and drain the fixed size reference capacitor per electrode fill and drain cycle
- the cycle being defined as \sTSNS{f} $\times$ \sTSPS{f}.

\par\medskip

Below are two graphs that illustrate the capacitance difference and how it is
measured.  The first illustrates a reading taken when \textit{not touched} and
the second when \textit{touched}.  This example uses $\textrm{\sTSNS{f}} = 3$
and $\textrm{\sTSPS{f}} = 2$, so the number of electrode scans per reading is:
$\textrm{\sTSNS{f}} \times \textrm{\sTSPS{f}} = 6$.

\begin{figure}[H]
\centering
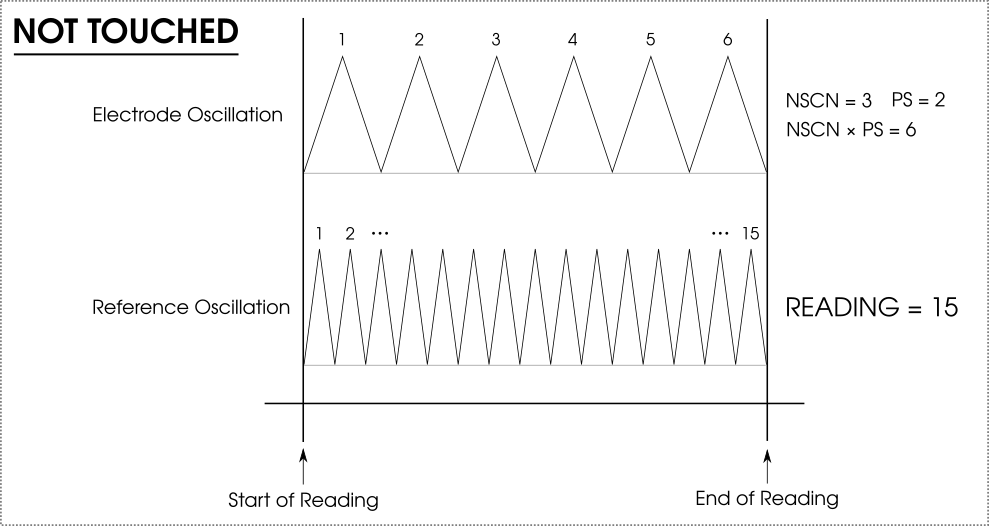
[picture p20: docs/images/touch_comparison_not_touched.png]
  
\caption{Touch Reading Comparison - Not Touched}
\end{figure}

\begin{figure}[H]
\centering
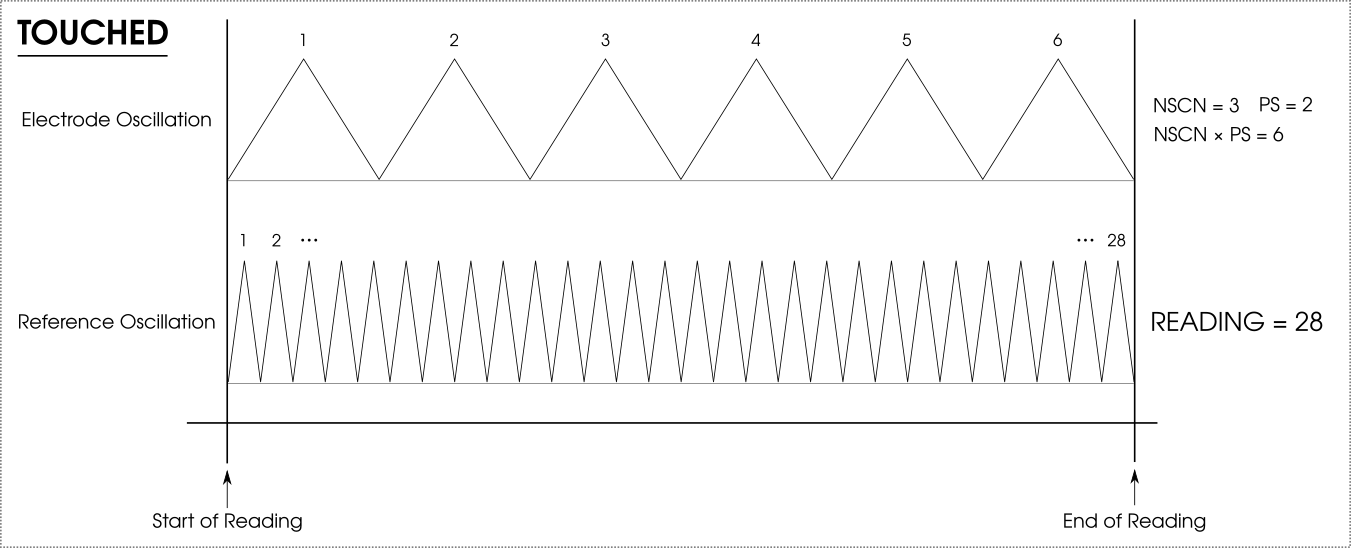
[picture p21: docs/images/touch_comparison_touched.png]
  
\caption{Touch Reading Comparison - Touched}
\end{figure}

When touched, the higher capacitance created means that it will take longer to
charge and discharge the electrode.  This results in more reference
charges/discharges or oscillations and therefore a higher reading.

\par\medskip

Despite the fact that a reading can be calculated, the device still has to be
told when a reading should be considered as a legitimate touch event.  As
initially mentioned, the main goal of \mTS{f} is to come up with a \textit{touch
threshold} value.  This is a value for which a touch event is registered
when the value of a reading equals or exceeds it.

\par\medskip

In the above example, if the threshold value was between \num{16} and \num{28}
inclusive, a touch event would \textit{not} have been registered in the
\fontTGA{f}{NOT TOUCHED} case and \textit{would} have been registered in the
\fontTGA{f}{TOUCHED} case, as expected.

\par\medskip

However, if the threshold value was set to \num{15} or less, a touch event
\textit{would} have been registered in the \fontTGA{f}{NOT TOUCHED} case as well
as the \fontTGA{f}{TOUCHED} case.  And if the threshold value was greater than
\num{28}, \textit{no} touch event would have be registered in either case.
These outcomes are unexpected and undesirable.

\par\medskip

The preceding explanation of how capacitive touch sensing works on this device is
simplified and idealized.  The reality is that readings will fluctuate.  It's
possible that readings may differ when the device is in different locations or
environmental conditions.  Additionally, when touching, readings will vary based
on how much of the hand is covering the electrode and how much force is used.
Keep this in mind during the \sTSTA{f} phase when setting the final threshold
value.  Try not to choose a value on the edge, but somewhere
\textit{above and beyond} the \textit{highest} reading when \textit{not}
touching and somewhere around an \textit{average} reading when
\textit{touching}.\footnote{ The \mTSCa{ss} procedure takes some of the guess
work out of this decision.}

%%%%%%%%%%%%%%%%%%%%%%%%%%%%%%%%%%%%%%%%%%%%%%%%%%%%%%%%%%%%%%%%%%%%%%%%%%%%%%%%
% Overview
%%%%%%%%%%%%%%%%%%%%%%%%%%%%%%%%%%%%%%%%%%%%%%%%%%%%%%%%%%%%%%%%%%%%%%%%%%%%%%%%
\section{Overview}

There are a number of states \mTS{f} can be in and are explained in the next
sections.

\ers{2}
\begin{longtabu} { X[1,c,m] | X[3,l,m] }
  \thrule
  \thbi{State} & \thbi{Description} \\ \mrule

  \sTSMe{sym} & Select a menu option. \\ \mrule
  \multicolumn{2}{c}{\mTSCa{sym}} \\ \mrule
  \sTSWB{sym} & Wait before baseline calibration run. \\ \drule{2}
  \sTSBR{sym} & Baseline calibration run. \\ \drule{2}
  \sTSWT{sym} & Wait before touch calibration run. \\ \drule{2}
  \sTSTR{sym} & Touch calibration run. \\ \mrule
  \multicolumn{2}{c}{\mTSRe{sym}} \\ \mrule
  \sTSRT{sym} & Set initial touch threshold by touching and reading. \\ \mrule
  \multicolumn{2}{c}{\mTSCo{sym}} \\ \mrule
  \sTSNS{sym} & Configure the base number of scans per reading. \\ \drule{2}
  \sTSPS{sym} & Configure the prescaler - the multiplier applied to \sTSNS{f}. \\ \drule{2}

  \pagebreak \drule{2}

  \sTSRC{sym} & Configure the reference charge rate per reading. \\ \drule{2}
  \sTSEC{sym} & Configure the external\slash electrode charge rate per reading. \\ \mrule
  \multicolumn{2}{c}{\mTSCa{sym} \mTSRe{sym} \mTSCo{sym}} \\ \mrule
  \sTSTA{sym} & Test and adjust final touch threshold value. \\ \mrule
  \multicolumn{2}{c}{\mTSCa{sym} \mTSRe{sym} \mTSCo{sym} \mTSDe{sym}} \\ \mrule
  \sTSDo{sym} & Display settings. \\ \mrule
  \multicolumn{2}{c}{\mTSDi{sym}} \\ \mrule
  \sTSDi{sym} & Touch is disabled. \\
  \bhrule
\caption{Touch Settings - States}
\end{longtabu}

%%%%%%%%%%%%%%%%%%%%%%%%%%%%%%%%%%%%%%%%%%%%%%%%%%%%%%%%%%%%%%%%%%%%%%%%%%%%%%%%
% Overview - Menu
%%%%%%%%%%%%%%%%%%%%%%%%%%%%%%%%%%%%%%%%%%%%%%%%%%%%%%%%%%%%%%%%%%%%%%%%%%%%%%%%
\sTSMe{sym} \par\medskip

The general progression through the states starts with the \sTSMe{f}.  The
\sTSMe{f} has \num{5} options to select from.

\begin{table}[H]
\ers{0.1}
\centering
\begin{tabu}{c c}
  \thi{Option} & \thi{Display} \\ \mrule
  \mTSCa{sym} & \symD{CAL.!} \\
  \mTSRe{sym} & \symD{rEAd} \\
  \mTSCo{sym} & \symD{ConF.} \\
  \mTSDe{sym} & \symD{dEF.!} \\
  \mTSDi{sym} & \symD{OFF!}
\end{tabu}
\end{table}

To select an option, \aTu{f} the \cEs{f} then \aPR{f}.

\as{{c c c c}}{\sTSMe{sym} & \sTu & \sPR & \eSel{sym}{MENU OPTION} \\}

After selecting a menu option, the path taken is dependent on the option
selected.  The paths for \mTSCa{f}, \mTSRe{f} and \mTSCo{f} all lead to
\sTSTA{f} while \mTSDe{f} goes directly to the \sTSDo{f} state and \mTSDi{f} to
the \sTSDi{f} state.

\as{{c c c}}{%
\mTSCa{sym} & & \\
\mTSRe{sym} & $\cdots$ & \sTSTA{sym} \\
\mTSCo{sym} & & \\ \drule{3}
\mTSDe{sym} & $\longrightarrow$ & \sTSDo{sym} \\ \drule{3}
\mTSDi{sym} & $\longrightarrow$ & \sTSDi{sym} \\}

%%%%%%%%%%%%%%%%%%%%%%%%%%%%%%%%%%%%%%%%%%%%%%%%%%%%%%%%%%%%%%%%%%%%%%%%%%%%%%%%
% Overview - Calibration
%%%%%%%%%%%%%%%%%%%%%%%%%%%%%%%%%%%%%%%%%%%%%%%%%%%%%%%%%%%%%%%%%%%%%%%%%%%%%%%%
\mTSCa{sym} \par\medskip

Set the touch threshold via a calibration process.

\par\medskip

Calibration involves \num{3} phases.  First is a \sTSBR{f}, where a number of
readings are taken \textit{without} touching the \cTo{f} of the enclosure.
After completion, the same process is done \textit{touching} the \cTo{f} of the
enclosure.  Finally, a \sTSTA{f} adjust phase is performed to tune the final
touch threshold value.

\as{{ c c c c c c c }}{%
\mono{Phase 1}
  & \sTSWB{sym} & \sNTo & \sPR & \sTSBR{sym}
    & \eCo{sym}{RUN} & \sTSWT{sym} \\ \drule{7}
\mono{Phase 2}
  & \sTSWT{sym} & \sTo & \sPR & \sTSTR{sym}
    & \eCo{sym}{RUN} & \sTSTA{sym} \\ \drule{7}
\mono{Phase 3}
  & \sTSTA{sym} & \multicolumn{3}{c}{\sTo\enspace \fontTGA{f}{\&}\enspace \sTu}
  & \sPR & \sTSDo{sym} \\}

%%%%%%%%%%%%%%%%%%%%%%%%%%%%%%%%%%%%%%%%%%%%%%%%%%%%%%%%%%%%%%%%%%%%%%%%%%%%%%%%
% Overview - Read
%%%%%%%%%%%%%%%%%%%%%%%%%%%%%%%%%%%%%%%%%%%%%%%%%%%%%%%%%%%%%%%%%%%%%%%%%%%%%%%%
\mTSRe{sym} \par\medskip

Set the touch threshold through touch readings.

\par\medskip

Reading involves \num{2} phases.  The first is simply touching the \cTo{f} of
the enclosure which will display readings when touched. Then \aPR{f} the \cEs{f}
to carry a reading value over into \sTSTA{f} where you will tune the final touch
threshold value.

\as{{ c c c c c }}{%
\mono{Phase 1}
  & \sTSRT{sym} & \sTo & \sPR & \sTSTA{sym} \\ \drule{5}
\mono{Phase 2}
  & \sTSTA{sym} & \sTo\enspace \fontTGA{f}{\&}\enspace \sTu
  & \sPR & \sTSDo{sym} \\}

%%%%%%%%%%%%%%%%%%%%%%%%%%%%%%%%%%%%%%%%%%%%%%%%%%%%%%%%%%%%%%%%%%%%%%%%%%%%%%%%
% Overview - Configuration
%%%%%%%%%%%%%%%%%%%%%%%%%%%%%%%%%%%%%%%%%%%%%%%%%%%%%%%%%%%%%%%%%%%%%%%%%%%%%%%%
\mTSCo{sym} \par\medskip

Set the touch threshold by first configuring touch sensitivity values, then
proceeding through calibration.

\par\medskip

Configuration involves \num{4} phases.  The first is setting values relevant to
touch sensitivity.  The remaining phases are the same as with the \mTSCa{f} menu
option.
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

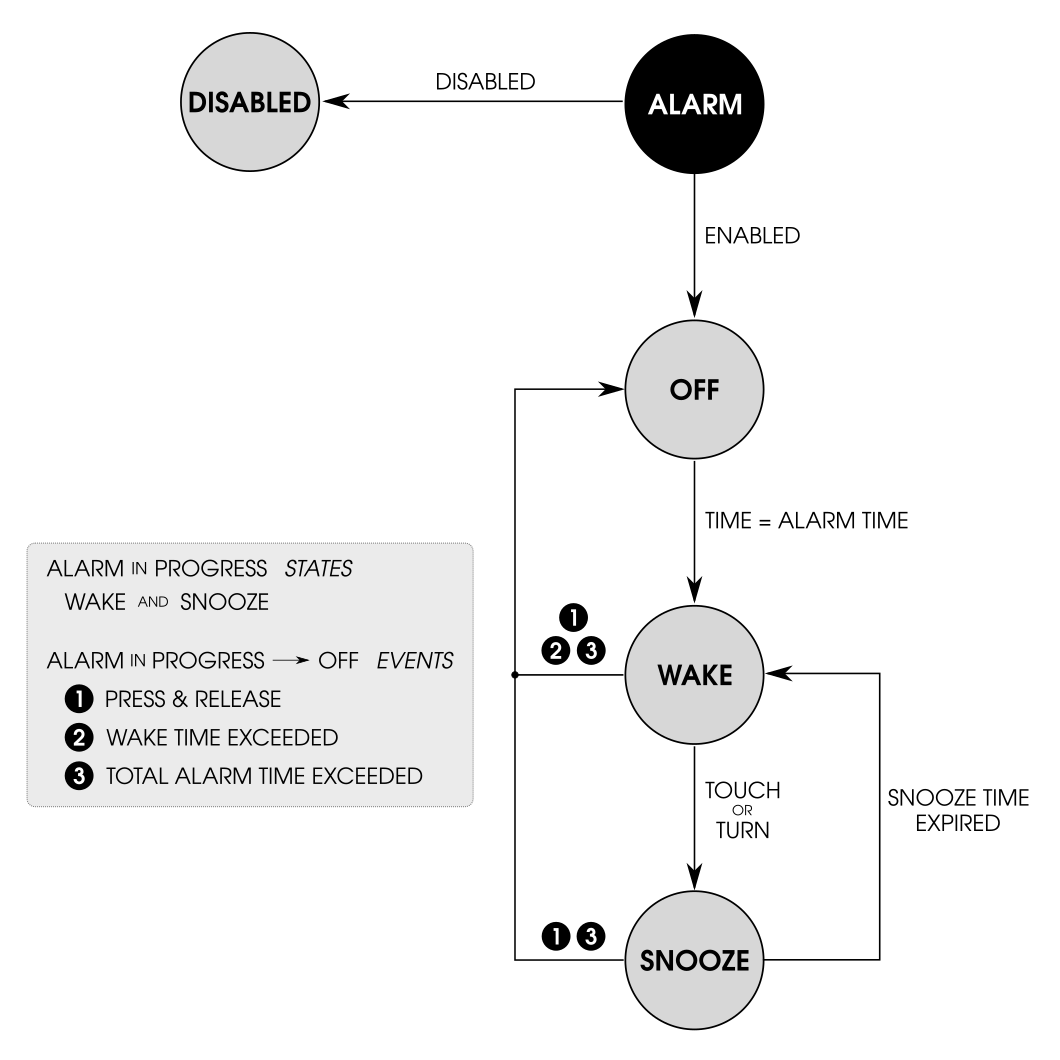
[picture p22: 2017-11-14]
docs/images/alarm_state_diagram.png

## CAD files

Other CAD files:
enclosure/back.f3d
enclosure/bottom.f3d
enclosure/front.f3d
enclosure/side.f3d
enclosure/top.f3d

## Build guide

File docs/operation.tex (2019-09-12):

%%%%%%%%%%%%%%%%%%%%%%%%%%%%%%%%%%%%%%%%%%%%%%%%%%%%%%%%%%%%%%%%%%%%%%%%%%%%%%%%
% Operation
%%%%%%%%%%%%%%%%%%%%%%%%%%%%%%%%%%%%%%%%%%%%%%%%%%%%%%%%%%%%%%%%%%%%%%%%%%%%%%%%
\part{Operation} \label{Operation}

%%%%%%%%%%%%%%%%%%%%%%%%%%%%%%%%%%%%%%%%%%%%%%%%%%%%%%%%%%%%%%%%%%%%%%%%%%%%%%%%
% Modules
%%%%%%%%%%%%%%%%%%%%%%%%%%%%%%%%%%%%%%%%%%%%%%%%%%%%%%%%%%%%%%%%%%%%%%%%%%%%%%%%
\chapter{Modules} \label{Modules}

%%%%%%%%%%%%%%%%%%%%%%%%%%%%%%%%%%%%%%%%%%%%%%%%%%%%%%%%%%%%%%%%%%%%%%%%%%%%%%%%
% Modules - Introduction
%%%%%%%%%%%%%%%%%%%%%%%%%%%%%%%%%%%%%%%%%%%%%%%%%%%%%%%%%%%%%%%%%%%%%%%%%%%%%%%%
\section{Introduction}

There are a number of functions that the device performs.  Each set of
functionality will be called a \textit{module}.  There are some modules that are
always active and some that can only be active at one time.  Those that are
always active will be called \textit{components}.  Those that can only be active
at one time will be called \textit{modes}.

\begin{table}[H]
\ers{1}
\centering
\begin{tabu} { X[1,c,m] | X[1,c,m] }
  \thrule

  \multirow{4}{*}[-1mm]{\thbi{Components}}
  & \hyperref[USB]{\mUsb{s}} \\
  & \hyperref[Audio]{\mAu{s}} \\
  & \hyperref[Alarm]{\mAl{s}} \\
  & \hyperref[Power]{\mPo{s}} \\ \mrule

  & \hyperref[Clock]{\mCl{s}} \\
  & \hyperref[Set Alarm]{\mSA{s}}  \\
  & \hyperref[Timer]{\mTi{s}} \\
  \thbi{Modes} & \hyperref[Set Clock]{\mSC{s}} \\
  & \hyperref[Power Settings]{\mPS{s}} \\
  & \hyperref[Touch Settings]{\mTS{s}} \\
  & \hyperref[Set Night Light]{\mSN{s}} \\
  \bhrule
\end{tabu}
\caption {Modules}
\end{table}

%%%%%%%%%%%%%%%%%%%%%%%%%%%%%%%%%%%%%%%%%%%%%%%%%%%%%%%%%%%%%%%%%%%%%%%%%%%%%%%%
% Modules - State Diagrams
%%%%%%%%%%%%%%%%%%%%%%%%%%%%%%%%%%%%%%%%%%%%%%%%%%%%%%%%%%%%%%%%%%%%%%%%%%%%%%%%
\section{State Diagrams}

At the end of each module section will be a diagram showing the states it can be
in and the movement from one state to another and actions triggering the
movement.  The following table shows and describes the diagram elements.

\pagebreak

\ers{3}
\begin{longtabu}{ X[1,c,m] | X[5,l,m] }
  \thrule

  \thbi{Symbol} & \thbi{Meaning} \\ \mdrule

  \symMode{MODULE}
    & An element that is a \mode{sym}{MODULE}, i.e. a \mode{sym}{MODE}
      or \mode{sym}{COMPONENT}. \\ \mrule

  \symMenu{MENU}
    & An element that is a \menu{sym}{MENU} option available in certain modes.
      A menu state will contain a number options that will branch
      to different states. \\ \mrule

  \symState{STATE}
    & An element that is a \state{sym}{STATE} that a mode or
      component can be in. \\ \mrule

  \multirow{6}{*}{\symUnidirectional}
    & A \textit{unidirectional} or one-way path or flow from one element to
      the same or different element. \\ \dcrule{2}{2}
    & \parbox{\linewidth}{\centering \symUniModule \quad\quad \symUniMenu \quad\quad \symUniState} \\
    & \footnotesize{One or more actions may be associated
        with the path, i.e. will trigger the movement from one element
        to another. Either a symbol or text may be located next to or near
        the path line indicating the
        action that triggers the movement.} \\
    & \parbox{\linewidth}{\centering \symUniStateAction} \\ \dcrule{2}{2}
    & \footnotesize{A state can have a path that points to itself.
        There may be output or effects due to the action but
        the state does not change.} \\
    & \parbox{0.85\linewidth}{\centering \symUniSameState} \strut \\ \mrule

  \multirow{5}{*}{\symBidirectional}
    & A \textit{bidirectional} or two-way path or flow between two elements. \\ \dcrule{2}{2}
    & \footnotesize{One or more actions may be associated
        with the path, i.e will trigger the movement between the two
        elements. Either an action
        symbol or text will be located next to or near the path line
        indicating the action that triggers the movement.} \\
    & \parbox{\linewidth}{\centering \symBiStateOne} \\ \dcrule{2}{2}
    & \footnotesize{If there is more than one action associated
        with the path, the action \textit{nearest the arrow} is
        what determines the path or flow \textit{in the direction of the arrow}.} \\
    & \parbox{\linewidth}{\centering \symBiState} \\ \mrule

  \pagebreak
  \mrule

  \multirow{3}{*}{\symNode}
    & A \textit{node} that combines two or more unidirectional paths from two or
      more states into one unidirectional path to one state. \\ \dcrule{2}{2}
    & \footnotesize{Each path leading into the node will have an
        action associated with it.  The actions may be the same
        or different, but the resulting state will be the same.} \\
    & \parbox{\linewidth}{\centering \symNodeState} \strut \\

  \bhrule
\caption{State Diagram Symbols}
\end{longtabu}

%%%%%%%%%%%%%%%%%%%%%%%%%%%%%%%%%%%%%%%%%%%%%%%%%%%%%%%%%%%%%%%%%%%%%%%%%%%%%%%%
% Modules - Components
%%%%%%%%%%%%%%%%%%%%%%%%%%%%%%%%%%%%%%%%%%%%%%%%%%%%%%%%%%%%%%%%%%%%%%%%%%%%%%%%
\section{Components}

Components run and function concurrently and independent of any \textit{mode}
the device might be in.

\par\medskip

There are \num{4} components each described in individual sections.

\begin{table}[H]
\ers{4}
\centering
\begin{tabu}{ X[1,c,m] | X[3,l,m] }
  \thrule
  \thbi{Component} & \thbi{Description} \\ \mrule

  \hyperref[USB]{\mUsb{s}}
    & Allows adding and removing songs to and from the device. \\ \drule{2}
  \hyperref[Audio]{\mAu{s}}
    & Provides the functionality related to track selection and
      playback. \\ \drule{2}
  \hyperref[Alarm]{\mAl{s}}
    & Contains the functionality related to alarm waking, snoozing and stopping
      and remains active in all power states. \\ \drule{2}
  \hyperref[Power]{\mPo{s}}
    & Governs device power states and when the device should nap, sleep or
      auto-stop the audio. \\
  \bhrule
\end{tabu}
\end{table}

%%%%%%%%%%%%%%%%%%%%%%%%%%%%%%%%%%%%%%%%%%%%%%%%%%%%%%%%%%%%%%%%%%%%%%%%%%%%%%%%
% Modules - Modes
%%%%%%%%%%%%%%%%%%%%%%%%%%%%%%%%%%%%%%%%%%%%%%%%%%%%%%%%%%%%%%%%%%%%%%%%%%%%%%%%
\section{Modes}

A mode is a device state containing specific functionality.  The device can be
in \textit{one and only one} mode at a time.  There are \num{7} modes each
described in individual sections.

\begin{table}[H]
\ers{4}
\centering
\begin{tabu}{ X[1,c,m] | X[3,l,m] }
  \thrule
  \thbi{Mode} & \thbi{Description} \\ \mrule

  \hyperref[Clock]{\mCl{s}}
    & Displays the time. Can display the date and current track.
    Provides direct selection of a track for playback. Is the only mode
    where the night light can be turned on and off. \\ \drule{2}
  \hyperref[Set Alarm]{\mSA{s}} & Set a time of day alarm that is used by
    the \hyperref[Alarm]{\mAl{s}} component. \\ \drule{2}
  \hyperref[Timer]{\mTi{s}} & Set and run a timer. \\ \drule{2}
  \hyperref[Set Clock]{\mSC{s}} & Set the time and date. \\ \drule{2}
  \hyperref[Power Settings]{\mPS{s}} & Settings related to power consumption
    that are used by the \hyperref[Power]{\mPo{s}} component. \\ \drule{2}
  \hyperref[Touch Settings]{\mTS{s}} & Settings related to the touch sensing
    capability of the device. \\ \drule{2}
  \hyperref[Set Night Light]{\mSN{s}} & Set any of the \num{3} configurable
    night light colors. \\

  \bhrule
\end{tabu}
\end{table}

Modes are selected using the \cRs{f} and the \cEs{f}.  They are partitioned
into \mPr{f}, \mSe{f} and \mTe{f}.

\begin{table}[H]
\ers{1}
\centering
\begin{tabu} { X[1,c,m] | X[1,c,m] }
  \thrule

  & \hyperref[Clock]{\mCl{s}} \\
  \hyperref[Primary Modes]{\mPr{s}} & \hyperref[Set Alarm]{\mSA{s}} \\
  & \hyperref[Timer]{\mTi{s}} \\ \mrule

  \multirow{2}{*}[-1mm]{\hyperref[Secondary Modes]{\mSe{s}}}
    & \hyperref[Set Clock]{\mSC{s}} \\
  & \hyperref[Power Settings]{\mPS{s}} \\ \mrule

  \multirow{2}{*}[-1mm]{\hyperref[Tertiary Modes]{\mTe{s}}}
    & \hyperref[Touch Settings]{\mTS{s}} \\
  & \hyperref[Set Night Light]{\mSN{s}} \\
  \bhrule
\end{tabu}
\caption {Modes}
\end{table}

The position of the \cRs{f} avails a subset of modes.  When the \cRs{f} is
turned, the \mPr{f} mode is automatically selected.  The \cEs{f} is then used
to select \mSe{f} and \mTe{f} modes.

%%%%%%%%%%%%%%%%%%%%%%%%%%%%%%%%%%%%%%%%%%%%%%%%%%%%%%%%%%%%%%%%%%%%%%%%%%%%%%%%
% Modules - Modes - Settings Modes
%%%%%%%%%%%%%%%%%%%%%%%%%%%%%%%%%%%%%%%%%%%%%%%%%%%%%%%%%%%%%%%%%%%%%%%%%%%%%%%%
\subsection{Settings Modes}

Settings that can change value will, in general, be \textit{blinking} on the
\cDi{f}. If there is more than one setting to configure on the \cDi{f} at a time,
as in the case of setting a time (hour and minute) or date (month and day), the
current setting will be \textit{blinking}.

%%%%%%%%%%%%%%%%%%%%%%%%%%%%%%%%%%%%%%%%%%%%%%%%%%%%%%%%%%%%%%%%%%%%%%%%%%%%%%%%
% Modules - Modes - Modes Diagram
%%%%%%%%%%%%%%%%%%%%%%%%%%%%%%%%%%%%%%%%%%%%%%%%%%%%%%%%%%%%%%%%%%%%%%%%%%%%%%%%
\subsection{Modes Diagram}

The following diagram illustrates the modes of operation and the actions using
the \cRs{f} and \cEs{f} that lead to and from each mode.

\begin{figure}[H]
\centering
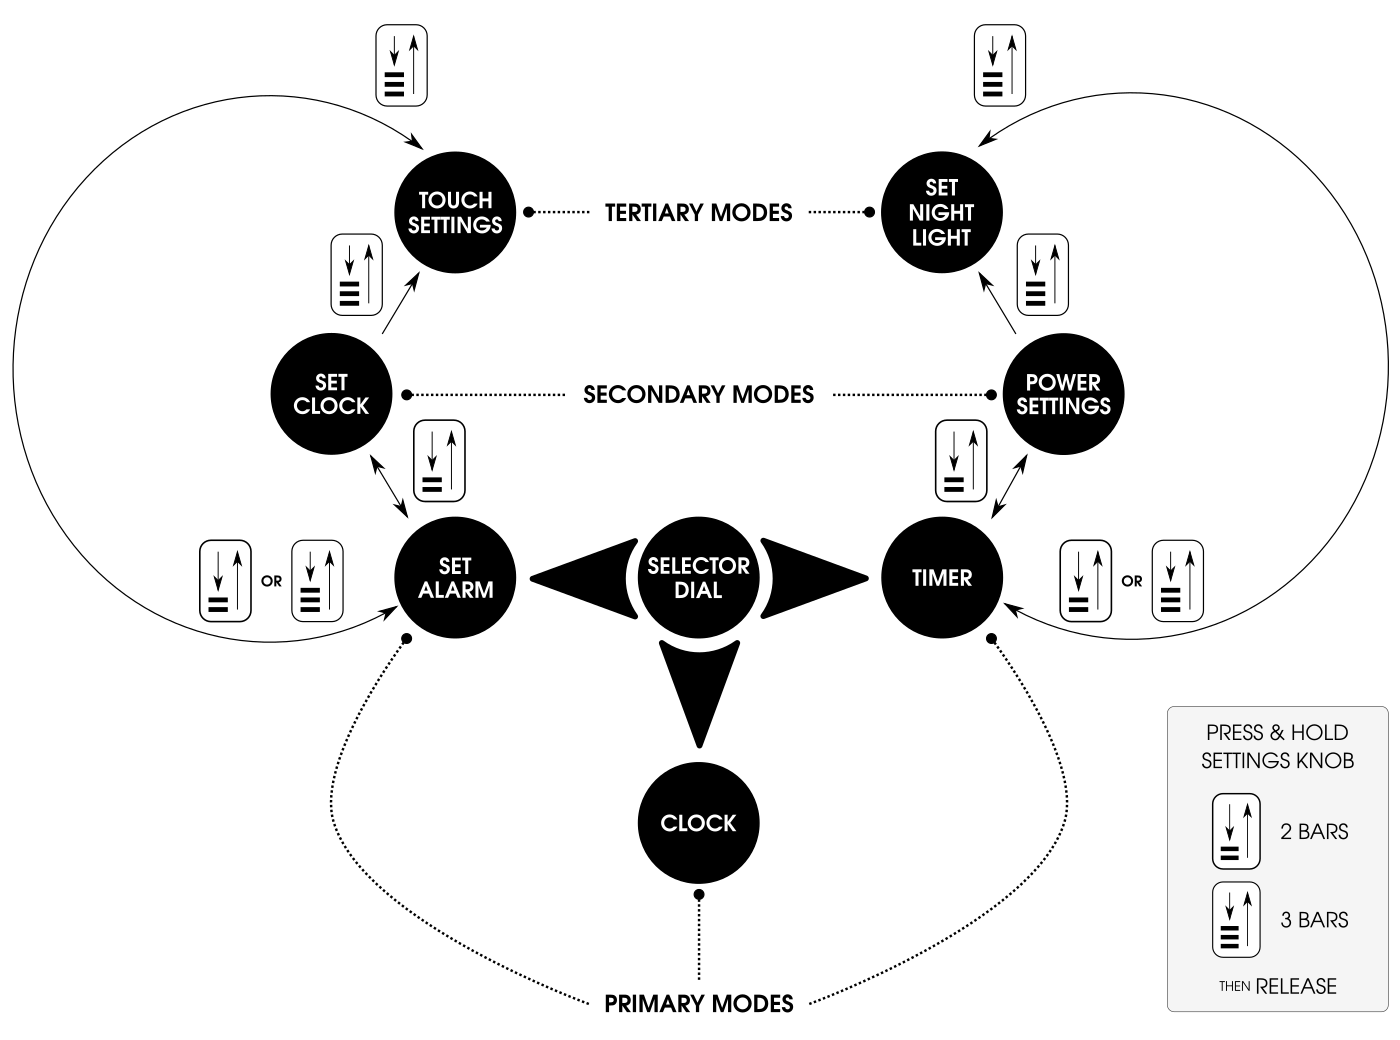
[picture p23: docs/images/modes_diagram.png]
  
\caption{Modes Diagram}
\end{figure}

%%%%%%%%%%%%%%%%%%%%%%%%%%%%%%%%%%%%%%%%%%%%%%%%%%%%%%%%%%%%%%%%%%%%%%%%%%%%%%%%
% Selector Dial
%%%%%%%%%%%%%%%%%%%%%%%%%%%%%%%%%%%%%%%%%%%%%%%%%%%%%%%%%%%%%%%%%%%%%%%%%%%%%%%%
\chapter{Selector Dial} \label{Operation - Selector Dial}

The \cRs{f} is used to select a subset of available modes.  The position
determines which modes are available.

\begin{table}[H]
\ers{2}
  \begin{tabu}{ X[1,c,m] | X[1,c,m] | X[1,c,m] | X[1,c,m] }  
    \thrule
    \multirow{2}{*}[-1mm]{\thbi{Position}}
      & \multicolumn{3}{c}{\thbi{Modes}} \\ \tabucline{2-4}

    & \mPr{n} & \mSe{n} & \mTe{n}
    \\ \hline

    \sLe & \hyperref[Set Alarm]{\mSA{s}}
      & \hyperref[Set Clock]{\mSC{s}}
      & \hyperref[Touch Settings]{\mTS{s}} \\ \drule{4}
    \sMi & \hyperref[Clock]{\mCl{s}} & --- & --- \\ \drule{4}
    \sRi & \hyperref[Timer]{\mTi{s}}
      & \hyperref[Power Settings]{\mPS{s}}
      & \hyperref[Set Night Light]{\mSN{s}} \\
  \bhrule
  \end{tabu}
\caption {Selector Dial - Positions \& Modes}
\end{table}

Turning the \cRs{f} will automatically set the mode to the \mPr{f} mode for the
given position.  The \hyperref[Operation - Settings Knob]{\cEs{f}} is then used
to select \mSe{f} and \mTe{f} modes.

\par\medskip

There are a number of symbols used to indicate turning actions.

\begin{table}[H]
\ers{5}
\centering
  \begin{tabu} { X[1,c,m] | X[3,l,m] }
    \thrule
    \thbi{Symbol} & \thbi{Meaning} \\ \mrule
    $\hskip -5.5mm$ \sMtoL & Turn from \dMi{f} to \dLe{f}. \\ \drule{2}
    $\hskip -5.5mm$ \sLtoM & Turn from \dLe{f} to \dMi{f}. \\ \drule{2}
    $\hskip 2.5mm$ \sMtoR & Turn from \dMi{f} to \dRi{f}. \\ \drule{2}
    $\hskip 2.5mm$ \sRtoM & Turn from \dRi{f} to \dMi{f}. \\ \drule{2}
    \sLtoR & Turn from \dLe{f} to \dRi{f}. \\ \drule{2}
    \sRtoL & Turn from \dRi{f} to \dLe{f}. \\
    \bhrule
  \end{tabu}
\caption {Selector Dial - Symbols}
\end{table}

%%%%%%%%%%%%%%%%%%%%%%%%%%%%%%%%%%%%%%%%%%%%%%%%%%%%%%%%%%%%%%%%%%%%%%%%%%%%%%%%
% Settings Knob
%%%%%%%%%%%%%%%%%%%%%%%%%%%%%%%%%%%%%%%%%%%%%%%%%%%%%%%%%%%%%%%%%%%%%%%%%%%%%%%%
\chapter{Settings Knob} \label{Operation - Settings Knob}

The \cEs{f} is the primary control for interacting with the device.  It can be
\textit{turned} and \textit{pressed}.

%%%%%%%%%%%%%%%%%%%%%%%%%%%%%%%%%%%%%%%%%%%%%%%%%%%%%%%%%%%%%%%%%%%%%%%%%%%%%%%%
% Settings Knob - Turning
%%%%%%%%%%%%%%%%%%%%%%%%%%%%%%%%%%%%%%%%%%%%%%%%%%%%%%%%%%%%%%%%%%%%%%%%%%%%%%%%
\section{Turning}

There are \textit{no} start or stop positions when turning and it will turn
indefinitely in either direction.  While turning, you will notice bumps - termed
\textit{detents} - that provide a tactile feel for turning progression.

\par\medskip

In general, when setting values:

\begin{itemize}
  \item Turning \textit{clockwise} will \textit{increase} a value.
  \item Turning \textit{counter-clockwise} will \textit{decrease} a value.
  \item Values will \textit{change} at each \textit{detent}.
\end{itemize}

If you turn past a \textit{minimum} or \textit{maximum}, the value will usually
wrap or cycle.

\begin{itemize}
  \item If a value is at a \textit{maximum}, a \textit{clockwise} turn will
    circle to the \textit{minimum}.
  \item If a value is at a \textit{minimum}, a \textit{counter-clockwise} turn
    will circle to the \textit{maximum}.
\end{itemize}

\begin{figure}[H]
\centering
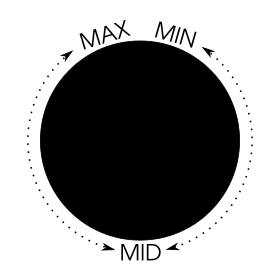
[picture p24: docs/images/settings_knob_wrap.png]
  
\caption{Settings Knob - Turning}
\end{figure}

Note that the above figure is not a literal representation of where values will
lie in relation to the \cEs{f}.  You may have to turn the knob for only a couple
of detents to reach a midpoint value or cycle through all of the allowable
values.  Or you may have to turn for many revolutions.  It is meant to show that
values are arranged circularly as opposed to linearly.

\par\medskip

Consider, for example, setting a minute or second value, where the allowable
range is \mono{0-59}.  If the current value is \num{59}, a clockwise turn will
cycle to \num{0}.  Likewise if the current value is \num{0}, a counter-clockwise
turn will cycle to \num{59}.

\begin{figure}[H]
\centering
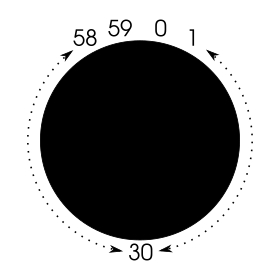
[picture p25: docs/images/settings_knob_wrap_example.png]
  
\end{figure}

\info{It can often be quicker to turn in the opposite direction to get to a
value.}

\par\medskip

There are a number of symbols that will be used indicating direction, number of
times, not to turn or a failure to turn within a specified amount of time.

\begin{table}[H]
\ers{2}
\centering
  \begin{tabu}{ X[1,c,m] | X[4,l,m] }
  \thrule

  \thbi{Symbol} & \thbi{Meaning} \\ \mrule

  \sTu & Turn in \textit{any} direction. \\ \drule{2}
  \sCl & Turn \textit{clockwise}. \\ \drule{2}
  \sCC & Turn \textit{counter-clockwise}. \\ \drule{2}
  \multirow{2}{*}[-1mm]{$\hskip 3.3mm$ \sTuN{$N$}}
    & Turn for at least $N$ detents in any direction. \\
  & \quad \sTuN{3} $\longrightarrow$ Turn until at least \num{3} detents
    are felt. \\ \drule{2}
  \multirow{2}{*}[-1mm]{$\hskip 3.3mm$ \sTuN{$N$s}} & Turn \textit{within}
    $N$ seconds. \\
  & \quad \sTuN{3s} $\longrightarrow$ Turn within \num{3} seconds. \\ \drule{2}
  \sNTu & Do \textit{not} turn. \\ \drule{2}
  \multirow{2}{*}[-1mm]{$\hskip 4.4mm$ \sNTuN{$N$}} & Failure to turn
    \textit{within} $N$ seconds. \\
  & \quad \sNTuN{15} $\longrightarrow$ Failure to turn within \num{15}
    seconds. \\
  \bhrule
  \end{tabu}
\caption{Settings Knob - Turn Symbols}
\end{table}

When the \cEs{f} is turned, you will feel bumps.  These are called
\textit{detents}.  When it is specified to turn $N$ times, it means detents
and \textit{not} full rotations.  So \enspace \sTuN{3} means to turn for at
least \num{3} bumps/detents.

%%%%%%%%%%%%%%%%%%%%%%%%%%%%%%%%%%%%%%%%%%%%%%%%%%%%%%%%%%%%%%%%%%%%%%%%%%%%%%%%
% Settings Knob - Pressing
%%%%%%%%%%%%%%%%%%%%%%%%%%%%%%%%%%%%%%%%%%%%%%%%%%%%%%%%%%%%%%%%%%%%%%%%%%%%%%%%
\section{Pressing}

There are \num{3} main pressing actions.

\begin{table}[H]
\ers{5}
\begin{tabu}{ X[2,c,m] | X[1,c,m] | X[4,l,m] }
  \thrule
  \thbi{Action} & \thbi{Abbr.} & \thbi{Description} \\ \mrule
  \hyperref[Press and Release]{\aPR{s}}
    & \fontTGA{s}{P\&R} & A relatively quick press \& release
    similar to a computer mouse click. \\ \drule{3}
  \hyperref[Double-Click]{\aDC{s}}
    & \fontTGA{s}{DC} & Press \& release \textit{twice} in quick
    succession, similar to a computer mouse double-click. \\ \drule{3}
  \hyperref[Press and Hold]{\aPH{s}}
    & \fontTGA{s}{P\&H} & Press and hold for some amount of time,
    then release. \\
  \bhrule
\end{tabu}
\caption {Settings Knob - Pressing Actions}
\end{table}

%%%%%%%%%%%%%%%%%%%%%%%%%%%%%%%%%%%%%%%%%%%%%%%%%%%%%%%%%%%%%%%%%%%%%%%%%%%%%%%%
% Settings Knob - Pressing - Press & Release
%%%%%%%%%%%%%%%%%%%%%%%%%%%%%%%%%%%%%%%%%%%%%%%%%%%%%%%%%%%%%%%%%%%%%%%%%%%%%%%%
\subsection{Press \& Release} \label{Press and Release}

What action this performs will be dependent on context.

\par\medskip

In settings modes, it generally caches a setting and moves to the next setting
or if at the last setting, sets and saves all cached settings and finishes.

\par\medskip

In other cases, it may turn the alarm off, show the date or pause the timer.

\par\medskip

There are a number of symbols that will be used indicating number of times, not
to press or a failure to press within a specified amount of time.

\begin{table}[H]
\ers{2}
\centering
\begin{tabu}{ X[1,c,m] | X[5,l,m] }
  \thrule
  \thbi{Symbol} & \thbi{Meaning} \\ \mrule
  \sPR & Press \& release \textit{once}. \\ \drule{2}
  \multirow{2}{*}[-1mm]{$\hskip 3.3mm$ \sPRN{$N$}} & Press \& release $N$ times. \\
    & \quad \sPRN{4} $\longrightarrow$ Press \& release \num{4} times. \\ \drule{2}
  \multirow{2}{*}[-1mm]{$\hskip 3.3mm$ \sPRN{$N$s}}
    & Press \& release \textit{within} $N$ seconds. \\
    & \quad \sPRN{4s} $\longrightarrow$ Press \& release within \num{4} seconds. \\ \drule{2}
  \sNPR & Do \textit{not} press \& release. \\ \drule{2}
  \multirow{2}{*}[-1mm]{$\hskip 4.3mm$ \sNPRN{$N$}} & Failure to press \& release
    \textit{within} $N$ seconds. \\
    & \quad \sNPRN{3} $\longrightarrow$ Failure to press \& release within \num{3} seconds. \\
  \bhrule
\end{tabu}
\caption{Settings Knob - Press \& Release Symbols}
\end{table}

%%%%%%%%%%%%%%%%%%%%%%%%%%%%%%%%%%%%%%%%%%%%%%%%%%%%%%%%%%%%%%%%%%%%%%%%%%%%%%%%
% Settings Knob - Pressing - Double-Click
%%%%%%%%%%%%%%%%%%%%%%%%%%%%%%%%%%%%%%%%%%%%%%%%%%%%%%%%%%%%%%%%%%%%%%%%%%%%%%%%
\subsection{Double-Click} \label{Double-Click}

This is currently only used in \hyperref[Set Night Light]{\mSN{f}} and has one
associated symbol.

\begin{table}[H]
\ers{2}
\centering
\begin{tabu}{ X[1,c,m] | X[5,l,m] }
  \thrule
  \thbi{Symbol} & \thbi{Meaning} \\ \mrule
  \sDC & Press \& release \textit{twice} in quick succession. \\
  \bhrule
\end{tabu}
\caption {Settings Knob - Double-Click Symbol}
\end{table}

It is distinguished from \enspace \sPRN{$N$} in that the second press \& release
\textit{must} be done very quickly - within \mono{300\thinspace ms} which is
a little less than $\frac{1}{3}$ of a second.

%%%%%%%%%%%%%%%%%%%%%%%%%%%%%%%%%%%%%%%%%%%%%%%%%%%%%%%%%%%%%%%%%%%%%%%%%%%%%%%%
% Settings Knob - Pressing - Press & Hold
%%%%%%%%%%%%%%%%%%%%%%%%%%%%%%%%%%%%%%%%%%%%%%%%%%%%%%%%%%%%%%%%%%%%%%%%%%%%%%%%
\subsection{Press \& Hold} \label{Press and Hold}

This pressing action will, in general, do one of the following:

\begin{itemize}
  \item \aReset{f} a settings mode, i.e. allow starting over from the
    beginning or some origin state.
  \item Go to \mSe{f} or \mTe{f} modes -
    see \hyperref[Operation - Selector Dial]{\cRs{f}}.
  \item If currently in a \mSe{f} or \mTe{f} mode, go back to the \mPr{f} mode.
\end{itemize}

In every mode except \mCl{f} mode, bars / dashes will be shown and blink on the
\cDi{s} providing a visual indication to release.

\begin{table}[H]
\ers{3}
\begin{tabu}{ X[1,c,m] | X[1,c,m] | X[1,c,m] }
  \thrule
  \thbi{Display} & \thbi{Hold Time} & \thbi{Effect} \\ \mrule
  \sDl{<<<<} & \num{1.5} seconds & \aReset{f} \\ \drule{3}
  \sDl{====} & \num{4.0} seconds
    & \multirow{2}{*}[-1mm]{\action{f}{CHANGE MODE}} \\ \drule{2}
  \sDl{>>>>} & \num{6.5} seconds \\
  \bhrule
\end{tabu}
\caption{Settings Knob - Press \& Hold}
\end{table}

The following table shows the mode changes when the \cEs{f} is pressed and held
for two or three bars.

\begin{table}[H]
\ers{3}
\begin{tabu}{ X[1,c,m] | X[1,c,m] | X[1,c,m] }
  \thrule
  \thbi{Mode} & \thbi{Display} & \thbi{Next} \\ \mrule

  \multirow{2}{*}[-1mm]{\mPr{n}} & \sDl{====} & \mSe{n} \\ \dcrule{2}{3}
  & \sDl{>>>>} & \mTe{n} \\ \mrule

  \multirow{2}{*}[-1mm]{\mSe{n}} & \sDl{====} & \mPr{n} \\ \dcrule{2}{3}
  & \sDl{>>>>} & \mTe{n} \\ \mrule

  \multirow{2}{*}[-1mm]{\mTe{n}} & \sDl{====}
    & \multirow{2}{*}[-1mm]{\mPr{n}} \\ \dcrule{2}{2}
  & \sDl{>>>>} & \\
  \bhrule
\end{tabu}
\caption{Settings Knob - Press \& Hold Modes}
\end{table}

For example, to go to \hyperref[Touch Settings]{\mTS{f}} which is a \mTe{f} mode
and assuming the \cRs{f} is \textit{not} already pointing to the \dLe{f}:

\begin{enumerate}
  \item \aTu{f} the \cRs{f} to the \dLe{f}.
  \item \aPH{f} the \cEs{f} until you see \symD{>>>>} blink on the \cDi{f}.
  \item \aRe{f} the \cEs{f}.
\end{enumerate}

To go back to \hyperref[Set Alarm]{\mSA{f}} which is a \mPr{f} mode:

\begin{enumerate}
  \item \aPH{f} the \cEs{f} until you see \symD{====} or \symD{>>>>}
    blink on the \cDi{f}.
  \item \aRe{f} the \cEs{f}.
\end{enumerate}

There are a number of symbols that will be used indicating press type and
duration.

\begin{table}[H]
\ers{2}
\centering
\begin{tabu}{ X[1,c,m] | X[5,l,m] }
  \thrule
  \thbi{Symbol} & \thbi{Meaning} \\ \mrule
  \multirow{2}{*}[-1mm]{$\hskip 3.3mm$ \sPHN{$N$}}
    & Press \& hold for $N$ seconds then release. \\
    & \quad \sPHN{6} $\longrightarrow$ Press \& hold for \num{6} seconds then release. \\ \drule{2}
  \sReset & Press \& hold until \symD{<<<<} is displayed, then release. \\ \drule{2}
  \sSec & Press \& hold until \symD{====} is displayed, then release. \\ \drule{2}
  \sTer & Press \& hold until \symD{>>>>} is displayed, then release. \\
  \bhrule
\end{tabu}
\caption {Settings Knob - Press \& Hold Symbols}
\end{table}

%%%%%%%%%%%%%%%%%%%%%%%%%%%%%%%%%%%%%%%%%%%%%%%%%%%%%%%%%%%%%%%%%%%%%%%%%%%%%%%%
% Touch Sensor
%%%%%%%%%%%%%%%%%%%%%%%%%%%%%%%%%%%%%%%%%%%%%%%%%%%%%%%%%%%%%%%%%%%%%%%%%%%%%%%%
\chapter{Touch Sensor} \label{Operation - Touch Sensor}

The \cTS{f} utilizes
\href{https://en.wikipedia.org/wiki/Capacitive\_sensing}{Capacitive Touch Sensing}
which measures changes in capacitance of an \textit{electrode} to detect touch
events.  There are a number of functions that the \cTS{f} provides.

\begin{table}[H]
\centering
\ers{0.1}
\begin{tabu} { X[3,l,m] | X[2,c,m] }
  \thrule
  \thbi{Function} & \thbi{Module} \\ \mrule
  Snooze alarm. & \hyperref[Alarm]{\mAl{f}} \\ \drule{2}
  Show current track number. & \hyperref[Clock]{\mCl{f}} \\ \drule{2}
  Stop timer alerting. & \hyperref[Timer]{\mTi{f}} \\ \drule{2}
  Wake the device from nap or sleep. & \hyperref[Power]{\mPo{f}} \\ \drule{2}
  Toggle timer countdown lighting on/off. & \hyperref[Timer]{\mTi{f}} \\ \drule{2}
  Forcibly put the device to sleep. & \hyperref[Power]{\mPo{f}} \\
  \bhrule
\end{tabu}
\end{table}

All of the above, except for the last two, can also be done using the \cEs{f},
so if you want or need to disable the \cTS{f} you will not lose much
functionality.

\par\medskip

When using the touch functionality, it is not enough to simply tap or touch
the \cTo{f} with your index finger.  You \textit{must} place your \textit{hand}
or the majority of your fingers, palm down on the \cTo{f} of the enclosure.
The figure below shows the general amount of coverage.

\begin{figure}[H]
\centering
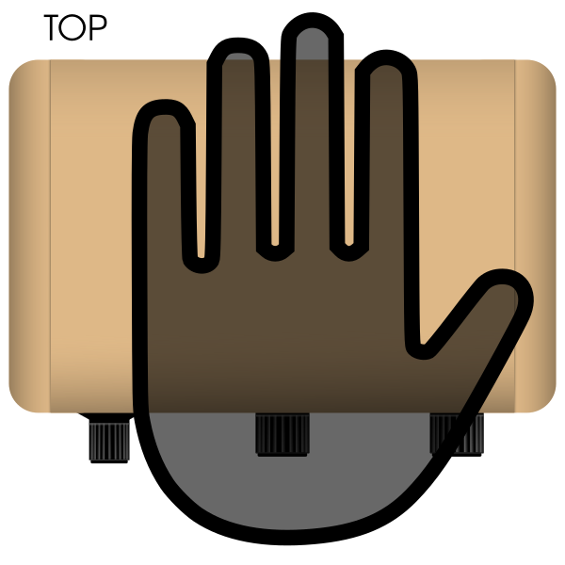
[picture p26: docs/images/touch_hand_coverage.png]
  
\caption{Touch Sensor - Hand Coverage} \label{fig:Hand Coverage}
\end{figure}

See \hyperref[Touch Settings]{\mTS{f}} for more information on configuring and
calibrating the \cTS{f}.

\par\medskip

There are a number of symbols that will be used indicating touch, touch
duration, not to touch and failure to touch within some amount of
time.\footnote{ Though an outstretched index finger is used in the symbol, the
palm of the hand or a majority of the fingers must be used.}

\begin{table}[H]
\ers{2}
\begin{tabu}{ X[1,c,m] | X[4,l,m] }
  \thrule
  \thbi{Symbol} & \thbi{Meaning} \\ \mrule
  \sTo & Touch the \cTo{f} of the enclosure with palm of hand. \\ \drule{2}
  \multirow{2}{*}[-1mm]{$\hskip 3.0mm$ \sToN{$N$}} & Touch for $N$ seconds. \\
    & \quad \sToN{5} $\longrightarrow$ Touch for \num{5} seconds. \\ \drule{2}
  \sNTo & Do \textit{not} touch. \\ \drule{2}
  \multirow{2}{*}[-1mm]{$\hskip 3.0mm$ \sNToN{$N$}}
    & Failure to touch \textit{within} $N$ seconds. \\
    & \quad \sNToN{3} $\longrightarrow$ Failure to touch within \num{3} seconds. \\
  \bhrule
\end{tabu}
\caption {Touch Sensor - Symbols}
\end{table}

%%%%%%%%%%%%%%%%%%%%%%%%%%%%%%%%%%%%%%%%%%%%%%%%%%%%%%%%%%%%%%%%%%%%%%%%%%%%%%%%
% Symbols
%%%%%%%%%%%%%%%%%%%%%%%%%%%%%%%%%%%%%%%%%%%%%%%%%%%%%%%%%%%%%%%%%%%%%%%%%%%%%%%%
\chapter{Symbols}

In addition to expository language, symbols will often be used to describe
actions and effects so that one can quickly surmise an action and outcome.

\par\medskip

For example, the following steps used in \mSC{f}:

\begin{enumerate}
  \item From the \sSCHo{f} state, \aTu{f} the \cEs{f} to select an hour.
  \item \aPR{f} the \cEs{f} to cache the selected hour and proceed to the
    \sSCMi{f} state.
\end{enumerate}

can be summed up using the following sequence of symbols:

\as{{c c c c}}{%
\sSCHo{sym} & \sTu & \sPR & \sSCMi{sym} \\}

Often, an \textit{effect} will be grouped with the \textit{action}:

\as{{c c c c}}{%
\multirow{2}{*}{\sSCHo{sym}}
  & \sTu & \sPR & \multirow{2}{*}{\sSCMi{sym}} \\
& \eUp{sym}{} & \eCa{sym}{} & \\}

And sometimes multiple actions will be grouped into one column indicating
that \textit{any} one of the actions can bring about the change.  For example,
the following is used in \mCl{f} to indicate any of four actions, three of
which are inactions, that will cause the \sClSh{f} state to go back to the
\sClTi{f} state.

\as{{ c c c }}{%
\multirow{4}{*}{\sClSh{sym}} & \sPR & \multirow{4}{*}{\sClTi{sym}} \\ \dcrule{2}{2}
& $\hskip 3mm$ \sNTuN{3} & \\ \dcrule{2}{2}
& $\hskip 3mm$ \sNToN{3} & \\ \dcrule{2}{2}
& $\hskip 3mm$ \sNPRN{3} & \\}

\pagebreak

The table below sums up all of the symbols described in the previous sections.

\ers{3}
\begin{longtabu}{ X[1,c,m] | X[4,l,m] }
  \thrule
  \multicolumn{2}{c}{\textbf{\cRs{n}}} \\ \mrule
  \thbi{Symbol} & \thbi{Meaning} \\ \mrule
  $\hskip -5.5mm$ \sMtoL & Turn from \dMi{f} to \dLe{f}. \\ \drule{2}
  $\hskip -5.5mm$ \sLtoM & Turn from \dLe{f} to \dMi{f}. \\ \drule{2}
  $\hskip 2.5mm$ \sMtoR & Turn from \dMi{f} to \dRi{f}. \\ \drule{2}
  $\hskip 2.5mm$ \sRtoM & Turn from \dRi{f} to \dMi{f}. \\ \drule{2}

  \sLtoR & Turn from \dLe{f} to \dRi{f}. \\ \drule{2}
  \sRtoL & Turn from \dRi{f} to \dLe{f}. \\

  \thrule
  \multicolumn{2}{c}{\textbf{\cEs{n}}} \\ \mrule
  \thbi{Symbol} & \thbi{Meaning} \\ \mrule

  \sTu & Turn in \textit{any} direction. \\ \drule{2}
  \sCl & Turn \textit{clockwise}. \\ \drule{2}
  \sCC & Turn \textit{counter-clockwise}. \\ \drule{2}
  \multirow{2}{*}[-1mm]{$\hskip 3.3mm$ \sTuN{$N$}}
    & Turn for at least $N$ detents in any direction. \\
    & \quad \sTuN{3} $\longrightarrow$ Turn until at least \num{3} detents are felt. \\ \drule{2}

  \pagebreak
  \drule{2}

  \sNTu & Do \textit{not} turn. \\ \drule{2}
  \multirow{2}{*}[-1mm]{$\hskip 4.4mm$ \sNTuN{$N$}}
    & Failure to turn \textit{within} $N$ seconds. \\
    & \quad \sNTuN{15} $\longrightarrow$ Failure to turn within \num{15} seconds. \\ \drule{2}

  \sPR & Press \& release \textit{once}. \\ \drule{2}
  \multirow{2}{*}[-1mm]{$\hskip 3.3mm$ \sPRN{$N$}} & Press \& release $N$ times. \\
    & \quad \sPRN{4} $\longrightarrow$ Press \& release \num{4} times. \\ \drule{2}
  \sNPR & Do \textit{not} press \& release. \\ \drule{2}

  \multirow{2}{*}[-1mm]{$\hskip 4.3mm$ \sNPRN{$N$}}
    & Failure to press \& release \textit{within} $N$ seconds. \\
    & \quad \sNPRN{3} $\longrightarrow$ Failure to
      press \& release within \num{3} seconds. \\ \drule{2}

  \sDC & Press \& release \textit{twice} in quick succession. \\ \drule{2}

  \multirow{2}{*}[-1mm]{$\hskip 3.3mm$ \sPHN{$N$}}
    & Press \& hold for $N$ seconds then release. \\
    & \quad \sPHN{6} $\longrightarrow$ Press \& hold for \num{6} seconds then release. \\ \drule{2}
  \sReset & Press \& hold until \symD{<<<<} is displayed, then release. \\ \drule{2}
  \sSec & Press \& hold until \symD{====} is displayed, then release. \\ \drule{2}
  \sTer & Press \& hold until \symD{>>>>} is displayed, then release. \\

  \mrule
  \pagebreak

  \thrule
  \multicolumn{2}{c}{\textbf{\cTS{n}}} \\ \mrule
  \thbi{Symbol} & \thbi{Description} \\ \mrule

  \sTo & Touch the \cTo{f} of the enclosure with palm of hand. \\ \drule{2}

  \multirow{2}{*}[-1mm]{$\hskip 3.0mm$ \sToN{$N$}} & Touch for $N$ seconds. \\
    & \quad \sToN{5} $\longrightarrow$ Touch for \num{5} seconds. \\ \drule{2}
  \sNTo & Do \textit{not} touch. \\ \drule{2}
  \multirow{2}{*}[-1mm]{$\hskip 3.0mm$ \sNToN{$N$}}
    & Failure to touch \textit{within} $N$ seconds. \\
    & \quad \sNToN{3} $\longrightarrow$ Failure to touch within \num{3} seconds. \\

  \bhrule
\caption{Symbols - Reference}
\end{longtabu}

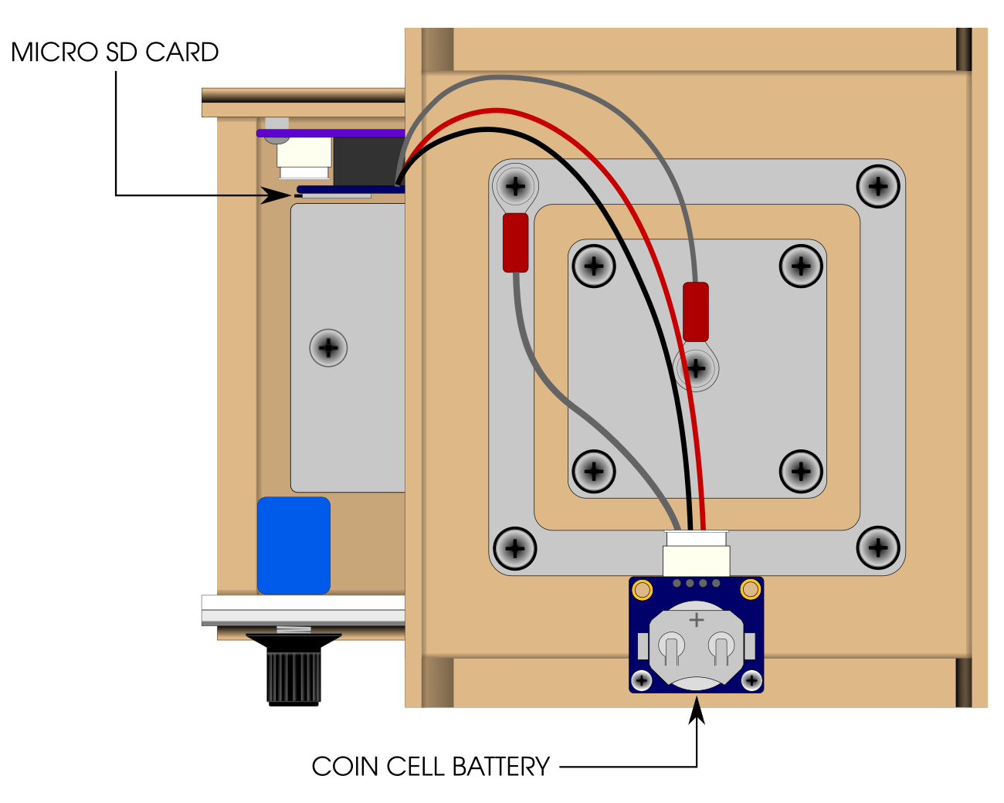
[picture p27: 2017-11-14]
docs/images/disassembly_placement.png

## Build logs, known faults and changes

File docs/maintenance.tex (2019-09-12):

%%%%%%%%%%%%%%%%%%%%%%%%%%%%%%%%%%%%%%%%%%%%%%%%%%%%%%%%%%%%%%%%%%%%%%%%%%%%%%%%%
% Maintenance
%%%%%%%%%%%%%%%%%%%%%%%%%%%%%%%%%%%%%%%%%%%%%%%%%%%%%%%%%%%%%%%%%%%%%%%%%%%%%%%%%
\part{Maintenance} \label{Maintenance}

%%%%%%%%%%%%%%%%%%%%%%%%%%%%%%%%%%%%%%%%%%%%%%%%%%%%%%%%%%%%%%%%%%%%%%%%%%%%%%%%
% Cleaning
%%%%%%%%%%%%%%%%%%%%%%%%%%%%%%%%%%%%%%%%%%%%%%%%%%%%%%%%%%%%%%%%%%%%%%%%%%%%%%%%
\chapter{Cleaning} \label{Cleaning}

A dry or slightly damp rag, preferably microfiber, should be sufficient to get
fingerprints, dust and other crud off of the wood finish and \front{} front.

\par\bigskip

\danger{%
\textbf{\fontTGA{l}{ALCOHOL WILL RUIN THE FINISH} \raisebox{-0.5mm}{\huge !}}
\par\medskip
Do \textit{not} use alcohol or any cleaning solution containing alcohol.  It
will dissolve the shellac finish on the wood.  And to be safe, stay away from
chemical cleaning solutions altogether.}

\par\bigskip

Unless you are just giving it a quick, dry wipe-down, before cleaning:
\begin{enumerate}
  \item Switch the device \sOff{f} using the \hyperref[Power Switch]{\cPo{f}}.
  \item Unplug the \hyperref[Power Adapter]{\cPA{f}} from the
    \hyperref[USB Port]{\cPP{f}}.
\end{enumerate}

%%%%%%%%%%%%%%%%%%%%%%%%%%%%%%%%%%%%%%%%%%%%%%%%%%%%%%%%%%%%%%%%%%%%%%%%%%%%%%%%
% Disassembly
%%%%%%%%%%%%%%%%%%%%%%%%%%%%%%%%%%%%%%%%%%%%%%%%%%%%%%%%%%%%%%%%%%%%%%%%%%%%%%%%
\chapter{Disassembly} \label{Disassembly}

Disassembly should only be necessary once every several years to change the
\cCC{f}.  The \cMSD{f} should last for quite a while and should not need
replacement for many years.

%%%%%%%%%%%%%%%%%%%%%%%%%%%%%%%%%%%%%%%%%%%%%%%%%%%%%%%%%%%%%%%%%%%%%%%%%%%%%%%%
% Disassembly - Warnings
%%%%%%%%%%%%%%%%%%%%%%%%%%%%%%%%%%%%%%%%%%%%%%%%%%%%%%%%%%%%%%%%%%%%%%%%%%%%%%%%
\section{Warnings}

Please read and heed these warnings.  The device can be damaged if you do not.

\danger{Be extra careful when removing the screws.  This can't be stressed
enough.  Righty-tighty, lefty-loosey.  If you right-tighty when you should be
lefty-looseying, the screw \textit{\bfseries will strip} the threads in the
wood.}

\warning{When removing the screws take note of which screws came out of which
holes.  When initially tapping the holes, threads may have been stripped in one
or more of the holes requiring a deeper hole and a longer screw.}

\danger{Take care when lifting the \cTo{f} off.  The wires attaching the \cTS{f}
and \cCC{f} to the \cMi{f} are attached from the \cTo{f} to the circuit board on
the \cBa{f}.  The wires are long enough to take it off, turn it over and set it
on top of the open enclosure.  But the fit may be tight and it may not simply
come off, and pulling it off too abruptly may result in an upward force
proportional to the frictional force that was making it difficult to pull off in
the first place resulting in the wires getting torn from their connections.}

\danger{Be extra careful when reassembling.  As soon as you feel \textit{any}
pressure when turning a screw - \textit{\bfseries stop}.  If you continue, the
threads in the wood \textit{\bfseries will be stripped} and the screw will no
longer hold.}

\danger{When reassembling, do \textit{not} rely on the screws pulling the
enclosure together.  Make sure all pieces are tight and flush \textit{before}
tightening the screws.}

\danger{\textbf{\fontTGA{l}{DO NOT USE POWER TOOLS} \raisebox{-0.5mm}{\huge !}}}

%%%%%%%%%%%%%%%%%%%%%%%%%%%%%%%%%%%%%%%%%%%%%%%%%%%%%%%%%%%%%%%%%%%%%%%%%%%%%%%%
% Disassembly - Tools
%%%%%%%%%%%%%%%%%%%%%%%%%%%%%%%%%%%%%%%%%%%%%%%%%%%%%%%%%%%%%%%%%%%%%%%%%%%%%%%%
\section{Tools}

Only one tool is required - a \mono{3/32"} Hex Driver.  However, it is
recommended that you have handy pencil and paper to keep track of which holes
the screws came out of.

\begin{table}[H]
\ers{1}
\centering
\begin{tabu} { X[1,r,m] | X[6,l,m] }
  \thrule
  \thbi{Quantity} & \thbi{Item} \\ \mrule
  1 & \mono{3/32"} Hex Driver, T-handle or Key \\ \drule{2}
  1 & Pen or pencil \\ \drule{2}
  1 & Piece of paper \\
  \bhrule
\end{tabu}
\end{table}

%%%%%%%%%%%%%%%%%%%%%%%%%%%%%%%%%%%%%%%%%%%%%%%%%%%%%%%%%%%%%%%%%%%%%%%%%%%%%%%%
% Disassembly - Top Removal
%%%%%%%%%%%%%%%%%%%%%%%%%%%%%%%%%%%%%%%%%%%%%%%%%%%%%%%%%%%%%%%%%%%%%%%%%%%%%%%%
\section{Top Removal} \label{Top Removal}

To remove the \cTo{f}, you will need to remove the \num{4} screws that attach
the \cSi{f} to the \cTo{f}.  The order of removal is unimportant.  The \cTo{f}
will then be turned, flipped and placed on top of the enclosure.

\warning{Do the following before proceeding:
\begin{enumerate}
  \item Switch the device \sOff{f} using the \hyperref[Power Switch]{\cPo{f}}.
  \item Unplug the \hyperref[Power Adapter]{\cPA{f}} from the
    \hyperref[USB Port]{\cPP{f}}.
\end{enumerate}}

%%%%%%%%%%%%%%%%%%%%%%%%%%%%%%%%%%%%%%%%%%%%%%%%%%%%%%%%%%%%%%%%%%%%%%%%%%%%%%%%
% Disassembly - Top Removal - Removing the Screws
%%%%%%%%%%%%%%%%%%%%%%%%%%%%%%%%%%%%%%%%%%%%%%%%%%%%%%%%%%%%%%%%%%%%%%%%%%%%%%%%
\subsection{Removing the Screws} \label{Removing the Screws}

The screws used are technically machine screws which are generally used with
metals, however the wood used for the enclosure is sufficiently dense. Machine
screws are used so that the device can be easily taken apart and put back
together - though care must be taken when doing so.

\par\medskip

Utilizing machine screws as opposed to self-tapping wood screws involves a
different process.  First a hole is drilled, much like a pilot hole for a
self-tapping wood screw, but instead of using a screw driver to drive the screw
in, a tap and tap driver is used to create the threads in the hole.

\par\medskip

Despite the wood being very dense, it is very easy to strip the threads if
overtightned - either when loosening and turning the wrong way or when
tightening.  So go slow, very slow, and as soon as you feel
\textit{\bfseries any resistance, stop turning}.

\steps{Removing Screws}{%
\begin{enumerate}
  \item Orient the enclosure so that you are \textit{facing} the screw you
    will be loosening.
  \item Insert the \mono{3/32"} Hex Driver into the head of the screw.
  \item \textit{Slowly} turn \textit{counter-clockwise} until the screw is
    \textit{completely} loosened and pull it out.

  \begin{figure}[H]
  \centering
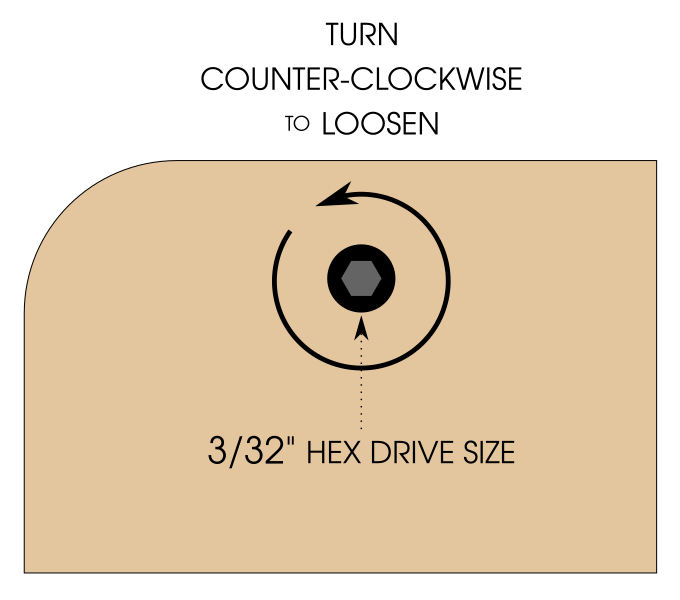
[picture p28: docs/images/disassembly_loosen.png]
    
  %\caption{Disassembly - Loosen Screws}
  \end{figure}

  \item Make a note with pencil and paper of the hole the screw came out of and
    place the screw next to or on top of it.
  \item Repeat the above steps for all screws to be removed.
\end{enumerate}}

\info{If removing the \cMSD{f}, in addition to removing the \num{4} screws
attaching the \cSi{f} to the \cTo{f}, you may need to remove the \num{2} screws
attaching the \cLS{f} to the \cBo{f}.}

%%%%%%%%%%%%%%%%%%%%%%%%%%%%%%%%%%%%%%%%%%%%%%%%%%%%%%%%%%%%%%%%%%%%%%%%%%%%%%%%
% Disassembly - Top Removal - Top Placement
%%%%%%%%%%%%%%%%%%%%%%%%%%%%%%%%%%%%%%%%%%%%%%%%%%%%%%%%%%%%%%%%%%%%%%%%%%%%%%%%
\subsection{Top Placement}

After removing the screws, you will lift the \cTo{f}, turn it over and place
it on top of the enclosure, sitting perpendicular to its attached orientation.

\steps{Top Placement}{%
\begin{enumerate}
  \item \textit{Slowly} pull the \cTo{f} up.  If there is resistance,
    \textit{gently} rock the \cTo{f} from side to side to loosen it until it
    easily detaches.
  \item Lift it \textit{no more} than about \mono{1"} above the enclosure - just
    high enough to be able to turn it perpendicular to the way it is oriented.

  \begin{figure}[H]
  \centering
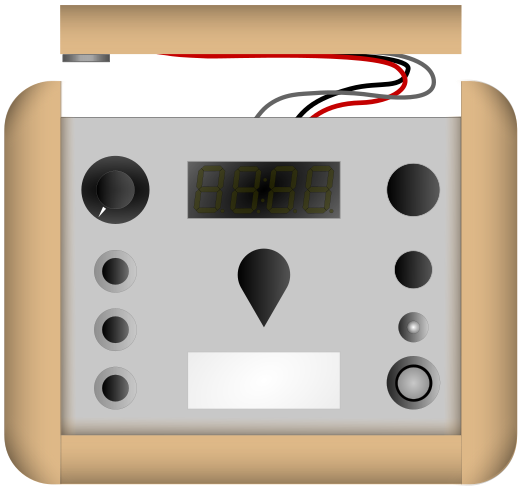
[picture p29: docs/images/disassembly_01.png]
    
  \end{figure}

  \item Facing front and looking down, turn the \cTo{f}
    \textit{counter-clockwise} until it is perpendicular to its attached
    orientation.

  \begin{figure}[H]
  \centering
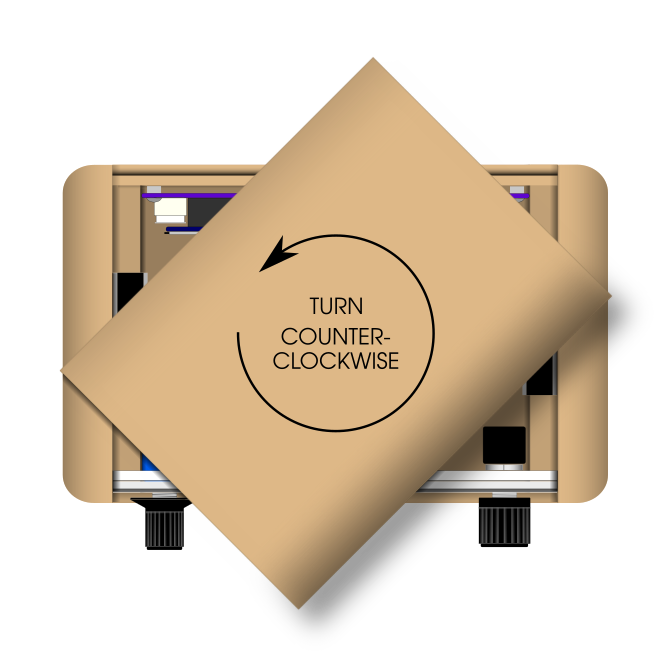
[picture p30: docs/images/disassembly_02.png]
    
  \end{figure}

  \item Facing front, flip the \cTo{f} \textit{clockwise}.

  \begin{figure}[H]
  \centering
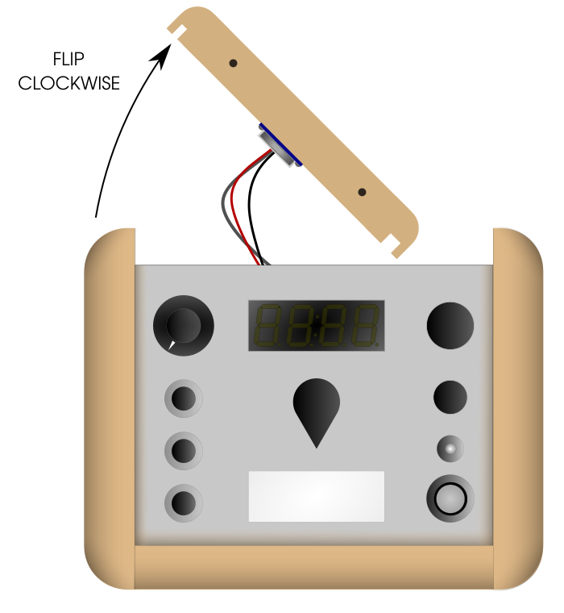
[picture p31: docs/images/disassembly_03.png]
    
  \end{figure}

  \item \textit{Gently} place it on top of the enclosure.

  \begin{figure}[H]
  \centering
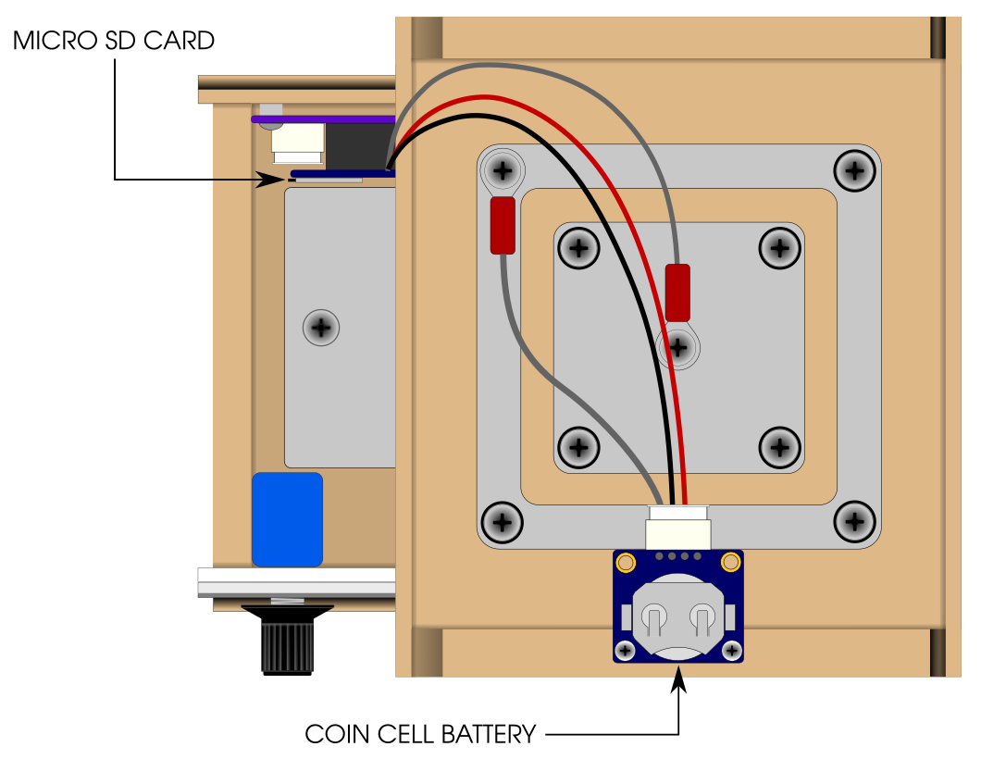
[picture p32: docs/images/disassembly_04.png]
    
  \end{figure}

\end{enumerate}}

%%%%%%%%%%%%%%%%%%%%%%%%%%%%%%%%%%%%%%%%%%%%%%%%%%%%%%%%%%%%%%%%%%%%%%%%%%%%%%%%
% Disassembly - Reassembly
%%%%%%%%%%%%%%%%%%%%%%%%%%%%%%%%%%%%%%%%%%%%%%%%%%%%%%%%%%%%%%%%%%%%%%%%%%%%%%%%
\section{Reassembly} \label{Reassembly}

Place the \cTo{f} and possibly the \cLS{f}, if it was necessary to remove to
get to the \cMSD{f}, back in place.  Make sure all wires are \textit{within} the
enclosure so that they are not crimped when placing the pieces back together and
that all pieces are tight and flush before putting the screws back in and
tightening.

\par\medskip

Again, go slow, very slow, when tightening the screws and as soon as you feel
\textit{\bfseries any resistance, stop turning}.

\steps{Tightening Screws}{%
\begin{enumerate}
  \item Make sure the \cTo{f} and \cSi{f} are tight and flush.
  \item Orient the enclosure so that you are \textit{facing} the screw you
    will be tightening.
  \item Insert the screw into the hole - make sure it is the same screw that
    came out of the hole.
  \item Insert the \mono{3/32"} Hex Driver into the head of the screw.
  \item \textit{Slowly} turn \textit{clockwise}.  As soon as you feel
    \textit{any resistance}, \textit{\bfseries stop} turning.

  \begin{figure}[H]
  \centering
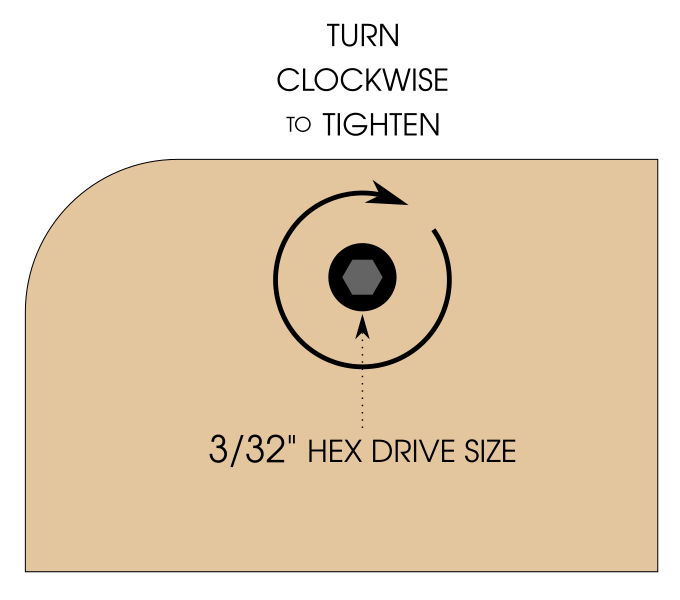
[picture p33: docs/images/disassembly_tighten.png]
    
  %\caption{Reassembly - Tighten Screws}
  \end{figure}

  \item Repeat the above steps for all removed screws.
\end{enumerate}}

%%%%%%%%%%%%%%%%%%%%%%%%%%%%%%%%%%%%%%%%%%%%%%%%%%%%%%%%%%%%%%%%%%%%%%%%%%%%%%%%
% Replacing the Coin Cell Battery
%%%%%%%%%%%%%%%%%%%%%%%%%%%%%%%%%%%%%%%%%%%%%%%%%%%%%%%%%%%%%%%%%%%%%%%%%%%%%%%%
\chapter{Replacing the Coin Cell Battery} \label{Replacing Battery}

Replacing the \hyperref[Coin Cell Battery]{\cCC{f}} shouldn't be necessary for
several years.  It is a \num{CR2032} and is located just underneath the \cTo{f}
on the \textit{left} side.  To access the battery, the \cTo{f} needs to be
removed - refer to the \hyperref[Disassembly]{Disassembly} section for
instructions.

%%%%%%%%%%%%%%%%%%%%%%%%%%%%%%%%%%%%%%%%%%%%%%%%%%%%%%%%%%%%%%%%%%%%%%%%%%%%%%%%
% Replacing the Coin Cell Battery - Parts
%%%%%%%%%%%%%%%%%%%%%%%%%%%%%%%%%%%%%%%%%%%%%%%%%%%%%%%%%%%%%%%%%%%%%%%%%%%%%%%%
\section{Parts}

One \mono{CR2032} coin cell battery is necessary.

\begin{table}[H]
\ers{1}
\centering
\begin{tabu} { X[1,r,m] | X[6,l,m] }
  \thrule
  \thbi{Quantity} & \thbi{Part} \\ \mrule
  1 & \mono{CR2032} (\mono{3\thinspace V}) Coin Cell Battery \\
  \bhrule
\end{tabu}
\end{table}

%%%%%%%%%%%%%%%%%%%%%%%%%%%%%%%%%%%%%%%%%%%%%%%%%%%%%%%%%%%%%%%%%%%%%%%%%%%%%%%%
% Replacing the Coin Cell Battery - Removal
%%%%%%%%%%%%%%%%%%%%%%%%%%%%%%%%%%%%%%%%%%%%%%%%%%%%%%%%%%%%%%%%%%%%%%%%%%%%%%%%
\section{Removal}

To remove the \cCC{f}, simply push it from within the bounds of the \cTo{f}
towards the outside.

\begin{figure}[H]
\centering
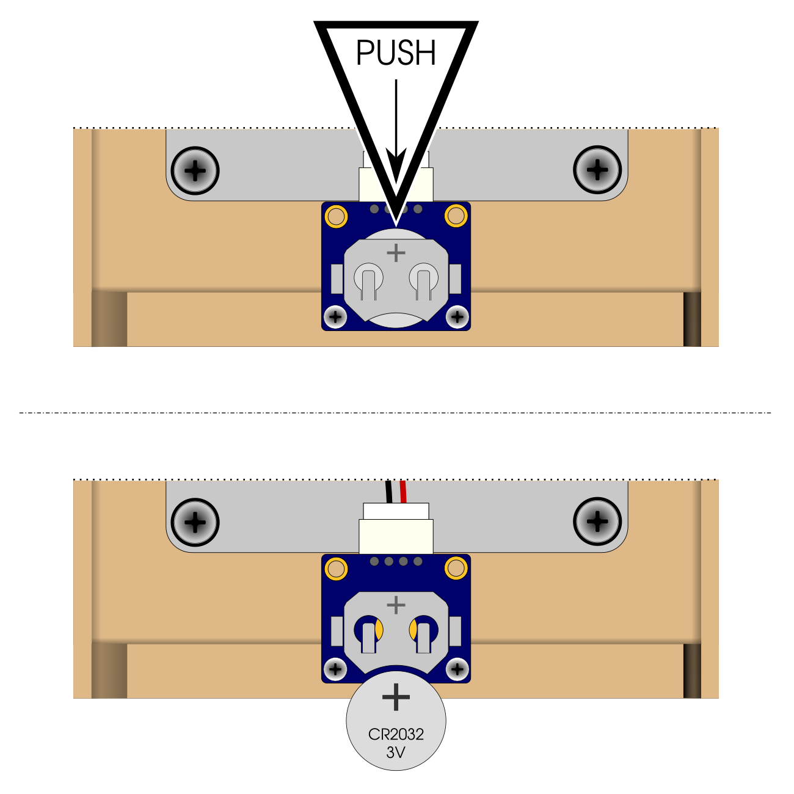
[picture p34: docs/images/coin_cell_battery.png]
  
\caption{Removing the Coin Cell Battery}
\end{figure}

%%%%%%%%%%%%%%%%%%%%%%%%%%%%%%%%%%%%%%%%%%%%%%%%%%%%%%%%%%%%%%%%%%%%%%%%%%%%%%%%
% Replacing the Coin Cell Battery - Insertion
%%%%%%%%%%%%%%%%%%%%%%%%%%%%%%%%%%%%%%%%%%%%%%%%%%%%%%%%%%%%%%%%%%%%%%%%%%%%%%%%
\section{Insertion} \label{SD Insertion}

\danger{When inserting the new battery, orientation is critical.  If the
polarity is reversed, damage may occur.}

Before inserting the new battery, make sure the
\begin{tikzpicture}[baseline=-4]
  \draw[fill=black!20] (0,0) circle [radius=0.4] node[anchor=center] {\textbf{\Large{$+$}}};
\end{tikzpicture}
or positive side of the battery is \textit{facing up}.  After verifying this,
simply push it in the way it came out.

%%%%%%%%%%%%%%%%%%%%%%%%%%%%%%%%%%%%%%%%%%%%%%%%%%%%%%%%%%%%%%%%%%%%%%%%%%%%%%%%
% Removing the Micro SD Card
%%%%%%%%%%%%%%%%%%%%%%%%%%%%%%%%%%%%%%%%%%%%%%%%%%%%%%%%%%%%%%%%%%%%%%%%%%%%%%%%
\chapter{Removing the Micro SD Card} \label{Removing SD Card}

%Though it's possible and relatively easy to do, the device was not conceived
%to add and remove songs from the \cMSD{f}.

The \cMSD{f} is held in place by a spring clip attached to a part on the circuit
board.  Removal involves pushing the card inward until you hear a
\textit{click}, then releasing.  The card will be partially pushed out by the
spring clip.  You can then pull the card out the rest of the way.  To put the
card back in, push until you hear a \textit{click} and it will catch into place.
Verify that it is in place by gently pulling on it - it should \textit{not} pull
out.

\par\medskip

Before the \cMSD{f} can be removed, the enclosure needs to be partially
disassembled - refer to \hyperref[Disassembly]{Disassembly} for instructions.

\info{You may need to detach the \cLS{f} to get to the card.  If so remove the
\num{2} screws that attach the \cLS{f} to the \cBo{f} in addition to the \num{4}
that attach the \cSi{f} to the \cTo{f} -
see \hyperref[Removing the Screws]{Removing the screws} in the
\hyperref[Top Removal]{Top Removal} section.}

\begin{figure}[H]
\centering
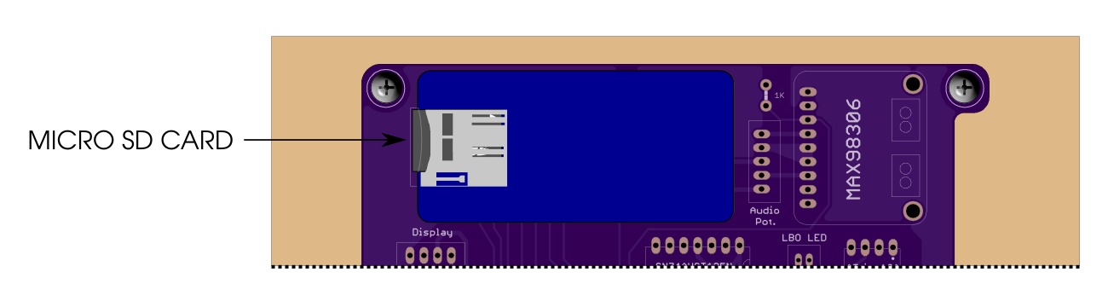
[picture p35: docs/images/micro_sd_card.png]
  
\caption{Micro SD Card - Location}
\end{figure}

%%%%%%%%%%%%%%%%%%%%%%%%%%%%%%%%%%%%%%%%%%%%%%%%%%%%%%%%%%%%%%%%%%%%%%%%%%%%%%%%
% Removing the Micro SD Card - Removal
%%%%%%%%%%%%%%%%%%%%%%%%%%%%%%%%%%%%%%%%%%%%%%%%%%%%%%%%%%%%%%%%%%%%%%%%%%%%%%%%
\pagebreak
\section{Removal} \label{SD Removal}

\steps{Micro SD Card Removal}{%
\begin{enumerate}
  \item Push the \cMSD{f} inward until you hear a \textit{click}.
    \begin{figure}[H]
    \centering
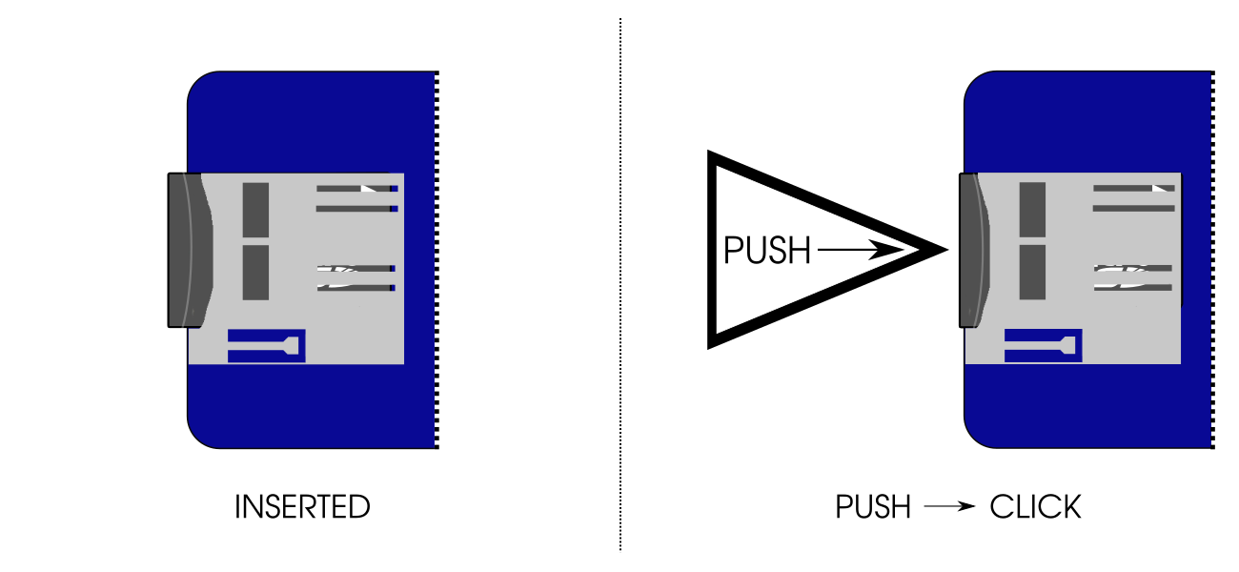
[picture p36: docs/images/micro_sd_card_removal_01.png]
      
    \end{figure}
    \par\bigskip
  \item Release and the card will be partially pushed out.
    \begin{figure}[H]
    \centering
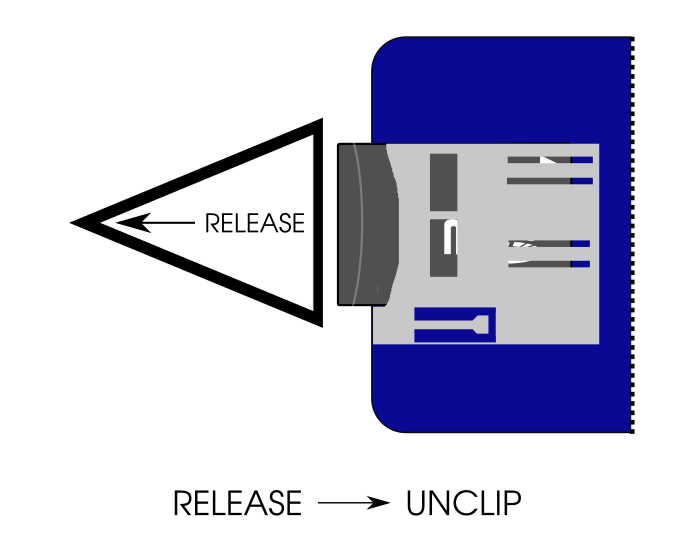
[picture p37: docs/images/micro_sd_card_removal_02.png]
      
    \end{figure}
    \par\bigskip
  \pagebreak
  \item Pull the card out the rest of the way.
    \begin{figure}[H]
    \centering
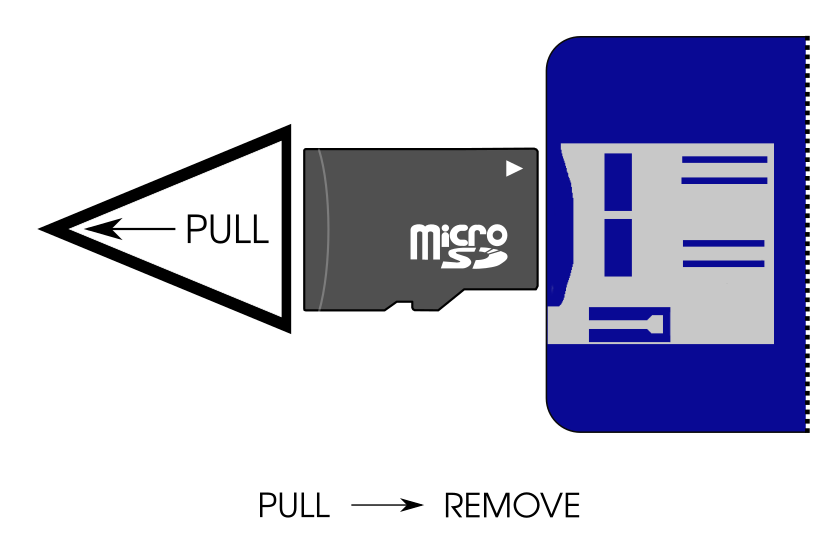
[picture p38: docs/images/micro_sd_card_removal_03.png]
      
    \end{figure}
\end{enumerate}}

%%%%%%%%%%%%%%%%%%%%%%%%%%%%%%%%%%%%%%%%%%%%%%%%%%%%%%%%%%%%%%%%%%%%%%%%%%%%%%%%
% Removing the Micro SD Card - Insertion
%%%%%%%%%%%%%%%%%%%%%%%%%%%%%%%%%%%%%%%%%%%%%%%%%%%%%%%%%%%%%%%%%%%%%%%%%%%%%%%%
\section{Insertion}

\steps{Micro SD Card Insertion}{%
\begin{enumerate}
  \item Push the \cMSD{f} inward until you hear a \textit{click}.
    \begin{figure}[H]
    \centering
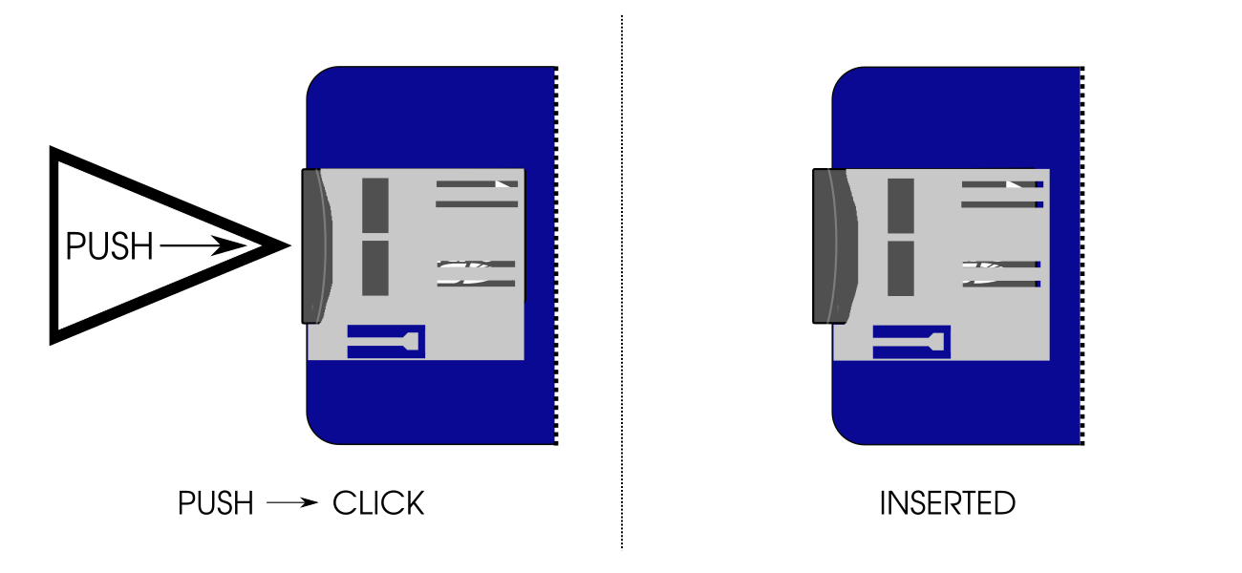
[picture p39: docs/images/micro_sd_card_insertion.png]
      
    \end{figure}
\end{enumerate}}

\iffalse
% Adding USB capability deprecates the following section which requires
% removing the microSD card in order to add and remove songs.  However,
% do not remove it in case USB capability is not compiled in.
 
%%%%%%%%%%%%%%%%%%%%%%%%%%%%%%%%%%%%%%%%%%%%%%%%%%%%%%%%%%%%%%%%%%%%%%%%%%%%%%%%
% Removing the Micro SD Card - Adding / Removing Songs
%%%%%%%%%%%%%%%%%%%%%%%%%%%%%%%%%%%%%%%%%%%%%%%%%%%%%%%%%%%%%%%%%%%%%%%%%%%%%%%%
\pagebreak
\section{Adding / Removing Songs} \label{Add Songs}

Disassembly is primarily meant for maintenance and changing the \cCC{f}
and should \textit{not} be done often.  Unfortunately the only way to
add / remove songs from the \cMSD{f} is to partially disassemble the enclosure
- see \hyperref[Disassembly]{Disassembly} for instructions.

\par\medskip

There are a number of ways to add files to the \cMSD{f}.  It will be assumed
that a desktop or laptop computer with a windowed environment is being used
such as a Mac or Windows.

%%%%%%%%%%%%%%%%%%%%%%%%%%%%%%%%%%%%%%%%%%%%%%%%%%%%%%%%%%%%%%%%%%%%%%%%%%%%%%%%
% Removing the Micro SD Card - Adding / Removing Songs - Preparation
%%%%%%%%%%%%%%%%%%%%%%%%%%%%%%%%%%%%%%%%%%%%%%%%%%%%%%%%%%%%%%%%%%%%%%%%%%%%%%%%
\subsection{Preparation}

Preparation involves partially disassembling the enclosure, removing the
\cMSD{f} from the holder on the circuit board and attaching the card to a
computer.

\steps{Preparation}{%
\begin{enumerate}
  \item Partially disassemble the enclosure - refer to
    \hyperref[Disassembly]{Disassembly} for instructions.
  \item Remove the \cMSD{f} - refer to \hyperref[SD Removal]{Removal} for
    instructions.
  \item Insert the card into the computer.  There are a couple of ways this
    may be accomplished.
    \begin{itemize}
      \item If your computer has a built-in \cMSD{f} reader, you should be
        able to use that.
      \item Use a USB card reader.\footnote{ One that I have used without issue
        is \mono{Transcend RDF5}.}  After inserting the card into the reader,
        insert the reader into a USB port on the computer.
    \end{itemize}
  \item The card should be recognized as a disk volume on the computer.  The
    card that comes pre-installed is named \mono{MUSIC}.  Open a window that
    shows the contents of the disk.
\end{enumerate}}

%%%%%%%%%%%%%%%%%%%%%%%%%%%%%%%%%%%%%%%%%%%%%%%%%%%%%%%%%%%%%%%%%%%%%%%%%%%%%%%%
% Removing the Micro SD Card - Adding / Removing Songs - Adding Files
%%%%%%%%%%%%%%%%%%%%%%%%%%%%%%%%%%%%%%%%%%%%%%%%%%%%%%%%%%%%%%%%%%%%%%%%%%%%%%%%
\subsection{Adding Songs} \label{Adding Songs}

Adding songs involves copying \mono{MP3} or \mono{M4A} music files that are on
a computer to the \cMSD{f}.

\warning{The files \textit{must} be \mono{MPEG-2 Audio Layer III} (\mono{MP3})
or \mono{MPEG-4 Audio}\footnote{ Used primarily by iTunes.} (\mono{M4A}) files
and they \textit{must} have an \mono{.mp3} or \mono{.m4a} file extension.
Files that are \textit{not} \mono{MP3} or \mono{M4A} and that do \textit{not}
have either of the two file extensions in the file name will \textit{not} work.}

\steps{Adding Songs}{%
\begin{enumerate}
  \item Open another window that has the songs you want to add.
  \item Drag and drop the \mono{MP3} and/or \mono{M4A} files you want to add
    onto the \cMSD{f} volume.
    \par\medskip
    Note that the disk has no concept of sorting and the order in which the
    songs are ``sorted'' on the disk is the order in which they are added to
    the disk.  If you want the songs to be played in a specific order,
    add them \textit{one at a time} to the \cMSD{f}.
\end{enumerate}}

%%%%%%%%%%%%%%%%%%%%%%%%%%%%%%%%%%%%%%%%%%%%%%%%%%%%%%%%%%%%%%%%%%%%%%%%%%%%%%%%
% Removing the Micro SD Card - Adding / Removing Songs - Removing Files
%%%%%%%%%%%%%%%%%%%%%%%%%%%%%%%%%%%%%%%%%%%%%%%%%%%%%%%%%%%%%%%%%%%%%%%%%%%%%%%%
\subsection{Removing Songs}

Removing songs simply involves deleting the files from the \cMSD{f}.

\steps{Removing Songs}{%
\begin{enumerate}
  \item Delete or ``Move to Trash'' the files you want removed from the
    \cMSD{f} volume.
\end{enumerate}}

%%%%%%%%%%%%%%%%%%%%%%%%%%%%%%%%%%%%%%%%%%%%%%%%%%%%%%%%%%%%%%%%%%%%%%%%%%%%%%%%
% Removing the Micro SD Card - Adding / Removing Songs - Finishing
%%%%%%%%%%%%%%%%%%%%%%%%%%%%%%%%%%%%%%%%%%%%%%%%%%%%%%%%%%%%%%%%%%%%%%%%%%%%%%%%
\subsection{Finishing}

Finishing involves ejecting then physically removing the \cMSD{f} from the
computer, putting it back in the holder on the circuit board and closing up the
enclosure.

\steps{Finishing}{%
\begin{enumerate}
  \item Safely remove or eject the \cMSD{f}. This is \textit{not} physical
    removal but tells the computer to finish any possible pending
    operations, such as writes to the disk, \textit{before} physical removal.
  \item Physically remove the \cMSD{f} from the computer.
  \item Reinsert the \cMSD{f} back into the holder on the circuit board -
    refer to \hyperref[SD Insertion]{Insertion} for instructions.
  \item Reassemble the enclosure - refer to \hyperref[Reassembly]{Reassembly}
    for instructions.
\end{enumerate}}
% Adding USB capability deprecates the above section which requires
% removing the microSD card in order to add and remove songs.  However,
% do not remove it in case USB capability is not compiled in.
\fi

%%%%%%%%%%%%%%%%%%%%%%%%%%%%%%%%%%%%%%%%%%%%%%%%%%%%%%%%%%%%%%%%%%%%%%%%%%%%%%%%
% Removing the Micro SD Card - Replace SD Card
%%%%%%%%%%%%%%%%%%%%%%%%%%%%%%%%%%%%%%%%%%%%%%%%%%%%%%%%%%%%%%%%%%%%%%%%%%%%%%%%
\pagebreak
\section{Replacement} \label{Replace SD Card}

The \cMSD{f} may eventually fail and need to be replaced.  This section will
only focus on formatting the new card.  See the
\hyperref[Disassembly]{Disassembly} section and the preceding sections for
removing the card from the enclosure.

\par\medskip

The new card must meet these requirements.

\begin{itemize}
  \item The card \textit{must} have at least a \num{90} \mono{MB/sec} read
    speed, \textit{and}
  \item The card \textit{must} be formatted with the \mono{FAT32} filesystem
    using \num{512} bytes per sector.
\end{itemize}

\warning{If the read speed of the card is less than \num{90} \mono{MB/sec}, the
audio may stutter and not play correctly.}

\danger{If the card is not formatted with the \mono{FAT32} filesystem using
\num{512} bytes per sector, the device will \textit{not} be able to read the
card.}

%%%%%%%%%%%%%%%%%%%%%%%%%%%%%%%%%%%%%%%%%%%%%%%%%%%%%%%%%%%%%%%%%%%%%%%%%%%%%%%%
% Removing the Micro SD Card - Replace SD Card - Parts
%%%%%%%%%%%%%%%%%%%%%%%%%%%%%%%%%%%%%%%%%%%%%%%%%%%%%%%%%%%%%%%%%%%%%%%%%%%%%%%%
\subsection{Parts}

One Micro SD Card with at least a \num{90} \mono{MB/sec} read speed specification
is needed.

\begin{table}[H]
\ers{1}
\centering
\begin{tabu} { X[1,r,m] | X[6,l,m] }
  \thrule
  \thbi{Quantity} & \thbi{Part} \\ \mrule
  1 & Micro SD Card w/ \num{90} \mono{MB/sec} or more Read Speed \\
  \bhrule
\end{tabu}
\end{table}

A Micro SD Card is distinguished from a normal SD card and the Mini SD Card in
that it is the smallest of the three.

\begin{figure}[H]
\centering
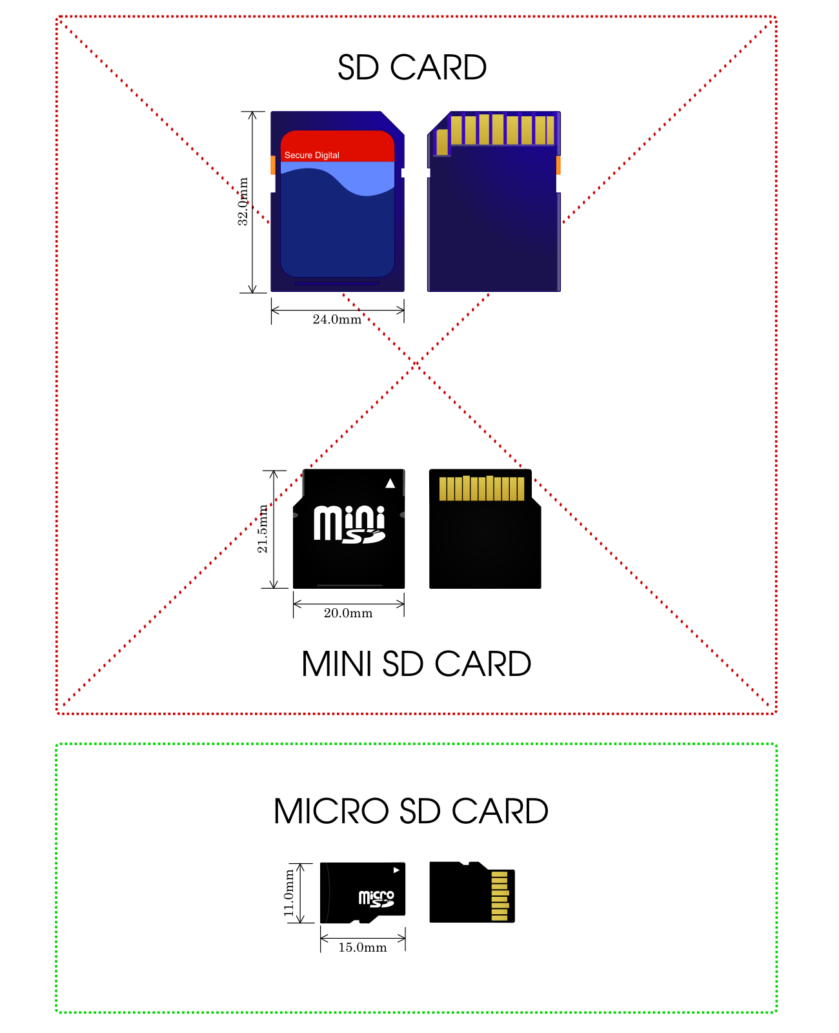
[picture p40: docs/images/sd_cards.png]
  
\caption{SD Cards}
\end{figure}

%%%%%%%%%%%%%%%%%%%%%%%%%%%%%%%%%%%%%%%%%%%%%%%%%%%%%%%%%%%%%%%%%%%%%%%%%%%%%%%%
% Removing the Micro SD Card - Replace SD Card - Formatting
%%%%%%%%%%%%%%%%%%%%%%%%%%%%%%%%%%%%%%%%%%%%%%%%%%%%%%%%%%%%%%%%%%%%%%%%%%%%%%%%
\subsection{Formatting}

It is recommended that the
\href{https://www.sdcard.org/downloads/formatter\_4/}{SD Memory Card Formatter}
application be used to format the card.  It is provided for free by the
\href{https://www.sdcard.org/index.html}{SD Association}.  The following will
assume use of this application.

\steps{Download \& Open}{%
\begin{enumerate}
  \item Download the \textit{SD Memory Card Formatter} application from
    \url{https://www.sdcard.org/downloads/formatter\_4/}.  It is available
    for both Windows and Mac so make sure you choose the appropriate download
    for your operating system.
  \item Insert the new \cMSD{f} into the computer.
  \item Open the \textit{SD Memory Card Formatter} application.
\end{enumerate}}

\begin{figure}[H]
\centering
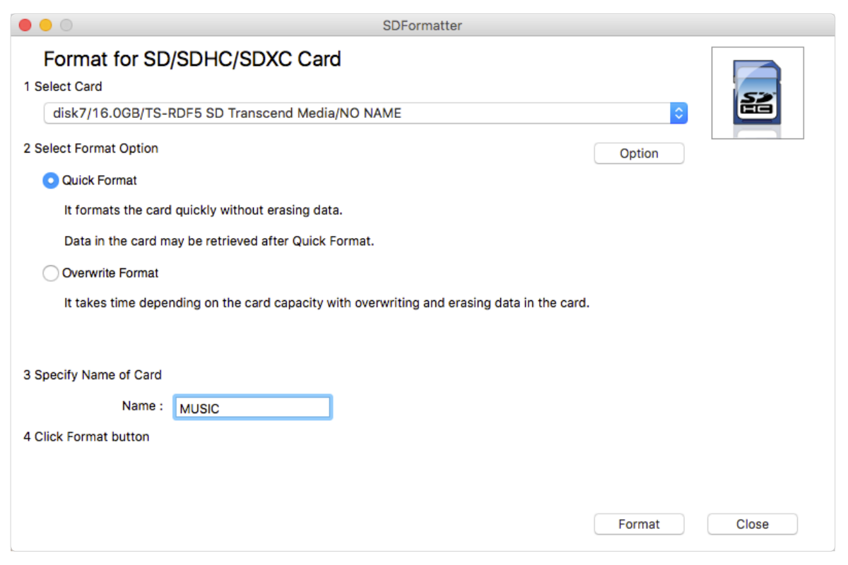
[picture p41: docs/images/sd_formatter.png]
  
\caption{Micro SD Card - SD Memory Card Formatter}
\end{figure}

The window is partitioned into \num{4} sections which will correspond to the
next steps.  Make sure when selecting the card in the first step, that you
select the card you just inserted.  If you select a different card, all of
its contents will be erased.

\danger{Selecting the wrong card will result in erasing the contents
of that card.}

\begin{figure}[H]
\centering
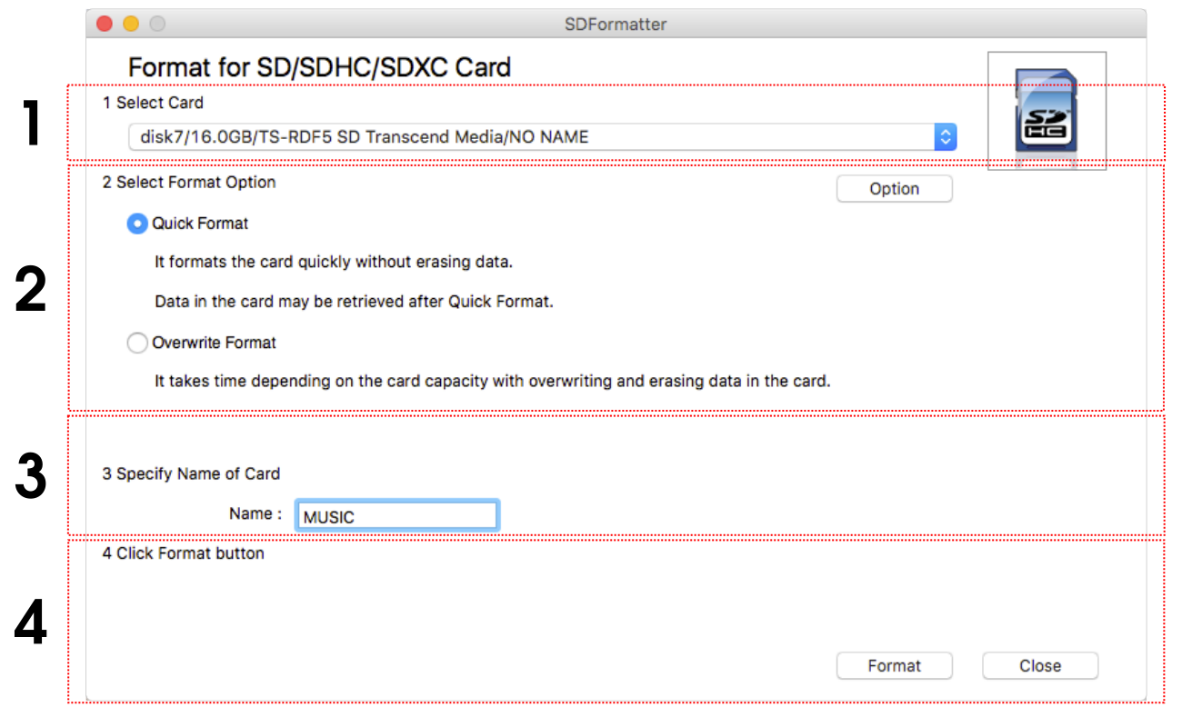
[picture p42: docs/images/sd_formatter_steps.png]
  
\caption{Micro SD Card - Formatting}
\end{figure}

\steps{Format}{%
\begin{enumerate}
  \item \textbf{Select Card} \newline
    Select the card you just inserted from the drop-down menu at the top.  If
    there is more than one choice, make sure you choose the correct card.
  \item \textbf{Select Format Option} \newline
    Leave this alone.
  \item \textbf{Specify Name of Card} \newline
    You can name this anything you like.
  \item \textbf{Click Format button} \newline
    Click on the \cCol{white}{black}{Format}\thinspace button in the lower right.
    Formatting should not take long and when it's finished you should see some
    \textit{blue} text underneath the option indicating success.
\end{enumerate}}

\begin{figure}[H]
\centering
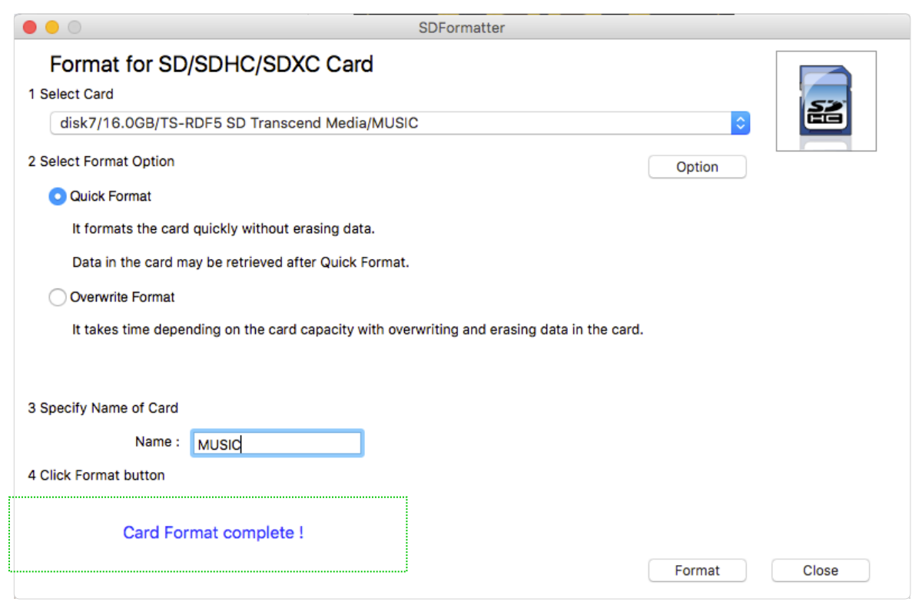
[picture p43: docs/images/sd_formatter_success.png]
  
\caption{Micro SD Card - Formatting Success}
\end{figure}

You can either install the card back in the device or add music directly to the
card while it is out of the device.  Adding songs now will likely be
significantly faster than adding them when the card is in the device, so if
there is a sizeable amount of songs you want to add, it is advisable to add them
now.  See \hyperref[Adding Songs]{Adding Songs} in the \hyperref[USB]{\mUsb{f}}
section.

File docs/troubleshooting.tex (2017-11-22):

%%%%%%%%%%%%%%%%%%%%%%%%%%%%%%%%%%%%%%%%%%%%%%%%%%%%%%%%%%%%%%%%%%%%%%%%%%%%%%%%
% Troubleshooting
%%%%%%%%%%%%%%%%%%%%%%%%%%%%%%%%%%%%%%%%%%%%%%%%%%%%%%%%%%%%%%%%%%%%%%%%%%%%%%%%
\part{Troubleshooting} \label{Troubleshooting}

%%%%%%%%%%%%%%%%%%%%%%%%%%%%%%%%%%%%%%%%%%%%%%%%%%%%%%%%%%%%%%%%%%%%%%%%%%%%%%%%
% Common Issues
%%%%%%%%%%%%%%%%%%%%%%%%%%%%%%%%%%%%%%%%%%%%%%%%%%%%%%%%%%%%%%%%%%%%%%%%%%%%%%%%
\chapter{Common Issues} \label{Common Issues}

The following table lists common issues, their severity and possible
resolutions.

\ers{5}
\begin{longtabu} { X[5,l,m] | X[2,c,m] | X[7,l,m] }
  \thrule

  \thbi{Problem} & \thbi{Severity} & \thbi{Solution} \\ \mdrule

  Speakers pop when turning the \mAu{f} on.
    & \sNormal{sym}
    & Turn the \cVo{f} down before turning the \mAu{f} on. \\ \mrule

  The \cDi{f} shows remnants when switched \sOn{f}.
    & \sNormal{sym}
    & The \cDi{f} is getting power initially before it can display what
      it should.  Nothing to be done. \\ \mrule

  The \cLB{f} flickers.
    & \sNormal{sym}
    & \parbox{\linewidth}{Try turning the \cVo{f} down if the \mAu{f}
      is playing and recharge.  See
      \hyperref[Low Battery Indicator]{Low Battery Indicator} and
      \hyperref[Powering and Recharging]{Powering \& Recharging}.} \\ \mrule

  You see \symD{OFF!} displayed but didn't do anything.
    & \sNormal{sym}
    & The \mAl{f} was turned off due to \textit{Wake Time} exceeded or
      \textit{Total Alarm Time} exceeded. \\ \mrule

  \multirow{2}{5cm}[-1.5mm]{The device becomes unresponsive and seems frozen.}
    & \multirow{2}{*}[-1.5mm]{\sMedium{sym}}
    & Switch the device \sOff{f} then back \sOn{f} using the
      \hyperref[Power Switch]{\cPo{f}}. \\
    & & \parbox{\linewidth}
      {\footnotesize This is a bug that I have been unable to reproduce and
       therefore unable to resolve which occurred twice during four months of
       usage.} \strut \\ \mrule

  \pagebreak
  \mrule

  \multirow{3}{*}[-14mm]{\parbox{\linewidth}{You try to play a track and hear nothing.}}
    & \sLow{sym}
    & Try turning the \cVo{f} up. \\ \dcrule{2}{3}
  & \sMedium{sym}
    & \parbox{\linewidth}{\par\bigskip There may be a file that for some reason is
      unreadable.\footnote{ It could be that though the file has the correct extension,
      it isn't actually the type of file the extension would indicate.} Try
      picking another track.  If multiple tracks don't play then it may be a
      problem with the \cMSD{f} - see below. \par\bigskip} \\ \dcrule{2}{3}
  & \sHigh{sym}
    & The \cMSD{f} is formatted incorrectly or has failed.  See
    \hyperref[Removing SD Card]{Removing the Micro SD Card} for more
    information. \\ \mrule

  An error code and string are shown on the \cDi{f}.
    & \sHigh{sym}
    & See the \hyperref[Error Codes]{Errors} section. \\

  \bhrule
\caption{Troubleshooting Common Issues}
\end{longtabu}

%%%%%%%%%%%%%%%%%%%%%%%%%%%%%%%%%%%%%%%%%%%%%%%%%%%%%%%%%%%%%%%%%%%%%%%%%%%%%%%%
% Errors
%%%%%%%%%%%%%%%%%%%%%%%%%%%%%%%%%%%%%%%%%%%%%%%%%%%%%%%%%%%%%%%%%%%%%%%%%%%%%%%%
\chapter{Errors} \label{Error Codes}

Listed below are all of the possible errors that the device can recognize.  In
the event that you see one show up on the \cDi{f}, try the following.

\begin{itemize}
  \item \aTu{f} or \aPr{f} the \cEs{f} or \aTu{f} the \cRs{f} or fiddle with
    some other control on the \cFr{f} or \aTo{f} the \cTo{f} if the \cTS{f} is
    enabled.
\end{itemize}

If the error on the \cDi{f} doesn't go away or the problem continues to persist:

\begin{itemize}
  \item Switch the device \sOff{f} then back \sOn{f} using the \cPo{f}.
\end{itemize}

Again, if the error doesn't go away or the problem continues to persist, refer
to the following sections.

\info{If you are unable to resolve the problem or the device is unusable because
of the problem, please send the device back for repair.  Almost every part is
replaceable.}

\ers{3}
\begin{longtabu} { X[1,c,m] | X[1,c,m] | X[4,l,m] | }
  \thrule

  \thbi{Error Code} & \thbi{Error String} & \thbi{Description} \\ \mrule

  \sDl{!!!1}
    & \sDl{C.SEL.}
    & Problem with the \cRs{f}. \\ \mrule

  \sDl{!!!2}
    & \sDl{C.SEt.}
    & Problem with the \cEs{f}. \\ \mrule

  \sDl{!!!3}
    & \sDl{C.br.!}
    & Problem with the \cBr{f}. \\ \mrule

  \sDl{!!!4}
    & \sDl{C.PLA.}
    & Problem with \cPl{f} push-button. \\ \mrule

  \sDl{!!!5}
    & \sDl{C.nE.!}
    & Problem with \cNe{f} push-button. \\ \mrule

  \sDl{!!!6}
    & \sDl{C.PrE.}
    & Problem with \cPr{f} push-button. \\ \mrule

  \sDl{!!!7}
    & \sDl{BEEP}
    & Problem with the \cBe{f}. \\ \mrule

  \sDl{!!!8}
    & \sDl{dISP.}
    & Problem with the \cDi{f} - may not show. \\ \mrule

  \sDl{!!!9}
    & \sDl{LEdS}
    & Problem with the \cLi{f}. \\ \mrule

  \sDl{!!10}
    & \sDl{tUCH}
    & Problem with the \cTS{f}. \\ \mrule

  \sDl{!!11}
    & \sDl{FILE}
    & Problem with the \cMSD{f} or filesystem on the \cMSD{f}. \\ \mrule

  \sDl{!!12}
    & \sDl{Aud.!}
    & Problem with audio decoder or amplifier. \\ \mrule

  \sDl{!!13}
    & \sDl{PLAY}
    & The \mAu{f} is disabled. \\ \mrule

  \sDl{!!14}
    & \sDl{P.FIL.}
    & Problem obtaining audio files from the \cMSD{f}. \\ \mrule

  \sDl{!!15}
    & \sDl{P.OPE.}
    & Problem opening an audio file on the \cMSD{f}. \\ \mrule

  \sDl{!!16}
    & \sDl{P.Aud.}
    & Problem communicating with audio decoder or reading a file. \\ \mrule

  \sDl{!!17}
    & \sDl{T.PIt.}
    & Problem getting access to timer. \\

  \bhrule
\caption{Error Codes}
\end{longtabu}

\section{Hardware}

This class of error indicates a problem with the hardware.  There are a
few possibilities as to the cause:

\begin{enumerate}
  \item The named piece of hardware has failed.
  \item The microcontroller has failed.
  \item The \textit{connection} between the named piece of hardware and
    microcontroller has been severed.  This could be a due to a couple
    or reasons:
    \begin{itemize}
      \item A cable that connects the named piece of hardware to the
        circuit board is disconnected or severed, \textit{or}
      \item A solder connection or trace on the circuit board has gone bad.
    \end{itemize}
  \item The named piece of hardware is actually working which likely points to a
    bug in the software.
\end{enumerate}

It is also possible that a piece of hardware could be malfunctioning without
any error showing up on the \cDi{f}.

%%%%%%%%%%%%%%%%%%%%%%%%%%%%%%%%%%%%%%%%%%%%%%%%%%%%%%%%%%%%%%%%%%%%%%%%%%%%%%%%
% Controls
%%%%%%%%%%%%%%%%%%%%%%%%%%%%%%%%%%%%%%%%%%%%%%%%%%%%%%%%%%%%%%%%%%%%%%%%%%%%%%%%
\subsection{Controls}

If there is a problem with one of the controls, first check to see if the
cable connecting the control to the circuit board is disconnected or severed.
Refer to \hyperref[Disassembly]{Disassembly} for instructions on removing the
\cTo{f}.

%%%%%%%%%%%%%%%%%%%%%%%%%%%%%%%%%%%%%%%%%%%%%%%%%%%%%%%%%%%%%%%%%%%%%%%%%%%%%%%%
% Controls - Selector Dial
%%%%%%%%%%%%%%%%%%%%%%%%%%%%%%%%%%%%%%%%%%%%%%%%%%%%%%%%%%%%%%%%%%%%%%%%%%%%%%%%
\subsubsection{Selector Dial}

\sD{!!!1} \sD{C.SEL.}

\par\bigskip

The side of the cable that is connected to the \cRs{f} is soldered.  There
are \num{4} connections to the \cRs{f}.  If any one of these is disconnected
then the problem is likely one of connection and \textit{not} due to the
\cRs{f} itself being broken.

\par\medskip

The side of the cable that is connected to the circuit board is a very secure
connection, however, it is possible that a solder joint that connects the
female connector to the circuit board has failed.

%%%%%%%%%%%%%%%%%%%%%%%%%%%%%%%%%%%%%%%%%%%%%%%%%%%%%%%%%%%%%%%%%%%%%%%%%%%%%%%%
% Controls - Settings Knob
%%%%%%%%%%%%%%%%%%%%%%%%%%%%%%%%%%%%%%%%%%%%%%%%%%%%%%%%%%%%%%%%%%%%%%%%%%%%%%%%
\subsubsection{Settings Knob} \label{Errors - Settings Knob}

\sD{!!!2} \sD{C.SEt.}

\par\bigskip

The cable connecting the \cEs{f} is terminated with a connector that slides
over the pins of the \cEs{f}.  If this is disconnected, try reconnecting it.
The figure below shows how the cable should be oriented, with the
\textit{red} cable on the \textit{bottom}.

\begin{figure}[H]
\centering
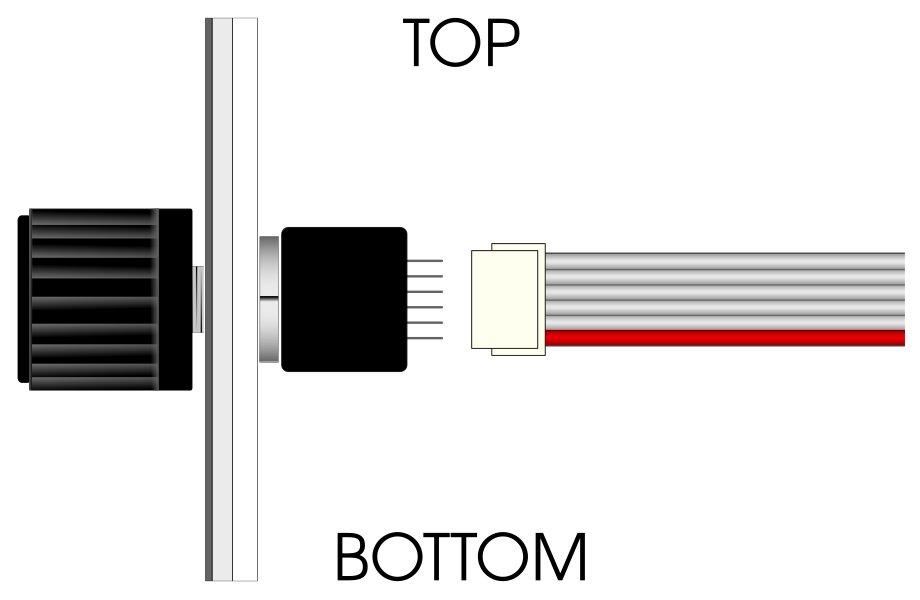
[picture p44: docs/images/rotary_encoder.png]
  
\caption{Settings Knob and Brightness Knob Cable Alignment} \label{fig:Encoder Cable}
\end{figure}

\par\medskip

The side of the cable that is connected to the circuit board is a very secure
connection, however, it is possible that a solder joint that connects the
female connector to the circuit board has failed.

\par\medskip

If the \cEs{f} responds to turning but \textit{not} to pressing, then the
problem may be due to the circuitry that does switch debouncing.

%%%%%%%%%%%%%%%%%%%%%%%%%%%%%%%%%%%%%%%%%%%%%%%%%%%%%%%%%%%%%%%%%%%%%%%%%%%%%%%%
% Controls - Brightness Knob
%%%%%%%%%%%%%%%%%%%%%%%%%%%%%%%%%%%%%%%%%%%%%%%%%%%%%%%%%%%%%%%%%%%%%%%%%%%%%%%%
\subsubsection{Brightness Knob}

\sD{!!!3} \sD{C.br.!}

\par\bigskip

The cable connecting the \cEs{f} is terminated with a connector that slides
over the pins of the \cEs{f}.  If this is disconnected, try reconnecting it.
See the \hyperref[fig:Encoder Cable]{Figure \ref*{fig:Encoder Cable}}
in \hyperref[Errors - Settings Knob]{Settings Knob} above for how the
cable should be aligned.

\par\medskip

The side of the cable that is connected to the circuit board is a very secure
connection, however, it is possible that a solder joint that connects the
female connector to the circuit board has failed.

%%%%%%%%%%%%%%%%%%%%%%%%%%%%%%%%%%%%%%%%%%%%%%%%%%%%%%%%%%%%%%%%%%%%%%%%%%%%%%%%
% Controls - Play | Pause | Stop
%%%%%%%%%%%%%%%%%%%%%%%%%%%%%%%%%%%%%%%%%%%%%%%%%%%%%%%%%%%%%%%%%%%%%%%%%%%%%%%%
\subsubsection{Play | Pause | Stop}

\sD{!!!4} \sD{C.PLA.}

\par\bigskip

The side of the cable that is connected to the \cPl{f} push-button is soldered.
There are \num{2} connections to the \cPl{f} push-button.  If any one of these
is disconnected then the problem is likely one of connection and \textit{not}
due to the \cPl{f} push-button itself being broken.

\par\medskip

The side of the cable that is connected to the circuit board is a very secure
connection, however, it is possible that a solder joint that connects the
female connector to the circuit board has failed.

\par\medskip

The problem may also be due to the circuitry that does switch debouncing.

%%%%%%%%%%%%%%%%%%%%%%%%%%%%%%%%%%%%%%%%%%%%%%%%%%%%%%%%%%%%%%%%%%%%%%%%%%%%%%%%
% Controls - Next
%%%%%%%%%%%%%%%%%%%%%%%%%%%%%%%%%%%%%%%%%%%%%%%%%%%%%%%%%%%%%%%%%%%%%%%%%%%%%%%%
\subsubsection{Next}

\sD{!!!5} \sD{C.nE.!}

\par\bigskip

The side of the cable that is connected to the \cNe{f} push-button is soldered.
There are \num{2} connections to the \cNe{f} push-button.  If any one of these
is disconnected then the problem is likely one of connection and \textit{not}
due to the \cNe{f} push-button itself being broken.

\par\medskip

The side of the cable that is connected to the circuit board is a very secure
connection, however, it is possible that a solder joint that connects the
female connector to the circuit board has failed.

\par\medskip

The problem may also be due to the circuitry that does switch debouncing.

%%%%%%%%%%%%%%%%%%%%%%%%%%%%%%%%%%%%%%%%%%%%%%%%%%%%%%%%%%%%%%%%%%%%%%%%%%%%%%%%
% Controls - Previous
%%%%%%%%%%%%%%%%%%%%%%%%%%%%%%%%%%%%%%%%%%%%%%%%%%%%%%%%%%%%%%%%%%%%%%%%%%%%%%%%
\subsubsection{Previous}

\sD{!!!6} \sD{C.PrE.}

\par\bigskip

The side of the cable that is connected to the \cPr{f} push-button is soldered.
There are \num{2} connections to the \cPr{f} push-button.  If any one of these
is disconnected then the problem is likely one of connection and \textit{not}
due to the \cPr{f} push-button itself being broken.

\par\medskip

The side of the cable that is connected to the circuit board is a very secure
connection, however, it is possible that a solder joint that connects the
female connector to the circuit board has failed.

\par\medskip

The problem may also be due to the circuitry that does switch debouncing.

%%%%%%%%%%%%%%%%%%%%%%%%%%%%%%%%%%%%%%%%%%%%%%%%%%%%%%%%%%%%%%%%%%%%%%%%%%%%%%%%
% Beeper
%%%%%%%%%%%%%%%%%%%%%%%%%%%%%%%%%%%%%%%%%%%%%%%%%%%%%%%%%%%%%%%%%%%%%%%%%%%%%%%%
\subsection{Beeper}

\sD{!!!7} \sD{BEEP}

\par\bigskip

The \cBe{f} is soldered directly to the circuit board.  If it is loose then
it's a problem of connection, otherwise it has failed.

%%%%%%%%%%%%%%%%%%%%%%%%%%%%%%%%%%%%%%%%%%%%%%%%%%%%%%%%%%%%%%%%%%%%%%%%%%%%%%%%
% Screens
%%%%%%%%%%%%%%%%%%%%%%%%%%%%%%%%%%%%%%%%%%%%%%%%%%%%%%%%%%%%%%%%%%%%%%%%%%%%%%%%
\subsection{Screens}

%%%%%%%%%%%%%%%%%%%%%%%%%%%%%%%%%%%%%%%%%%%%%%%%%%%%%%%%%%%%%%%%%%%%%%%%%%%%%%%%
% Screens - Display
%%%%%%%%%%%%%%%%%%%%%%%%%%%%%%%%%%%%%%%%%%%%%%%%%%%%%%%%%%%%%%%%%%%%%%%%%%%%%%%%
\subsubsection{Display}

\sD{!!!8} \sD{dISP.}

\par\bigskip

The \cDi{f} is actually working, at least in part, if you see this error.
It indicates a problem with the \textbf{I$^2$C} communication bus between the
\cDi{f} and the microcontroller.

\par\medskip

The cable connection to both the \cDi{f} and circuit board is are very
secure connections, however, it is possible that a solder joint that connects
the female connector to one or both has failed.

%%%%%%%%%%%%%%%%%%%%%%%%%%%%%%%%%%%%%%%%%%%%%%%%%%%%%%%%%%%%%%%%%%%%%%%%%%%%%%%%
% Screens - Lighting
%%%%%%%%%%%%%%%%%%%%%%%%%%%%%%%%%%%%%%%%%%%%%%%%%%%%%%%%%%%%%%%%%%%%%%%%%%%%%%%%
\subsubsection{Lighting}

\sD{!!!9} \sD{LEdS}

\par\bigskip

There are \num{2} rows of \num{8} LEDs in each row that make up the \cLi{f}.
Each row or strip is soldered to a small circuit board.  These connections
may be the problem for the failure.

\par\medskip

The cable connection to both the \cLi{f} and circuit board is are very
secure connections, however, it is possible that a solder joint that connects
the female connector to one or both has failed.

%%%%%%%%%%%%%%%%%%%%%%%%%%%%%%%%%%%%%%%%%%%%%%%%%%%%%%%%%%%%%%%%%%%%%%%%%%%%%%%%
% Touch Sensor
%%%%%%%%%%%%%%%%%%%%%%%%%%%%%%%%%%%%%%%%%%%%%%%%%%%%%%%%%%%%%%%%%%%%%%%%%%%%%%%%
\subsection{Touch Sensor}

\sD{!!10} \sD{tUCH}

\par\bigskip

There is a wire connecting the \cTS{f} to the microcontroller.  The terminal
connecting to the \cTS{f} is a ring terminal held in place by a screw.  Make
sure this is tight.

\par\medskip

Otherwise, the cable may be severed.

%%%%%%%%%%%%%%%%%%%%%%%%%%%%%%%%%%%%%%%%%%%%%%%%%%%%%%%%%%%%%%%%%%%%%%%%%%%%%%%%
% Filesystem or Micro SD Card
%%%%%%%%%%%%%%%%%%%%%%%%%%%%%%%%%%%%%%%%%%%%%%%%%%%%%%%%%%%%%%%%%%%%%%%%%%%%%%%%
\subsection{Filesystem or Micro SD Card}

\sD{!!11} \sD{FILE}

\par\bigskip

This could mean that either:

\begin{enumerate}
  \item The filesystem on the \cMSD{f} is not formatted as \mono{FAT32} with
    \num{512} bytes / sector, \textit{or}
  \item The filesystem is corrupted and/or the \cMSD{f} is bad.
\end{enumerate}

If you have just replaced the \cMSD{f}, it may mean that it was formatted
incorrectly.  If you haven't replaced the \cMSD{f}, then it will likely need
replacing.  Refer to \hyperref[Removing SD Card]{Removing the Micro SD Card}
for instructions.

%%%%%%%%%%%%%%%%%%%%%%%%%%%%%%%%%%%%%%%%%%%%%%%%%%%%%%%%%%%%%%%%%%%%%%%%%%%%%%%%
% Audio Decoder or Amplifier
%%%%%%%%%%%%%%%%%%%%%%%%%%%%%%%%%%%%%%%%%%%%%%%%%%%%%%%%%%%%%%%%%%%%%%%%%%%%%%%%
\subsection{Audio Decoder or Amplifier}

\sD{!!12} \sD{Aud.!}

\par\bigskip

This likely means that the audio decoder or amplifier has failed.

%%%%%%%%%%%%%%%%%%%%%%%%%%%%%%%%%%%%%%%%%%%%%%%%%%%%%%%%%%%%%%%%%%%%%%%%%%%%%%%%
% Audio
%%%%%%%%%%%%%%%%%%%%%%%%%%%%%%%%%%%%%%%%%%%%%%%%%%%%%%%%%%%%%%%%%%%%%%%%%%%%%%%%
\section{Audio}

These errors may or may not be recoverable and may or may not be hardware
issues.

%%%%%%%%%%%%%%%%%%%%%%%%%%%%%%%%%%%%%%%%%%%%%%%%%%%%%%%%%%%%%%%%%%%%%%%%%%%%%%%%
% Audio - Disabled
%%%%%%%%%%%%%%%%%%%%%%%%%%%%%%%%%%%%%%%%%%%%%%%%%%%%%%%%%%%%%%%%%%%%%%%%%%%%%%%%
\subsection{Audio Disabled}

\sD{!!13} \sD{PLAY}

\par\bigskip

This error indicates that the \mAu{f} has been \textit{disabled} due to one of
the following:

\begin{table}[H]
\ers{0.1}
\centering
\begin{tabu}{c}
  \symD{!!11} \symD{FILE} \\
  \symD{!!12} \symD{Aud.!} \\
  \symD{!!14} \symD{P.FIL.} \\
  \symD{!!15} \symD{P.OPE.} \\
  \symD{!!16} \symD{P.Aud.} \\
\end{tabu}
\end{table}

You will see one of the above errors \textit{first}, then this error indicating
that the \mAu{f} has been disabled and is unusable.

%%%%%%%%%%%%%%%%%%%%%%%%%%%%%%%%%%%%%%%%%%%%%%%%%%%%%%%%%%%%%%%%%%%%%%%%%%%%%%%%
% Audio - Files
%%%%%%%%%%%%%%%%%%%%%%%%%%%%%%%%%%%%%%%%%%%%%%%%%%%%%%%%%%%%%%%%%%%%%%%%%%%%%%%%
\subsection{Audio Files}

\par\bigskip

\begin{table}[H]
\ers{3.0}
\begin{tabu}{X[1,c,m] X[4,l,m]}
  \mrule
  \sD{!!14} \sD{P.FIL.}
    & There is a problem obtaining the audio files from the \cMSD{f}. \\ \drule{2}
  \sD{!!15} \sD{P.OPE.}
    & There is a problem opening an audio file that is on the the \cMSD{f}. \\ \drule{2}
  \sD{!!16} \sD{P.Aud.}
    & There is a problem communicating with the audio decoder or a problem
      reading an audio file that is on the the \cMSD{f}. \\
  \mrule
\end{tabu}
\end{table}

These are likely due to one of the following:

\begin{enumerate}
  \item The \cMSD{f} is not formatted correctly or is failing.
  \item There is a problem with the audio decoder.
\end{enumerate}

If you have just replaced the \cMSD{f}, it may mean that it was formatted
incorrectly.  If you haven't replaced the \cMSD{f}, then try replacing it.
Refer to \hyperref[Removing SD Card]{Removing the Micro SD Card} for
instructions.

\par\medskip

If the above doesn't solve the problem, then it likely means that the audio
decoder has failed.

%%%%%%%%%%%%%%%%%%%%%%%%%%%%%%%%%%%%%%%%%%%%%%%%%%%%%%%%%%%%%%%%%%%%%%%%%%%%%%%%
% Timer
%%%%%%%%%%%%%%%%%%%%%%%%%%%%%%%%%%%%%%%%%%%%%%%%%%%%%%%%%%%%%%%%%%%%%%%%%%%%%%%%
\section{Timer}

\sD{!!17} \sD{T.PIt.}

\par\bigskip

This error indicates that a timer could not be acquired.  It should
never happen and indicates a bug in the software.

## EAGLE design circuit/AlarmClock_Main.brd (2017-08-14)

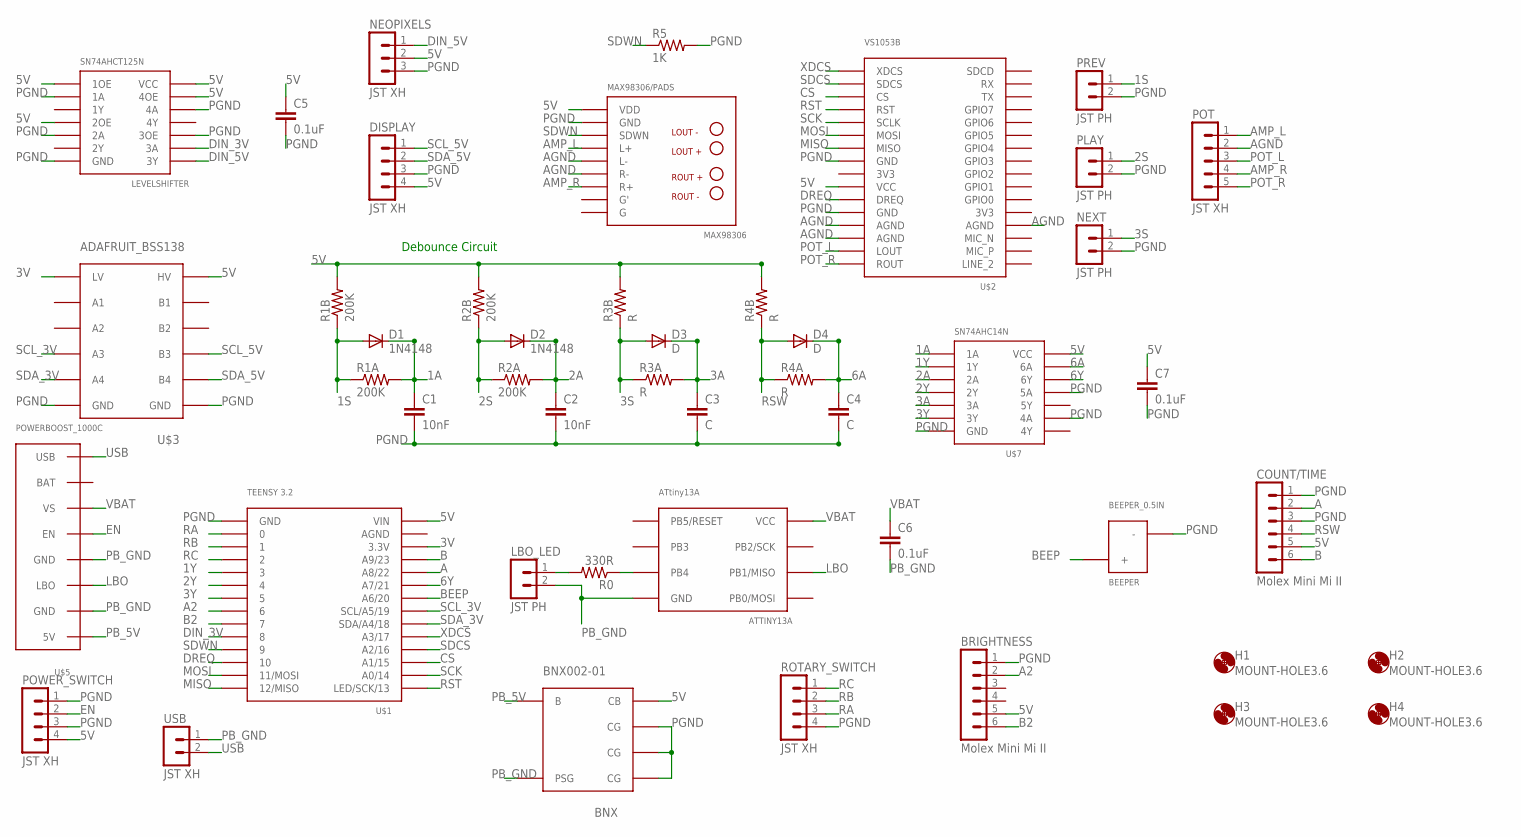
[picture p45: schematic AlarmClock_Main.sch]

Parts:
ATTINY13A: ATtiny13A; ATTINY13A
BEEPER: BEEPER_0.5IN
BNX002-01: BNX; BNX002-01
BRIGHTNESS: Molex Mini Mi II; 55447-0670
C1, C2: 10nF; CAPACITOR_0.1IN
C3, C4: C; CAPACITOR_0.1IN
C5, C6, C7: 0.1uF; CAPACITOR_0.1IN
COUNT/TIME: Molex Mini Mi II; 55454-0670
D1, D2: 1N4148
D3, D4: D; 1N4148
DISPLAY: JST XH; B4B-XH-A
H1, H2, H3, H4: MOUNT-HOLE3.6; 3,6
LBO_LED: JST PH; B2B-PH-K-S
LEVELSHIFTER: SN74AHCT125N
MAX98306: MAX98306/PADS; MAX98306
NEOPIXELS: JST XH; B3B-XH-A
NEXT: JST PH; B2B-PH-K-S
PLAY: JST PH; B2B-PH-K-S
POT: JST XH; B5B-XH-A
POWER_SWITCH: JST XH; B4B-XH-A
PREV: JST PH; B2B-PH-K-S
R0: 330R; RESISTOR_0.15IN
R1A, R1B, R2A, R2B: 200K; RESISTOR_0.15IN
R3A, R3B, R4A, R4B: R; RESISTOR_0.15IN
R5: 1K; RESISTOR_0.15IN
ROTARY_SWITCH: JST XH; B4B-XH-A
U$1: TEENSY 3.2; TEENSY-3.1
U$2: VS1053B
U$3: ADAFRUIT_BSS138
U$5: POWERBOOST_1000C
U$7: SN74AHC14N
USB: JST XH; B2B-XH-A

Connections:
1A: C1.P$1 (1), D1.C, R1A.2, U$7.1A
1S: D1.A, PREV.1, R1A.1, R1B.1
1Y: U$1.3, U$7.1Y
2A: C2.P$1 (1), D2.C, R2A.2, U$7.2A
2S: D2.A, PLAY.1, R2A.1, R2B.1
2Y: U$1.4, U$7.2Y
3A: C3.P$1 (1), D3.C, R3A.2, U$7.3A
3S: D3.A, NEXT.1, R3A.1, R3B.1
3V: U$1.3.3V, U$3.LV
3Y: U$1.5, U$7.3Y
5V: BNX002-01.CB, BRIGHTNESS.5, C5.P$1 (1), C7.P$1 (1), COUNT/TIME.5, DISPLAY.4, LEVELSHIFTER.1OE, LEVELSHIFTER.2OE, LEVELSHIFTER.4OE, LEVELSHIFTER.VCC@1 (VCC), MAX98306.VDD@1 (VDD), NEOPIXELS.2, POWER_SWITCH.4, R1B.2, R2B.2, R3B.2, R4B.2, U$1.VIN, U$2.VCC, U$3.HV, U$7.VCC@1 (VCC)
6A: C4.P$1 (1), D4.C, R4A.2, U$7.6A
6Y: U$1.A7/21, U$7.6Y
A: COUNT/TIME.2, U$1.A8/22
A2: BRIGHTNESS.2, U$1.6
AGND: MAX98306.L-, MAX98306.R-, POT.2, U$2.AGND@1 (AGND), U$2.AGND@2 (AGND), U$2.AGND@3 (AGND)
AMP_L: MAX98306.L+, POT.1
AMP_R: MAX98306.R+, POT.4
B: COUNT/TIME.6, U$1.A9/23
B2: BRIGHTNESS.6, U$1.7
BEEP: BEEPER.+, U$1.A6/20
CS: U$1.A1/15, U$2.CS
DIN_3V: LEVELSHIFTER.3A, U$1.8
DIN_5V: LEVELSHIFTER.3Y, NEOPIXELS.1
DREQ: U$1.10, U$2.DREQ
EN: POWER_SWITCH.2, U$5.P$EN (EN)
LBO: ATTINY13A.PB1/MISO, U$5.P$LBO (LBO)
MISO: U$1.12/MISO, U$2.MISO
MOSI: U$1.11/MOSI, U$2.MOSI
unnamed: LBO_LED.1, R0.2
unnamed: ATTINY13A.PB4, R0.1
PB_5V: BNX002-01.B, U$5.P$5V (5V)
PB_GND: ATTINY13A.GND, BNX002-01.PSG, C6.P$2 (2), LBO_LED.2, U$5.P$GND@1 (GND), U$5.P$GND@2 (GND), USB.1
PGND: BEEPER.-, BNX002-01.CG@1 (CG), BNX002-01.CG@2 (CG), BNX002-01.CG@3 (CG), BRIGHTNESS.1, C1.P$2 (2), C2.P$2 (2), C3.P$2 (2), C4.P$2 (2), C5.P$2 (2), C7.P$2 (2), COUNT/TIME.1, COUNT/TIME.3, DISPLAY.3, LEVELSHIFTER.1A, LEVELSHIFTER.2A, LEVELSHIFTER.3OE, LEVELSHIFTER.4A, LEVELSHIFTER.GND@1 (GND), MAX98306.GND@1 (GND), NEOPIXELS.3, NEXT.2, PLAY.2, POWER_SWITCH.1, POWER_SWITCH.3, PREV.2, R5.2, ROTARY_SWITCH.4, U$1.GND, U$2.GND@1 (GND), U$2.GND@2 (GND), U$3.GND@1 (GND), U$3.GND@2 (GND), U$7.4A, U$7.5A, U$7.GND@1 (GND)
POT_L: POT.3, U$2.LOUT
POT_R: POT.5, U$2.ROUT
RA: ROTARY_SWITCH.3, U$1.0
RB: ROTARY_SWITCH.2, U$1.1
RC: ROTARY_SWITCH.1, U$1.2
RST: U$1.LED/SCK/13, U$2.RST
RSW: COUNT/TIME.4, D4.A, R4A.1, R4B.1
SCK: U$1.A0/14, U$2.SCLK
SCL_3V: U$1.SCL/A5/19, U$3.A3
SCL_5V: DISPLAY.1, U$3.B3
SDA_3V: U$1.SDA/A4/18, U$3.A4
SDA_5V: DISPLAY.2, U$3.B4
SDCS: U$1.A2/16, U$2.SDCS
SDWN: MAX98306.SDWN, R5.1, U$1.9
USB: U$5.P$USB (USB), USB.2
VBAT: ATTINY13A.VCC, C6.P$1 (1), U$5.P$VS (VS)
XDCS: U$1.A3/17, U$2.XDCS

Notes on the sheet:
Debounce Circuit

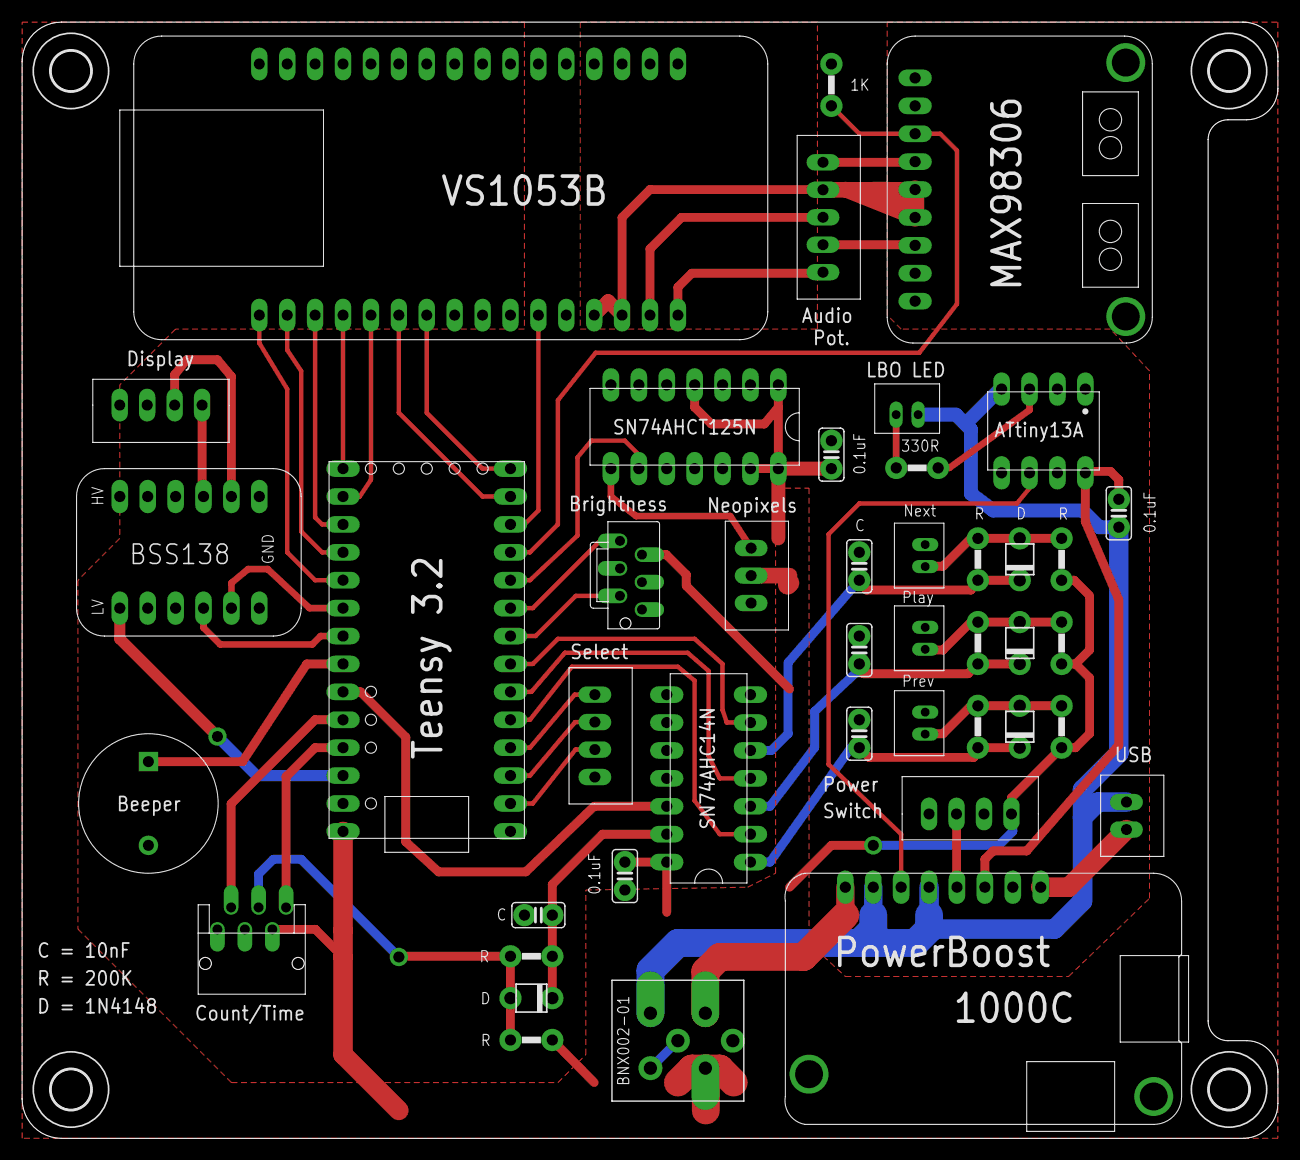
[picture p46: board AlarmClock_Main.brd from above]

Board: 2 copper layers, 114.3 x 101.6 mm, 47 parts (0 on the bottom side), 51 nets.

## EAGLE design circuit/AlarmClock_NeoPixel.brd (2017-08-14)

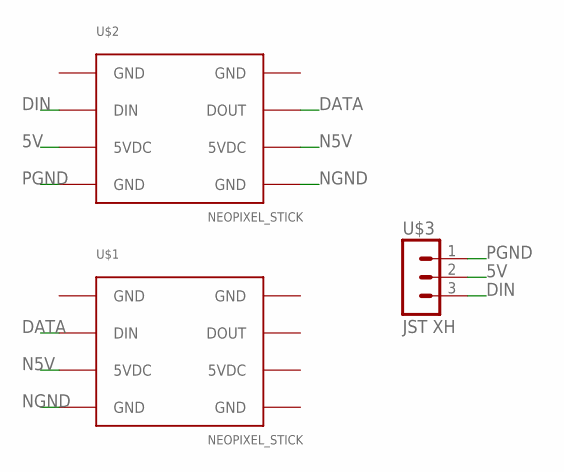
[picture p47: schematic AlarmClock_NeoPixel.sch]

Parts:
U$1, U$2: NEOPIXEL_STICK; NEOPIXEL_STICK_SMD_SHORT/HOLES
U$3: JST XH; B3B-XH-A

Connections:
5V: U$2.5VDC@1 (5VDC), U$3.2
5VDC: U$1.5VDC@2 (5VDC)
DATA: U$1.DIN, U$2.DOUT
DIN: U$2.DIN, U$3.3
GND: U$1.GND@1 (GND), U$1.GND@3 (GND), U$1.GND@4 (GND), U$2.GND@1 (GND), U$2.GND@3 (GND)
N5V: U$1.5VDC@1 (5VDC), U$2.5VDC@2 (5VDC)
NGND: U$1.GND@2 (GND), U$2.GND@4 (GND)
PGND: U$2.GND@2 (GND), U$3.1

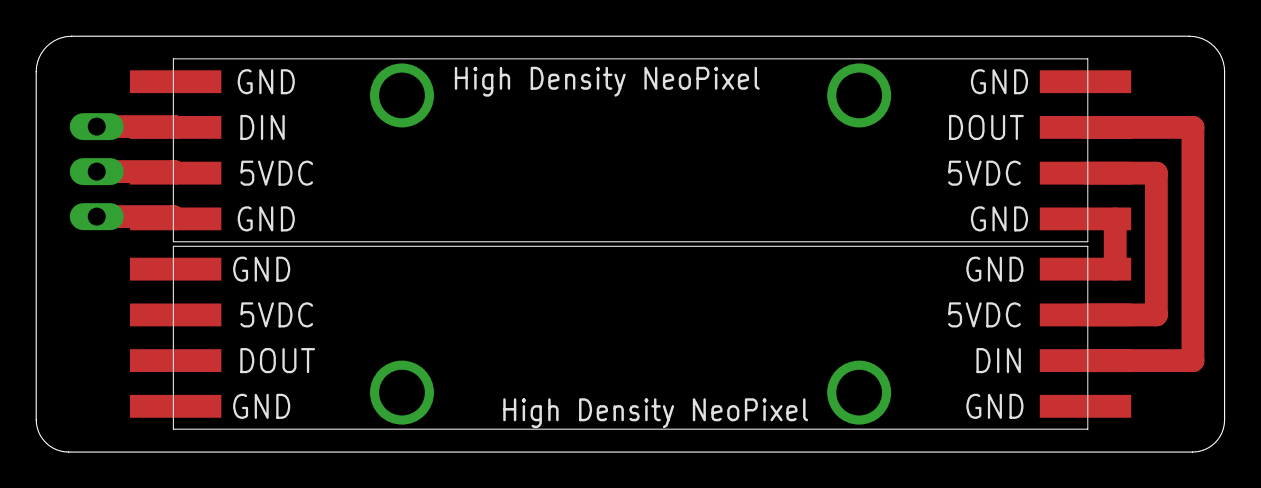
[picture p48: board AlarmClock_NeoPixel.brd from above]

Board: 2 copper layers, 66.0 x 23.1 mm, 3 parts (1 on the bottom side), 7 nets.

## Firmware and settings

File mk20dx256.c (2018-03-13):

/*******************************************************************************
 * Teensyduino Core Library
 * http://www.pjrc.com/teensy/
 * Copyright (c) 2017 PJRC.COM, LLC.
 *
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
 * 2. If the Software is incorporated into a build system that allows selection
 * among a list of target devices, then similar target devices manufactured by
 * PJRC.COM must be included in the list of target devices and selectable in the
 * same manner.
 *
 * THE SOFTWARE IS PROVIDED "AS IS", WITHOUT WARRANTY OF ANY KIND, EXPRESS OR
 * IMPLIED, INCLUDING BUT NOT LIMITED TO THE WARRANTIES OF MERCHANTABILITY,
 * FITNESS FOR A PARTICULAR PURPOSE AND NONINFRINGEMENT. IN NO EVENT SHALL THE
 * AUTHORS OR COPYRIGHT HOLDERS BE LIABLE FOR ANY CLAIM, DAMAGES OR OTHER
 * LIABILITY, WHETHER IN AN ACTION OF CONTRACT, TORT OR OTHERWISE, ARISING FROM,
 * OUT OF OR IN CONNECTION WITH THE SOFTWARE OR THE USE OR OTHER DEALINGS IN THE
 * SOFTWARE.
 ******************************************************************************/

#include <errno.h>
#include <stdint.h>

// Flash Security Setting. On Teensy 3.2, you can lock the MK20 chip to prevent
// anyone from reading your code.  You CAN still reprogram your Teensy while
// security is set, but the bootloader will be unable to respond to auto-reboot
// requests from Arduino. Pressing the program button will cause a full chip
// erase to gain access, because the bootloader chip is locked out.  Normally,
// erase occurs when uploading begins, so if you press the Program button
// accidentally, simply power cycling will run your program again.  When
// security is locked, any Program button press causes immediate full erase.
// Special care must be used with the Program button, because it must be made
// accessible to initiate reprogramming, but it must not be accidentally
// pressed when Teensy Loader is not being used to reprogram.  To set lock the
// security change this to 0xDC.  Teensy 3.0 and 3.1 do not support security lock.
#define FSEC 0xDE

// Flash Options
#define FOPT 0xF9

extern unsigned long _stext;
extern unsigned long _etext;
extern unsigned long _sdata;
extern unsigned long _edata;
extern unsigned long _sbss;
extern unsigned long _ebss;
extern unsigned long _estack;

extern int main(void);

static void start_clocks(void);
void __libc_init_array(void);

void fault_isr(void)
{
#define SIM_SCGC5  (*(volatile uint32_t *)0x40048038)
#define SIM_SCGC5_PORTC  ((uint32_t)0x00000800)
#define PORTC_PCR5  (*(volatile uint32_t *)0x4004B014)
#define PORT_PCR_MUX(n)  ((uint32_t)(((n) & 7) << 8))
#define PORT_PCR_DSE     ((uint32_t)0x00000040)
#define PORT_PCR_SRE     ((uint32_t)0x00000004)
#define GPIOC_PDDR  (*(volatile uint32_t *)0x400FF094)
#define GPIOC_PSOR  (*(volatile uint32_t *)0x400FF084)
#define GPIOC_PTOR  (*(volatile uint32_t *)0x400FF08C)

    // Blink pin 13 LED on the Teensy3
    SIM_SCGC5 |= SIM_SCGC5_PORTC;
    PORTC_PCR5 = PORT_PCR_MUX(1) | PORT_PCR_DSE | PORT_PCR_SRE;
    GPIOC_PDDR |= (1 << 5);

    while (1)
    {
        uint32_t us = 1000000;
        GPIOC_PSOR = (1 << 5);

        for (int i = 0; i < 4; i++)
        {
            us *= F_CPU / 2000000;

            __asm__ volatile
                (
                 "L_%=_delay_usecs:\n\t"
                 "subs %0, #1\n\t"
                 "bne L_%=_delay_usecs\n\t" : "+r" (us)
                );

            us = 100000;
            GPIOC_PTOR = (1 << 5);
        }
    }

    while (1);
}

void unused_isr(void) { fault_isr(); }

// ARM Core System Handler Vectors
void ResetHandler(void);  // Set as the Initial Program Counter
void nmi_isr(void)             __attribute__ ((weak, alias("unused_isr")));
void hard_fault_isr(void)      __attribute__ ((weak, alias("fault_isr")));
void memmanage_fault_isr(void) __attribute__ ((weak, alias("fault_isr")));
void bus_fault_isr(void)       __attribute__ ((weak, alias("fault_isr")));
void usage_fault_isr(void)     __attribute__ ((weak, alias("fault_isr")));
void svcall_isr(void)          __attribute__ ((weak, alias("unused_isr")));
void debugmonitor_isr(void)    __attribute__ ((weak, alias("unused_isr")));
void pendablesrvreq_isr(void)  __attribute__ ((weak, alias("unused_isr")));
void systick_isr(void)         __attribute__ ((weak, alias("unused_isr")));

// Freescale Kinetis K20 - MK20DX256VLH7 - ARM Cortex-M4
// ARM NVIC Handler Vectors

// eDMA
void dma_ch0_isr(void)   __attribute__ ((weak, alias("unused_isr")));
void dma_ch1_isr(void)   __attribute__ ((weak, alias("unused_isr")));
void dma_ch2_isr(void)   __attribute__ ((weak, alias("unused_isr")));
void dma_ch3_isr(void)   __attribute__ ((weak, alias("unused_isr")));
void dma_ch4_isr(void)   __attribute__ ((weak, alias("unused_isr")));
void dma_ch5_isr(void)   __attribute__ ((weak, alias("unused_isr")));
void dma_ch6_isr(void)   __attribute__ ((weak, alias("unused_isr")));
void dma_ch7_isr(void)   __attribute__ ((weak, alias("unused_isr")));
void dma_ch8_isr(void)   __attribute__ ((weak, alias("unused_isr")));
void dma_ch9_isr(void)   __attribute__ ((weak, alias("unused_isr")));
void dma_ch10_isr(void)  __attribute__ ((weak, alias("unused_isr")));
void dma_ch11_isr(void)  __attribute__ ((weak, alias("unused_isr")));
void dma_ch12_isr(void)  __attribute__ ((weak, alias("unused_isr")));
void dma_ch13_isr(void)  __attribute__ ((weak, alias("unused_isr")));
void dma_ch14_isr(void)  __attribute__ ((weak, alias("unused_isr")));
void dma_ch15_isr(void)  __attribute__ ((weak, alias("unused_isr")));
void dma_error_isr(void) __attribute__ ((weak, alias("unused_isr")));

// FTFL
void flash_cmd_isr(void)   __attribute__ ((weak, alias("unused_isr")));
void flash_error_isr(void) __attribute__ ((weak, alias("unused_isr")));

// PMC
void low_voltage_isr(void) __attribute__ ((weak, alias("unused_isr")));

// LLWU
void wakeup_isr(void)      __attribute__ ((weak, alias("unused_isr")));

// WDOG or EWM
void watchdog_isr(void)    __attribute__ ((weak, alias("unused_isr")));

// I2C
void i2c0_isr(void) __attribute__ ((weak, alias("unused_isr")));
void i2c1_isr(void) __attribute__ ((weak, alias("unused_isr")));

// SPI
void spi0_isr(void) __attribute__ ((weak, alias("unused_isr")));
void spi1_isr(void) __attribute__ ((weak, alias("unused_isr")));

// FlexCAN
void can0_message_isr(void) __attribute__ ((weak, alias("unused_isr")));
void can0_bus_off_isr(void) __attribute__ ((weak, alias("unused_isr")));
void can0_error_isr(void)   __attribute__ ((weak, alias("unused_isr")));
void can0_tx_warn_isr(void) __attribute__ ((weak, alias("unused_isr")));
void can0_rx_warn_isr(void) __attribute__ ((weak, alias("unused_isr")));
void can0_wakeup_isr(void)  __attribute__ ((weak, alias("unused_isr")));

// I2S
void i2s0_tx_isr(void) __attribute__ ((weak, alias("unused_isr")));
void i2s0_rx_isr(void) __attribute__ ((weak, alias("unused_isr")));

// UART
void uart0_lon_isr(void)    __attribute__ ((weak, alias("unused_isr")));
void uart0_status_isr(void) __attribute__ ((weak, alias("unused_isr")));
void uart0_error_isr(void)  __attribute__ ((weak, alias("unused_isr")));
void uart1_status_isr(void) __attribute__ ((weak, alias("unused_isr")));
void uart1_error_isr(void)  __attribute__ ((weak, alias("unused_isr")));
void uart2_status_isr(void) __attribute__ ((weak, alias("unused_isr")));
void uart2_error_isr(void)  __attribute__ ((weak, alias("unused_isr")));

// ADC
void adc0_isr(void) __attribute__ ((weak, alias("unused_isr")));
void adc1_isr(void) __attribute__ ((weak, alias("unused_isr")));

// CMP
void cmp0_isr(void) __attribute__ ((weak, alias("unused_isr")));
void cmp1_isr(void) __attribute__ ((weak, alias("unused_isr")));
void cmp2_isr(void) __attribute__ ((weak, alias("unused_isr")));

// FTM
void ftm0_isr(void) __attribute__ ((weak, alias("unused_isr")));
void ftm1_isr(void) __attribute__ ((weak, alias("unused_isr")));
void ftm2_isr(void) __attribute__ ((weak, alias("unused_isr")));

// CMT
void cmt_isr(void) __attribute__ ((weak, alias("unused_isr")));

// RTC
void rtc_alarm_isr(void)   __attribute__ ((weak, alias("unused_isr")));
void rtc_seconds_isr(void) __attribute__ ((weak, alias("unused_isr")));

// PIT
void pit0_isr(void) __attribute__ ((weak, alias("unused_isr")));
void pit1_isr(void) __attribute__ ((weak, alias("unused_isr")));
void pit2_isr(void) __attribute__ ((weak, alias("unused_isr")));
void pit3_isr(void) __attribute__ ((weak, alias("unused_isr")));

// PDB
void pdb_isr(void) __attribute__ ((weak, alias("unused_isr")));

// USB OTG
void usb_isr(void) __attribute__ ((weak, alias("unused_isr")));

// USB Charger Detect
void usb_charge_isr(void) __attribute__ ((weak, alias("unused_isr")));

// DAC
void dac0_isr(void) __attribute__ ((weak, alias("unused_isr")));

// TSI
void tsi0_isr(void) __attribute__ ((weak, alias("unused_isr")));

// MCG
void mcg_isr(void) __attribute__ ((weak, alias("unused_isr")));

// LPTMR
void lptmr_isr(void) __attribute__ ((weak, alias("unused_isr")));

// PORT
void porta_isr(void) __attribute__ ((weak, alias("unused_isr")));
void portb_isr(void) __attribute__ ((weak, alias("unused_isr")));
void portc_isr(void) __attribute__ ((weak, alias("unused_isr")));
void portd_isr(void) __attribute__ ((weak, alias("unused_isr")));
void porte_isr(void) __attribute__ ((weak, alias("unused_isr")));

// Can only be pended or cleared via the NVIC registers
void software_isr(void) __attribute__ ((weak, alias("unused_isr")));

__attribute__ ((section(".flashconfig"), used))
uint8_t const flashconfigbytes[16] =
{
    0xFF, 0xFF, 0xFF, 0xFF, 0xFF, 0xFF, 0xFF, 0xFF,
    0xFF, 0xFF, 0xFF, 0xFF, FSEC, FOPT, 0xFF, 0xFF
};

#define NVIC_NUM_INTERRUPTS  95

__attribute__ ((section(".dmabuffers"), used, aligned(512)))
void (* _VectorsRam[NVIC_NUM_INTERRUPTS + 16])(void);

__attribute__ ((section(".vectors"), used))
void (* const _VectorsFlash[NVIC_NUM_INTERRUPTS + 16])(void) =
{
    // ARM core
    (void (*)(void))((unsigned long)&_estack), //  0 ARM: Initial Stack Pointer
    ResetHandler,         //  1 ARM: Initial Program Counter
    nmi_isr,              //  2 ARM: Non-maskable Interrupt (NMI)
    hard_fault_isr,       //  3 ARM: Hard Fault
    memmanage_fault_isr,  //  4 ARM: MemManage Fault
    bus_fault_isr,        //  5 ARM: Bus Fault
    usage_fault_isr,      //  6 ARM: Usage Fault

    fault_isr,            //  7 --
    fault_isr,            //  8 --
    fault_isr,            //  9 --
    fault_isr,            // 10 --

    svcall_isr,           // 11 ARM: Supervisor call (SVCall)
    debugmonitor_isr,     // 12 ARM: Debug Monitor

    fault_isr,            // 13 --

    pendablesrvreq_isr,   // 14 ARM: Pendable req serv(PendableSrvReq)
    systick_isr,          // 15 ARM: System tick timer (SysTick)

    // eDMA
    dma_ch0_isr,   // 16 DMA channel 0 transfer complete
    dma_ch1_isr,   // 17 DMA channel 1 transfer complete
    dma_ch2_isr,   // 18 DMA channel 2 transfer complete
    dma_ch3_isr,   // 19 DMA channel 3 transfer complete
    dma_ch4_isr,   // 20 DMA channel 4 transfer complete
    dma_ch5_isr,   // 21 DMA channel 5 transfer complete
    dma_ch6_isr,   // 22 DMA channel 6 transfer complete
    dma_ch7_isr,   // 23 DMA channel 7 transfer complete
    dma_ch8_isr,   // 24 DMA channel 8 transfer complete
    dma_ch9_isr,   // 25 DMA channel 9 transfer complete
    dma_ch10_isr,  // 26 DMA channel 10 transfer complete
    dma_ch11_isr,  // 27 DMA channel 11 transfer complete
    dma_ch12_isr,  // 28 DMA channel 12 transfer complete
    dma_ch13_isr,  // 29 DMA channel 13 transfer complete
    dma_ch14_isr,  // 30 DMA channel 14 transfer complete
    dma_ch15_isr,  // 31 DMA channel 15 transfer complete
    dma_error_isr, // 32 DMA error interrupt channel

    unused_isr, // 33 --

    // FTFL
    flash_cmd_isr,   // 34 Flash Memory Command complete
    flash_error_isr, // 35 Flash Read collision

    // PMC
    low_voltage_isr, // 36 Low-voltage detect/warning

    // LLWU
    wakeup_isr, // 37 Low Leakage Wakeup

    // WDOG or EWM
    watchdog_isr, // 38 Both EWM and WDOG interrupt

    unused_isr, // 39 --

    // I2C
    i2c0_isr, // 40 I2C0
    i2c1_isr, // 41 I2C1

    // SPI
    spi0_isr, // 42 SPI0
    spi1_isr, // 43 SPI1

    unused_isr, // 44 --

    // FlexCAN
    can0_message_isr, // 45 CAN OR'ed Message buffer (0-15)
    can0_bus_off_isr, // 46 CAN Bus Off
    can0_error_isr,   // 47 CAN Error
    can0_tx_warn_isr, // 48 CAN Transmit Warning
    can0_rx_warn_isr, // 49 CAN Receive Warning
    can0_wakeup_isr,  // 50 CAN Wake Up

    // I2S
    i2s0_tx_isr, // 51 I2S0 Transmit
    i2s0_rx_isr, // 52 I2S0 Receive

    unused_isr, // 53 --
    unused_isr, // 54 --
    unused_isr, // 55 --
    unused_isr, // 56 --
    unused_isr, // 57 --
    unused_isr, // 58 --
    unused_isr, // 59 --

    // UART
    uart0_lon_isr,    // 60 UART0 CEA709.1-B (LON) status
    uart0_status_isr, // 61 UART0 status
    uart0_error_isr,  // 62 UART0 error
    uart1_status_isr, // 63 UART1 status
    uart1_error_isr,  // 64 UART1 error
    uart2_status_isr, // 65 UART2 status
    uart2_error_isr,  // 66 UART2 error

    unused_isr, // 67 --
    unused_isr, // 68 --
    unused_isr, // 69 --
    unused_isr, // 70 --
    unused_isr, // 71 --
    unused_isr, // 72 --

    // ADC
    adc0_isr, // 73 ADC0
    adc1_isr, // 74 ADC1

    // CMP
    cmp0_isr, // 75 CMP0
    cmp1_isr, // 76 CMP1
    cmp2_isr, // 77 CMP2

    // FTM
    ftm0_isr, // 78 FTM0
    ftm1_isr, // 79 FTM1
    ftm2_isr, // 80 FTM2

    // CMT
    cmt_isr, // 81 CMT

    // RTC
    rtc_alarm_isr,   // 82 RTC Alarm interrupt
    rtc_seconds_isr, // 83 RTC Seconds interrupt

    // PIT
    pit0_isr, // 84 PIT Channel 0
    pit1_isr, // 85 PIT Channel 1
    pit2_isr, // 86 PIT Channel 2
    pit3_isr, // 87 PIT Channel 3

    // PDB
    pdb_isr, // 88 PDB Programmable Delay Block

    // USB OTG
    usb_isr, // 89 USB OTG

    // USBDCD
    usb_charge_isr, // 90 USB Charger Detect

    unused_isr, // 91 --
    unused_isr, // 92 --
    unused_isr, // 93 --
    unused_isr, // 94 --
    unused_isr, // 95 --
    unused_isr, // 96 --

    // DAC
    dac0_isr, // 97 DAC0

    unused_isr, // 98 --

    // TSI
    tsi0_isr, // 99 TSI0

    // MCG
    mcg_isr, // 100 MCG

    // LPTMR
    lptmr_isr, // 101 Low Power Timer

    unused_isr, // 102 --

    // PORT
    porta_isr, // 103 Pin detect (Port A)
    portb_isr, // 104 Pin detect (Port B)
    portc_isr, // 105 Pin detect (Port C)
    portd_isr, // 106 Pin detect (Port D)
    porte_isr, // 107 Pin detect (Port E)

    unused_isr, // 108 --
    unused_isr, // 109 --

    software_isr  // 110 Software interrupt
};

__attribute__ ((section(".startup"), optimize("-Os")))
void ResetHandler(void)
{
    ////////////////////////////////////////////////////////////////////////////
    // Watchdog requires that an unlock sequence be initiated within 256 bus
    // clocks after reset - this is the Watchdog configuration time (WCT).
    // After initiation the sequence must be completed within 20 bus clock
    // cycles.  Then configuration of the WDOG must complete within the WCT.
    // Failing any of these, the system will reset.  Additionally, a wait of
    // at least one bus clock after the unlock sequence is required before
    // configuration.

#define WDOG_UNLOCK  (*(volatile uint16_t *)0x4005200E)
#define WDOG_UNLOCK_SEQ1  ((uint16_t)0xC520)
#define WDOG_UNLOCK_SEQ2  ((uint16_t)0xD928)
#define WDOG_STCTRLH  (*(volatile uint16_t *)0x40052000)
#define WDOG_STCTRLH_ALLOWUPDATE  ((uint16_t)0x0010)

    WDOG_UNLOCK = WDOG_UNLOCK_SEQ1;
    WDOG_UNLOCK = WDOG_UNLOCK_SEQ2;
    // A couple of NOPs to make sure a bus cycle passes before configuration.
    __asm__ volatile ("nop");
    __asm__ volatile ("nop");
    // Just configure to allow update using the refresh sequence.
    WDOG_STCTRLH = WDOG_STCTRLH_ALLOWUPDATE;
    ////////////////////////////////////////////////////////////////////////////

#define PMC_REGSC         (*(volatile uint8_t  *)0x4007D002)
#define PMC_REGSC_ACKISO  ((uint8_t)0x08)

    // Release I/O pins hold, if we woke up from VLLS mode
    if (PMC_REGSC & PMC_REGSC_ACKISO)
        PMC_REGSC |= PMC_REGSC_ACKISO;

#define SMC_PMPROT       (*(volatile uint8_t  *)0x4007E000)
#define SMC_PMPROT_AVLP  ((uint8_t)0x20)
#define SMC_PMPROT_ALLS  ((uint8_t)0x08)
#define SMC_PMPROT_AVLLS ((uint8_t)0x02)

    // Since this is a write once register, make it visible to all F_CPU's
    // so we can into other sleep modes in the future at any speed.
    SMC_PMPROT = SMC_PMPROT_AVLP | SMC_PMPROT_ALLS | SMC_PMPROT_AVLLS;

    ////////////////////////////////////////////////////////////////////////////
    // FLASH -> RAM

    // Copy .fastrun and .data sections from FLASH to RAM
    for (int i = 0; i < (&_edata - &_sdata); i++)
        (&_sdata)[i] = (&_etext)[i];

    // Initialize uninitialized data to zero
    for (int i = 0; i < (&_ebss - &_sbss); i++)
        (&_sbss)[i] = 0;

    // Copy vector table that's in FLASH to RAM
    for (int i = 0; i < NVIC_NUM_INTERRUPTS + 16; i++)
        _VectorsRam[i] = _VectorsFlash[i];

#define SCB_VTOR  (*(volatile uint32_t *)0xE000ED08)

    // Use vector table that was just copied to RAM
    SCB_VTOR = (uint32_t)_VectorsRam;
    ////////////////////////////////////////////////////////////////////////////

    start_clocks();  // Gets from FEI to PEE mode

    // I don't think this is necessary since PRIMASK is set to zero on reset
    // anyway.  It's just an alias for "CPSIE i" which sets the PRIMASK to zero.
    //__enable_irq();

    __libc_init_array();  // Run the deferred C library initialization

    main();

    while (1);
}

static void start_clocks(void)
{
#define OSC0_CR  (*(volatile uint8_t *)0x40065000)
#define OSC_SC8P     ((uint8_t)0x02)
#define OSC_SC2P     ((uint8_t)0x08)
#define OSC_ERCLKEN  ((uint8_t)0x80)

#define MCG_C1  (*(uint8_t volatile *)0x40064000)
#define MCG_C1_FRDIV(n)  (uint8_t)(((n) & 0x07) << 3)
#define MCG_C1_CLKS(n)   (uint8_t)(((n) & 0x03) << 6)

#define MCG_C2  (*(uint8_t volatile *)0x40064001)
#define MCG_C2_RANGE0(n)  (uint8_t)(((n) & 0x03) << 4)
#define MCG_C2_EREFS      (uint8_t)0x04

#define MCG_C5  (*(uint8_t volatile *)0x40064004)
#define MCG_C5_PRDIV0(n)  (uint8_t)((n) & 0x1F)

#define MCG_C6  (*(uint8_t volatile *)0x40064005)
#define MCG_C6_VDIV0(n)  (uint8_t)((n) & 0x1F)
#define MCG_C6_PLLS      (uint8_t)0x40

#define MCG_S  (*(uint8_t volatile *)0x40064006)
#define MCG_S_OSCINIT0    (uint8_t)0x02
#define MCG_S_CLKST(n)    (uint8_t)(((n) & 0x03) << 2)
#define MCG_S_CLKST_MASK  (uint8_t)0x0C
#define MCG_S_IREFST      (uint8_t)0x10
#define MCG_S_PLLST       (uint8_t)0x20
#define MCG_S_LOCK0       (uint8_t)0x40

    ////////////////////////////////////////////////////////////////////////////
    // Hardware always starts in FEI mode //////////////////////////////////////
    ////////////////////////////////////////////////////////////////////////////
    //  C1[CLKS] bits are written to 00
    //  C1[IREFS] bit is written to 1
    //  C6[PLLS] bit is written to 0
    // MCG_SC[FCDIV] defaults to divide by two for internal ref clock
    // I tried changing MSG_SC to divide by 1, it didn't work for me
    ////////////////////////////////////////////////////////////////////////////

    // Enable capacitors for crystal
    OSC0_CR = OSC_SC8P | OSC_SC2P | OSC_ERCLKEN;

    // Enable osc, 8-32 MHz range, low power mode
    MCG_C2 = MCG_C2_RANGE0(2) | MCG_C2_EREFS;

    // Switch to crystal as clock source, FLL input = 16 MHz / 512
    MCG_C1 =  MCG_C1_CLKS(2) | MCG_C1_FRDIV(4);

    // Wait for crystal oscillator to begin
    while ((MCG_S & MCG_S_OSCINIT0) == 0);

    // Wait for FLL to use oscillator
    while ((MCG_S & MCG_S_IREFST) != 0);

    // Wait for MCGOUT to use oscillator
    while ((MCG_S & MCG_S_CLKST_MASK) != MCG_S_CLKST(2));

    ////////////////////////////////////////////////////////////////////////////
    // Now in FBE mode /////////////////////////////////////////////////////////
    ////////////////////////////////////////////////////////////////////////////
    //  C1[CLKS] bits are written to 10
    //  C1[IREFS] bit is written to 0
    //  C1[FRDIV] must be written to divide xtal to 31.25-39 kHz
    //  C6[PLLS] bit is written to 0
    //  C2[LP] is written to 0
    // If we need faster than the crystal, turn on the PLL
    ////////////////////////////////////////////////////////////////////////////

#if F_CPU == 72000000
    MCG_C5 = MCG_C5_PRDIV0(5);  // config PLL input for 16 MHz Crystal / 6 = 2.667 Hz
#else
    MCG_C5 = MCG_C5_PRDIV0(3);  // config PLL input for 16 MHz Crystal / 4 = 4 MHz
#endif

#if F_CPU == 96000000 || F_CPU == 48000000
    MCG_C6 = MCG_C6_PLLS | MCG_C6_VDIV0(0);  // config PLL for 96 MHz output
#else  // F_CPU == 72000000
    MCG_C6 = MCG_C6_PLLS | MCG_C6_VDIV0(3);  // config PLL for 72 MHz output
#endif

    // wait for PLL to start using xtal as its input
    while (!(MCG_S & MCG_S_PLLST));

    // wait for PLL to lock
    while (!(MCG_S & MCG_S_LOCK0));

    ////////////////////////////////////////////////////////////////////////////
    // Now in PBE mode /////////////////////////////////////////////////////////
    ////////////////////////////////////////////////////////////////////////////

#define SIM_CLKDIV1  (*(volatile uint32_t *)0x40048044)
#define SIM_CLKDIV1_OUTDIV1(n)  ((uint32_t)(((n) & 0x0F) << 28))
#define SIM_CLKDIV1_OUTDIV2(n)  ((uint32_t)(((n) & 0x0F) << 24))
#define SIM_CLKDIV1_OUTDIV4(n)  ((uint32_t)(((n) & 0x0F) << 16))
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

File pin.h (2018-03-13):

#ifndef _PIN_H_
#define _PIN_H_

#include "types.h"
#include "module.h"
#include "utility.h"

#define PIN_RS_R         0 // Rotary Switch - Right
#define PIN_RS_L         1 // Rotary Switch - Left
#define PIN_RS_M         2 // Rotary Switch - Middle
#define PIN_PREV         3 // Play previous audio file buttion
#define PIN_PLAY         4 // Play / Pause button
#define PIN_NEXT         5 // Play next audio file button
#define PIN_EN_BR_A      6 // Rotary Encoder A - Brightness
#define PIN_EN_BR_B      7 // Rotary Encoder B - Brightness
#define PIN_NEO          8 // Neopixel strip
#define PIN_AMP_SDWN     9 // Amplifier Shutdown
#define PIN_VS_DREQ     10 // VS1053 Data Request
#define PIN_MOSI        11 // SPI - MOSI / DOUT
#define PIN_MISO        12 // SPI - MISO / DIN
#define PIN_VS_RST      13 // VS1053 Hardware Reset
#define PIN_SCK         14 // SPI - SCK
#define PIN_VS_CS       15 // SPI - VS1053 Command Chip Select (SCI)
#define PIN_SD_CS       16 // SPI - SD Chip Select
#define PIN_VS_DCS      17 // SPI - VS1053 Data Chip Select (SDI)
#define PIN_SDA         18 // I2C - SDA  (7-Segment Display)
#define PIN_SCL         19 // I2C - SCL  (7-Segment Display)
#define PIN_BEEPER      20 // Beeper
#define PIN_EN_SW       21 // Rotary Encoder Switch
#define PIN_EN_A        22 // Rotary Encoder A
#define PIN_EN_B        23 // Rotary Encoder B
#define PIN_CNT         24 // Number of digital pins
#define PIN_TOUCH       25 // Touch - Alarm snooze : uses touchRead()

#define PORT_PCR_ISF     (1 << 24)
#define PORT_PCR_IRQC(i) ((uint32_t)((i) & 0x0F) << 16)
#define PORT_PCR_MUX(m)  ((uint32_t)((m) & 0x07) <<  8)
#define PORT_PCR_DSE     (1 << 6)
#define PORT_PCR_ODE     (1 << 5)
#define PORT_PCR_PFE     (1 << 4)
#define PORT_PCR_SRE     (1 << 2)
#define PORT_PCR_PE      (1 << 1)
#define PORT_PCR_PS      (1 << 0)

extern "C"
{
    void porta_isr(void);
    void portb_isr(void);
    void portc_isr(void);
    void portd_isr(void);
    void porte_isr(void);
}

////////////////////////////////////////////////////////////////////////////////
// Teensy pin to Port and Port pins ////////////////////////////////////////////
////////////////////////////////////////////////////////////////////////////////
enum port_e : uint32_t { PORTA, PORTB, PORTC, PORTD, PORTE };

constexpr port_e const port_map[] =
{
    PORTB /* 0 16*/, PORTB /* 1 17*/, PORTD /* 2  0*/, PORTA /* 3 12*/,
    PORTA /* 4 13*/, PORTD /* 5  7*/, PORTD /* 6  4*/, PORTD /* 7  2*/,
    PORTD /* 8  3*/, PORTC /* 9  3*/, PORTC /*10  4*/, PORTC /*11  6*/,
    PORTC /*12  7*/, PORTC /*13  5*/, PORTD /*14  1*/, PORTC /*15  0*/,
    PORTB /*16  0*/, PORTB /*17  1*/, PORTB /*18  3*/, PORTB /*19  2*/,
    PORTD /*20  5*/, PORTD /*21  6*/, PORTC /*22  1*/, PORTC /*23  2*/,
    PORTA /*24  5*/, PORTB /*25 19*/, PORTE /*26  1*/, PORTC /*27  9*/,
    PORTC /*28  8*/, PORTC /*29 10*/, PORTC /*30 11*/, PORTE /*31  0*/,
    PORTB /*32 18*/, PORTA /*33  4*/,
};

constexpr uint8_t const pin_map[] =
{
    16 /* 0 PTB*/, 17 /* 1 PTB*/,  0 /* 2 PTD*/, 12 /* 3 PTA*/,
    13 /* 4 PTA*/,  7 /* 5 PTD*/,  4 /* 6 PTD*/,  2 /* 7 PTD*/,
     3 /* 8 PTD*/,  3 /* 9 PTC*/,  4 /*10 PTC*/,  6 /*11 PTC*/,
     7 /*12 PTC*/,  5 /*13 PTC*/,  1 /*14 PTD*/,  0 /*15 PTC*/,
     0 /*16 PTB*/,  1 /*17 PTB*/,  3 /*18 PTB*/,  2 /*19 PTB*/,
     5 /*20 PTD*/,  6 /*21 PTD*/,  1 /*22 PTC*/,  2 /*23 PTC*/,
     5 /*24 PTA*/, 19 /*25 PTB*/,  1 /*26 PTE*/,  9 /*27 PTC*/,
     8 /*28 PTC*/, 10 /*29 PTC*/, 11 /*30 PTC*/,  0 /*31 PTE*/,
    18 /*32 PTB*/,  4 /*33 PTA*/,
};

////////////////////////////////////////////////////////////////////////////////
// PORT registers //////////////////////////////////////////////////////////////
////////////////////////////////////////////////////////////////////////////////
class Isr;

class PORT
{
    friend class Isr;
    protected:
        static reg32 pcr(pin_t p)  { return _s_pcr_base  + ((port_map[p] * 0x0400) + pin_map[p]); }
        static reg32 isfr(pin_t p) { return _s_isfr_base + ((port_map[p] * 0x8000) + pin_map[p]); }
    private:
        static reg32 _s_pcr_base;
        static reg32 _s_isfr_base;
};

////////////////////////////////////////////////////////////////////////////////
// Isr /////////////////////////////////////////////////////////////////////////
////////////////////////////////////////////////////////////////////////////////
enum irqc_e : uint32_t
{
    IRQC_DISABLED     = 0x00,
    IRQC_DMA_RISING   = 0x01,
    IRQC_DMA_FALLING  = 0x02,
    IRQC_DMA_CHANGE   = 0x03,
  //IRQC_RES0         = 0x04,  // Reserved
  //IRQC_RES1         = 0x05,
  //IRQC_RES2         = 0x06,
  //IRQC_RES3         = 0x07,
    IRQC_INTR_LOW     = 0x08,
    IRQC_INTR_RISING  = 0x09,
    IRQC_INTR_FALLING = 0x0A,
    IRQC_INTR_CHANGE  = 0x0B,
    IRQC_INTR_HIGH    = 0x0C,
    IRQC_MASK         = 0x0F,
};

template < port_e > class Port;
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

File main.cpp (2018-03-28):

#include "armv7m.h"
#include "utility.h"
#include "ui.h"

extern "C" int main(void)
{
    SysTick::start(TICKS_PER_MSEC);
    NVIC::init();

    // ~1170us wait else cycle count doesn't increment - wait for a bit longer
    delay_msecs(10);

    UI & ui = UI::acquire();

    while (true)
        ui.process();

    return 0;
}

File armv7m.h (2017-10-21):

#ifndef _ARMV7M_H_
#define _ARMV7M_H_

#include "types.h"

////////////////////////////////////////////////////////////////////////////////
// System Control Space (SCS) //////////////////////////////////////////////////
////////////////////////////////////////////////////////////////////////////////

////////////////////////////////////////////////////////////////////////////////
// System Control Block (SCB) //////////////////////////////////////////////////
////////////////////////////////////////////////////////////////////////////////
#define SCB_SCR_SLEEPDEEP   (1 << 2)
#define SCB_ICSR_PENDSTSET  (1 << 26)

enum except_e
{
    //EXCEPT_NOT           =  0,
    EXCEPT_RESET         =  1,
    EXCEPT_NMI           =  2,
    EXCEPT_HARD_FAULT    =  3,
    EXCEPT_MEM_MANAGE    =  4,
    EXCEPT_BUS_FAULT     =  5,
    EXCEPT_USAGE_FAULT   =  6,
    //EXCEPT_RSVD_7        =  7,
    //EXCEPT_RSVD_8        =  8,
    //EXCEPT_RSVD_9        =  9,
    //EXCEPT_RSVD_10       = 10,
    EXCEPT_SV_CALL       = 11,
    EXCEPT_DEBUG_MONITOR = 12,
    //EXCEPT_RSVD_13       = 13,
    EXCEPT_PEND_SV       = 14,
    EXCEPT_SYS_TICK      = 15,
};

class SCB
{
    public:
        static void setPriority(except_e e, uint8_t priority)
        {
            if (e < EXCEPT_MEM_MANAGE) return;
            _s_shpr_base[e - 4] = priority;
        }

        static int getPriority(except_e e)
        {
            switch (e)
            {
                case EXCEPT_RESET:      return -3;
                case EXCEPT_NMI:        return -2;
                case EXCEPT_HARD_FAULT: return -1;
                default:                return _s_shpr_base[e - 4];
            }
        }

        static bool sysTickIntrPending(void) { return *_s_icsr & SCB_ICSR_PENDSTSET; }
        static void setSleepDeep(void) { *_s_scr |= SCB_SCR_SLEEPDEEP; }
        static void clearSleepDeep(void) { *_s_scr &= ~SCB_SCR_SLEEPDEEP; }
        static int executionPriority(void);

    private:
        static reg32 _s_base;
        static const reg32 _s_cpuid;
        static reg32 _s_icsr;
        static reg32 _s_vtor;
        static reg32 _s_aircr;
        static reg32 _s_scr;
        static reg32 _s_ccr;
        static reg32 _s_shpr1;
        static reg32 _s_shpr2;
        static reg32 _s_shpr3;
        static reg8 _s_shpr_base;
        static reg32 _s_shcsr;
        static reg32 _s_cfsr;
        static reg32 _s_hfsr;
        static reg32 _s_dfsr;
        static reg32 _s_mmfar;
        static reg32 _s_bfar;
        static reg32 _s_afsr;
        static reg32 _s_cpacr;
        static reg32 _s_fp_base;
        static reg32 _s_fpccr;
        static reg32 _s_fpcar;
        static reg32 _s_fpdscr;
        static const reg32 _s_mvfr0;
        static const reg32 _s_mvfr1;
        static const reg32 _s_mvfr2;
};

////////////////////////////////////////////////////////////////////////////////
// The system timer (SysTick) //////////////////////////////////////////////////
////////////////////////////////////////////////////////////////////////////////
#define SYST_CSR_ENABLE     (1 <<  0)
#define SYST_CSR_TICKINT    (1 <<  1)
#define SYST_CSR_CLKSOURCE  (1 <<  2)
#define SYST_CSR_COUNTFLAG  (1 << 16)

#define TICKS_PER_MSEC  (F_CPU / 1000)
#define TICKS_PER_USEC  (F_CPU / 1000000)

extern "C" void systick_isr(void);

class SysTick
{
    friend void systick_isr(void);

    public:
        static void start(void) { start(_s_rv, _s_pri); }
        static void start(uint32_t rv) { start(rv, _s_pri); }
        static void start(uint32_t rv, uint8_t priority)  // rv -> Reload Value
        {
            _s_rv = rv;
            _s_pri = priority;

            if (*_s_csr & SYST_CSR_ENABLE)
                stop();

            SCB::setPriority(EXCEPT_SYS_TICK, priority);

            *_s_rvr = rv;
            *_s_cvr = 0;
            *_s_csr = SYST_CSR_ENABLE | SYST_CSR_TICKINT | SYST_CSR_CLKSOURCE;
        }

        static void stop(void) { *_s_csr = 0; }

        static uint32_t currentValue(void) { return *_s_cvr; }
        static uint32_t reloadValue(void) { return *_s_rvr; }
        static uint32_t intervals(void) { return _s_intervals; }
        static void intervals(uint32_t m) { stop(); _s_intervals += m; start(); }

    private:
        static constexpr uint8_t const _s_def_pri = 32;
        static constexpr uint32_t const _s_def_rv = TICKS_PER_MSEC;
        static uint8_t _s_pri;
        static uint32_t _s_rv;
        static v32 _s_intervals;

        static reg32 _s_base;
        static reg32 _s_csr;
        static reg32 _s_rvr;
        static reg32 _s_cvr;
        static reg32 _s_calib;
};
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

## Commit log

2017-08-16 * Added Reg class to ease getting, setting and clearing bits and fields in a register. Created for use with DMA which has a lot of registers and fields to deal with (though I've currently scrapped th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
2017-08-16 Add ATtiny13A low battery hex file so I don't have to worry about having development environment to compile.
2017-08-21 Update 7-Segment display brightness to be in sync with LED brightness when going from off to on.
2017-08-24 Display and RTC fixes - Display * Don't automatically turn display on if sleeping or off when showing. Fixes case where brightness is turned down to the point of being off and UI clock update turns i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
    [display.h, ui.cpp, ui.h]
2017-08-24 Timer updates and SetTimer fix * Fix display underflow condition in SetTimer when minutes is 0 and seconds is 0. Set seconds to 1 if so before entering set seconds state. * Add capability to show clo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
    [ui.cpp, ui.h]
2017-08-27 Display, Opti and UI updates - Display * Update to allow string and integer functions to allow displaying from a position for so many digits. * Add an option function for showing a string, colon and 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
    [display.h, opti.h]
2017-08-27 Display and UI updates - Display * Add function to display bars, i.e. underscores, dashes and overscores, and the number of bars starting from the bottom or if reversed starting from the top. * Updat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
    [display.h, ui.cpp, ui.h]
2017-08-29 UI, Opti, Pin and Elecmech updates - Opti * Add Palette class and update Leds class to display palettes * Add pseudo-random function rand8() - UI * Add Lighting class to handle night light, timer lig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
    [opti.h, pin.h, ui.cpp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]
2017-08-29 UI updates * Add state press time and change press time variable names to reflect the likely action/state that they corresponds to. * Add press state and change press state names to reflect the likel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
    [ui.cpp, ui.h]
2017-08-29 UI Lighting fix * Use member setBrightness in constructor so member _brightness gets set.
    [ui.cpp]
2017-08-30 Display, UI, Llwu, Pin, Elecmech and Makefile updates - Display * Change wake() and sleep() methods to take "redisplay" and "clear" parameters, respectively. If sleep(true) then the display will be c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
    [display.h, llwu.h, pin.h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]
2017-09-03 Audio, Display, Eeprom, Tsi an UI updates - Audio - DevBeeper * Update stop() to disable toggle. * Override Toggle on() and off() to also check for pin being set. - DevAudio * Remove delay code that 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
    [audio.h, display.h, ui.cpp]
2017-09-05 Touch Calibration, Tsi, UI and Elecmech updates - Elecmech * Update evUpdate() to use static_cast so that enums can be passed in. - Tsi * Use interrupt for End of Scan so read() and touched() don't b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
    [ui.cpp, ui.h]
2017-09-06 UI (Player, Clock and Touch) and Toggle updates Add ability in Clock state to set a specific numbered track for Player to play. - Player * Change newTrack() to take an int32_t instead of int16_t as a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
2017-09-19 Display, Eeprom, Tsi and UI updates - Display * Keep track of last displayed and don't redisplay if new is the same as last. - Eeprom * Use 16-bit writes instead of 32-bit writes to save on space. Pe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
2017-09-19 UI update * Reset _refresh_start to 0 if state changed so uisRefresh() isn't called unnecessarily.
    [ui.cpp]
2017-09-19 UI Timer Update * If Player has control of display, call Timer uisWait() if it's in RUNNING or ALERT state so it will alert if it counts down to zero, but just not update display. Do this in pressing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
2017-09-20 UI Touch Fix * Fix uisReset() to exclude TS_OPT and include TS_READ and TS_DONE states and to turn lighting off.
    [ui.cpp]
2017-09-21 UI updates * Forcibly wake if Player is stopping or skipping * Don't stop Timer alerting on encoder turn.
    [ui.cpp]
2017-09-23 Display Fix and Display, Eeprom, Llwu, Rtc, Tsi and UI updates - Display * Fix setString() when digit position is not DP_0. * Fix setString() so BL flags are honored when not DF_BL. * Add setOption()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
    [display.h, llwu.h]
2017-09-23 UI Timer update * For Timer uisReset() go to set time state if <= WAIT and WAIT otherwise.
2017-09-23 UI updates * Rename Touch class to SetTouch. * Reorganize interface since removal of SetTimer: ------------------------------------------------------ || || MODE || ||---------------------------------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
2017-09-26 UI SetTouch Fixes and Updates - SetTouch uisReset() fixes and uisBegin() / reset() updates * Fix case for TS_READ to go back to initial read state. * Fix case for TS_CONF when it's at TS_CAL_START to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
    [ui.cpp]
2017-09-26 Alarm Fix * Rename AS_ON state to AS_WAKE. * Fix "Total Alarm Time" check to be checked in AS_SNOOZE state as well as AS_WAKE. Check was only being done in AS_WAKE state. Should also be checked in AS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
    [ui.cpp, ui.h]
2017-09-29 Alarm Update and Audio, Display, Elecmech, Llwu, Lptmr, Rtc and UI Updates - TODO * Refactor UI sleep functionality. * Make sure Alarm beeper isn't going off when Timer is alerting or when calibratin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
    - Audio
    * Add macro to possibly use softReset() in finish() instead of running the
    entire function. There seems to be a lag between tracks which I think
    might be due to the fact that it ends up calling softReset() anyway
    after sending a couple thousand bytes. Need to test before enabling macro.
    - Display
    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
2017-09-29 UI Updates and Fix * Fix to display clock when SL_RESTING and in UIS_CLOCK state. * Add SL_SLEEPING sleep state. * Add reset() member function to Controls. * Consolidate error handling and add beginn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
    [ui.cpp, ui.h]
2017-09-30 UI Updates * Remove Touch class and move touch sensing into Controls class * Remove skip methods from Controls.
    [ui.cpp, ui.h]
2017-10-01 Eeprom, Llwu and UI Updates - Eeprom * Non-templatize read() since it's now only reading 16-bit values. * Change Sleep to Power and have settings for nap, player stop and sleep. - Llwu * Add check fo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
    [llwu.h, ui.cpp, ui.h]
2017-10-01 UI Clock Update * Change show track touch time to 2000 ms. * Reset toggle time if still touched and track not updated.
    [ui.cpp, ui.h]
2017-10-02 UI Power Updates - Eeprom * Add touch_secs field to ePower struct and update getPower() and setPower(). - UI - Controls * Update interaction() method to take a bool parameter indicating whether or no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
2017-10-03 UI Timer Fix * Fix Timer to display correctly after nap or sleep.
    [ui.cpp, ui.h]
2017-10-04 UI SetTouch Fix * Tsi is using software triggered scan and read() starts a scan if there isn't a scan already in progress and returns 0 until the end of scan then returns the results of the scan. Bot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
    [ui.cpp, ui.h]
2017-10-04 UI Update * Move SetTouch to rotary switch LEFT / Tertiary mode. * Mode SetPower to rotary switch RIGHT / Secondary mode.
2017-10-07 UI SetTouch Update * Don't reset menu option when resetting state. * Add decimals for abbreviated menu options.
    [ui.cpp, ui.h]
2017-10-10 UI, Display, Opti, Eeprom and Elecmech updates - Display * Add setTimer() and showTimer() methods to Seg7Display that take seconds as an argument. - Eeprom * Update to allow for 3 configurable night 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
    [display.h, opti.h, ui.cpp]
2017-10-10 UI Timer update * When showing the clock, show the timer for 3 seconds when pausing or resuming.
2017-10-11 UI Lighting fix * Only turn night light back on from other states if the color isn't black so default color doesn't get activated, since one way besides pressing and holding the encoder switch is to 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
    [ui.cpp]
2017-10-12 UI, Display and Opti Updates - Display * Don't treat on/off and awake/sleep as different. If off(), put in STANDBY and on() WAKEUP and ON. Removes unnecessary complication. * Set br_e enum values to 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
    [display.h, opti.h, ui.cpp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]
2017-10-12 UI updates - Timer * Add capability, using touch, to turn the countdown lighting on/off. * Update uisPower() to not sleep, even on touch event, if running or alerting. - Power * Don't need to reset m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
    [ui.cpp, ui.h]
2017-10-15 UI Alarm/Power Fix
    Power was stopping Player via auto stop functionality when Alarm was awake and
    wake source was music since it wasn't updating the _stop_mark in
    RTC::alarmIsAwake() check.
    * Elecmech
    - DevBeeper
    * Unvirtualize start() and stop() since they don't need to be and add
    running() method.
    * UI
    - Timer
    * Only stop beeper if Alarm isn't using it.
    * Start beeper if it isn't running since Alarm may have turned it off if
    a race condition occurred.
    - SetTouch
    * Only stop and player beeper if Alarm isn't using them.
    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
    [audio.h, ui.cpp, ui.h]
2017-10-15 UI updates * Don't use previously set values when entering Set states but read fresh from Eeprom. * Lower done blink time from 800 to 700 milliseconds. - SetAlarm * Only save on uisEnd() if time was 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
    [ui.cpp, ui.h]
2017-10-15 UI Lighting Fix * Night light animation -> solid color was not toggling from off state and animation was stopping instead of changing to solid color. In toggleAni() shouldn't check if lighting is on,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
    [ui.cpp]
2017-10-17 UI Power, Timer, SetTouch and Alarm Fixes * In wakeScreens(), if _brightness == 0, which will happen if user turned brightness knob down to the point of being off before sleep or nap occurred, set br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
    [ui.cpp, ui.h]
2017-10-18 UI Clock, SetPower and Power updates - Controls * In reset(), reset touch values as well as other control values. - SetPower * If a time is 0, meaning it's disabled, show "OFF" instead of 0 in displa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
    [ui.cpp, ui.h]
2017-10-18 UI Clock fixes * Add a wait to touch so if user should be touching the top long enough to show track, then presses encoder switch while still touching top, the state doesn't go from CS_SHOW_TRACK to 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
    [ui.cpp, ui.h]
2017-10-21 UI fixes, SysTick and Rtc updates - SysTick * Change init() to start() and add overloaded start() methods that take no arguments, reload value or reload value and priority as arguments. Use defaults 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
    [armv7m.h, main.cpp, opti.h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]
2017-11-12 UI SetAlarm Fix * Make sure hour isn't saved if it was updated, but then alarm is disabled.
    [ui.cpp]
2017-11-14 UI Update * Make errors "recoverable", i.e. only one error per power cycle is displayed. Makes it so user is made aware of a problem, but can still use the device if problem doesn't render device unu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
    [ui.cpp, ui.h]
2017-11-14 Add section to Audio refering to Clock about direct track selection.
2017-11-15 Display Fix * Don't set brightness in constructor to avoid or at least lessen the chance of remnants being displayed.
    [display.h]
2017-11-15 Add multi-action case to Symbols.
2017-11-15 Change "Changing" to "Replacing" for Coin Cell Battery.
2017-11-16 Rename directory hardware -> circuit. Add Fusion 360 files.
    [AlarmClock_Main.brd, AlarmClock_Main.sch, AlarmClock_NeoPixel.brd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]
2017-11-18 Add sections to Parts & Materials. Change Component to Application.
2017-11-19 Sync Power with Clock Nap and Sleep states. Various rewording and reformatting.
2017-11-22 Add bug that I've been unable to reproduce to Troubleshooting section. Clarify a couple of troubleshooting items.
2017-11-23 Fix copy/paste typo. Use module font in a couple of places.
2017-11-27 Audio Update * Make finishing incremental so 32 bytes are sent at a time instead of potentially 4100 bytes at once. Prevents potential UI unresponsiveness between songs. * Do finish() when next song 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
    [audio.h]
2017-12-04 Alarm Fix * In Alarm constructor, stop Alarm if in progress when device is turned on.
    [ui.cpp]
2017-12-09 Add mounting hardware for Display and Lighting.
2017-12-24 Add Hex Driver as accessory.
2018-02-04 Fix typo. Remove SIM_CLKDIV1_OUTDIV3 since it doesn't exist for this MCU.
    [mk20dx256.c]
2018-03-26 DMA initial commit & updates to Disk, Scsi, Usb and SPI
    TODO: Implement handling of possible errors with DMA and SD
    DMA
    * Added DMA capability
    DevDisk
    * Added methods pure virtual methods open(), read(), write() and close() for
    use with a disk descriptor.
    DevSD
    * Moved most macros into enums and refactored code.
    * Added DiskDesc class using DMA to write and read data from SD card over SPI.
    * Implemented open(), read(), write() and close() virtual methods using
    DiskDesc class as disk descriptor.
    * Added CRC7 functionality.
    Scsi
    * Remove SCSI_PASSED macro and return 0 for success or no data processed.
    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
    [dev.h, disk.h, dma.h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]
2018-03-28 USB / UI integration * Makefile - Add USB_ENABLED preprocessor flag * DevDisk / DevSD - Add error reporting - Calls to produce() and consume() need not be IRQ protected since both _produced and _cons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
    [dev.h, disk.h, file.h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]
2018-04-28 Added sorting of songs using external sorting. * Since the user can now see files on OS when connected via USB and since the OS sorts the files, added sorting capability to match what the user sees. 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
2018-05-01 File fixes * Fix writing more than one cluster. * Move table lookup buffers out of file and into filesystem and better keep track of sector loaded. * Fix EOC check. * Add additional checks for bad in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
    [file.h]
2018-05-01 Disk fix * Account for possiblity that a read or write is smaller than the DMA chunk size. If stalled, only resume if canProduce() or canConsume().
    [disk.h]
2018-05-01 Usb update * Don't make Usb NVIC interrupt higher priority.
2018-05-03 File and String fixes * File - Fix issue where '.' and '..' entries were not being omitted in read(), specifically '..' where the cluster was zero causing the entry to be set free. Properly check and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
    [file.h]
2018-05-05 File fixes and updates * Fix issue where new directory entry is added but next is not set to last entry. * Use FsInfo next_free when looking for free cluster. * Add additional error checks.
    [file.h]
2018-05-08 Scsi & Usb update * Handle device USBMS ejection.
2018-05-08 Player update * Don't allow Player to operate while USB connected to avoid potential file corruption and read errors.
    [ui.cpp, ui.h]
2018-05-12 Usb & Scsi updates * Scsi - Change active to initially be false and ejected state as an event. * Usb - Only reset Scsi upon enabling BulkOnlyIface if it hasn't been ejected. - Update connected() stat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
    [ui.cpp, usb.h]
2018-05-12 File & UI update * File - Seperate sorting and writing list of sorted files. * UI - Change reload action in Player to list sorted files since reloading automatically occurs after Usb eject. - Create 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
    [file.h, ui.cpp, ui.h]
2018-05-23 Usb & UI update * Reconnect after lising files so user can see/print new list
